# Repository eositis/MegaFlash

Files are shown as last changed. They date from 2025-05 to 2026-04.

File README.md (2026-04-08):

# MegaFlash for Apple IIc/IIc+

MegaFlash is an internal storage device for Apple IIc/IIc plus computer.

MegaFlash-New

## Feature List

- 128MB/256MB Capacity, divided into 4/8 ProDOS Drives
- 256kB RAM Disk on Pico 2 (RP2350); 140kB on Pico W (RP2040)
- ROM Disk for Disaster Recovery
- 256kB Slinky Emulation on stock firmware
- Boot Menu (Similar to ROM4X/5X)
- Control Panel
- Real Time Clock with ProDOS clock driver
- Network Time Sync (NTP Client)
- Upload/Download ProDOS Image file via WIFI and TFTP Server
- Upload/Download ProDOS Image file via XModem and USB serial port
- FPU for Applesoft BASIC
- Bug fixes of System ROM and Applesoft

A brief [user guide](https://github.com/eositis/MegaFlash/blob/main/MegaFlash%20for%20a2s4000%20installation%20guide.pdf) is available for more information.

## Requirement
- Apple IIc computer with Memory Expansion Card connector or
- Apple IIc plus computer

System ROM replacement is required for MegaFlash to function.

## Hardware
The hardware is quite simple.  All the hard work is handled by Pi Pico.  Apple 65C02 CPU only needs to copy data between RAM and Pico. Schematic is available [here](./kicad/rev1.0/schematic-rev1.0.pdf).

- Raspberry Pi Pico2 W
- Winbond 25Q01 NOR Flash memory
- GAL16V8 PLD for address decode
- 5V to 3.3V Logic Level Shifter

## Project Directories

There are 3 software projects. There is not enough space in Apple ROM to store the Control Panel program.  The program is stored in Pico flash memory. 

`firmware` Project Directory of Apple ROM Patches\
`cpanel` Control Panel project\
`pico` Raspberry Pi Pico firmware\
`common` Common header files used by all 3 projects

## Sponsorship

MegaFlash development for commercial sale has been partly sponsored by PCBway. Preparing products for commercial release is expensive, often requiring board respins to resolve manufacturing and logistics issues. PCBway production and delivery are fast and efficient, helping compress the go-to market timeline. Many thanks!

<a href="https://www.pcbway.com">
  <p align="center">
  
</a>

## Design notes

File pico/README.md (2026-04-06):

# Pico Firmware

## Build environment

For full requirements (SDK, ARM toolchain, CMake, Control Panel prerequisite, and how to recreate the build on another machine), see **[BUILD-REQUIREMENTS.md](BUILD-REQUIREMENTS.md)**.

Summary: clone [pico-sdk](https://github.com/raspberrypi/pico-sdk) to **`~/pico-sdk`** (or set **`PICO_SDK_PATH`**). On **Apple Silicon**, install **arm64** CMake (e.g. Homebrew **`/opt/homebrew`**); **`build-env.sh`** picks that **`cmake`** before **`/usr/local`**. From the MegaFlash `pico` directory run:

```
./cmakeall.sh
```

To **build both boards** (Pico W + Pico 2 W Release) **without** bumping the firmware version in `defines.h` (e.g. CI or a quick compile check):

```
./build-both.sh
```

To build **Debug** UF2s for both boards (UART 115200, `[u2]` W5100 trace + **`[u2m]`** U2 activity monitor: every `$C0C4–$C0C7` bus cycle, socket commands, and lwIP RX/TX). Run **`./cmakeall.sh` once** so `pico_debug` / `pico2_debug` exist, then:

```
./build-debug.sh
```

Capture serial and filter on `grep u2m` (or `[u2m]`) to follow the queue-drained monitor lines. Heavy traffic can fill the 128-entry ring; the firmware prints a **dropped** warning if events were lost.

Each run passes **`FIRMWARE_BUILD_TIMESTAMP`** (Unix seconds) and **`FIRMWARE_BUILD_TIMESTAMP_STR`** (UTC, e.g. `2026-03-21 12:34:56 UTC`) into CMake; **`build_id.h`** is generated with both. The UF2 embeds Unix time in device info / `CMD_GETFIRMWAREVER` bytes 12–15 and shows the human-readable string in the USB device-info text (and Debug UART). Override either variable before running if needed.
If everything is correct, the following sub-directories should be created.

```
pico_debug
pico_release
pico2_debug
pico2_release
picotool
```

Note: You need to execute the shell script only once unless `CMakeLists.txt` file is changed or you want to recreate the build directories.

`pico_debug` and `pico_release` are the build directories for Pico Board (RP2040).  `pico2_debug` and `pico2_release` are the build directories for Pico2 Board (RP2350).

## Datasheets (flash and related parts)

Vendor PDFs (e.g. Winbond, Alliance) for SPI flash and related ICs live in the **MegaFlash repo root**, next to `pico/`:

- From this directory: **`../datasheets/`** (i.e. `MegaFlash/datasheets/`).

That folder is for human reference when comparing command sets, SFDP, and status-register layouts with what `flash.c` assumes.

## Build Instruction

Before compiling the pico firmware, the control panel must be built first. Please follow the instruction in `cpanel` directory to build the control panel binary.

To build the pico firmware, go to one of the build directory e.g. `pico2_release`. Then, execute `make`. The output file is `megaflash.uf2`.

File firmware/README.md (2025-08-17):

# Apple Firmware Patches

MegaFlash is an internal storage device for Apple IIc/IIc plus computer.  Unlike Apple IIe, address $C100-$CFFF is solely used by internal ROM only.  The only way to make MegaFlash work is to patch the system ROM directly.

The virtual slot of Apple IIc is assigned as follows.  

```
Slot 1 - Serial Port 1
Slot 2 - Serial Port 2
Slot 3 - 80 Column Display
Slot 4 - Apple Memory Expansion Card (aka Slinky)
Slot 5 - 3.5" floppy drive/external Smartport
Slot 6 - 5.25" floppy drive
Slot 7 - Mouse
```

MegaFlash needs to reside in one of the virtual slots. Since MegaFlash is plugged into the Memory Expansion slot, slot 4 is the obvious choice. The Memory Expansion card firmware is removed and replaced by our codes.

## Build Environment

The project is built on Linux with CA65 assembler (part of CC65 compiler toolchain).  Follow [the instruction](https://cc65.github.io/getting-started.html) to compile CC65. Make sure to add cc65 binaries directory to PATH variable by running 

```sudo make avail```

## Original ROM files

Original ROM image files for Apple IIc and IIc plus are needed.  For Apple IIc, ROM Version 4 is needed.  There is only one ROM release (Version 5) for Apple IIc plus. The ROM files can be downloaded from Internet. Name the files `rom4.bin` and `rom5.bin` respectively and put them to the source directory.

## Build Instruction

Execute `make` to build the project.

## Build Targets

There are two build targets, `a2c` and `a2cp`.

Target `a2c` is for Apple IIc. The output file is `iic.bin`. Target `a2cp` is for Apple IIc plus. The output file is `iicplus.bin`.

The linker of CC65 is capable of patching a binary file. So, no additional tools are needed to generate the output files.

## Development Guide
The makefile generates the output files in two steps. Step 1 generates the new binary codes. Step 2 merges the new codes to the original ROM files.

### Step 1 Code Generation

To add a new code segment, you need to edit `iic.cfg` and `iicplus.cfg` files. A new segment and a new output file should be added.  The naming of segments and output files is same as ROM4X project. i.e. `B0_C123` means address $C123 at ROM Bank 0.

### Step 2 Patching the ROM files

To incorporate the new codes to the ROM files, you need to edit `merge_iic.cfg` and `merge_iic.s` files (`merge_iicp.cfg` and `merge_iicp.s` for Apple IIc plus).

`merge_iic.cfg` tells the linker the address of code segment. `merge_iic.s` uses `.incbin` directive command to include the binary code file.

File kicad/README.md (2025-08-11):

# MegaFlash PCB

Currently, there are two PCB revisions, 1.0 and 1.1. They are functionally identical. 

Rev 1.0 board is more compact. It is optimized for machine assembly.

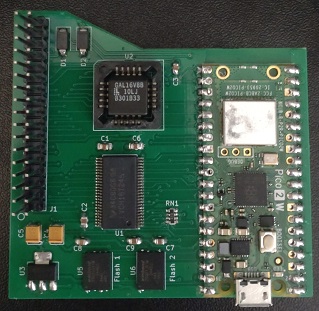
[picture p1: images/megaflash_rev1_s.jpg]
Image of MegaFlash PCB Rev 1


Rev 1.1 board is bigger. It is designed for hand assembly.  The components are either through hole or 1.27mm pitch SOICs. 

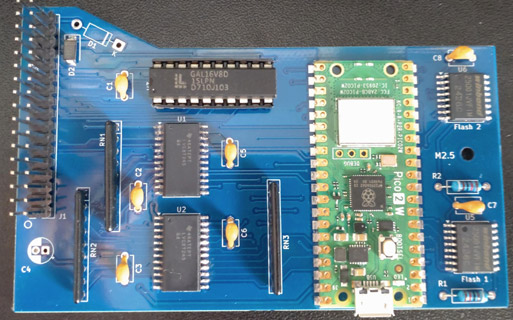
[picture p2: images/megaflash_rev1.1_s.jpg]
Image of MegaFlash PCB Rev 1.1


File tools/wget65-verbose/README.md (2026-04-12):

# WGET65V — verbose `wget65` (ip65 fork)

Fork of [cc65/ip65 `apps/wget65.c`](https://github.com/cc65/ip65/tree/main/apps) with **on-screen** logging of the Uthernet II / W5100 bring-up path:

- **Step A:** `ip65_init()` (includes stock `w5100.s` RTR XOR probe)
- **Step B:** `w5100_init()` (port mapping + virtual DNS offload hint via PTIMER)
- **Step C:** `dhcp_init()` when DNS offload is off
- **Step D:** `w5100_config()`

After each major step, the program prints a **register snapshot**: Mode register read, RTR0/RTR1 at `$0017/$0018` with the same **XOR chain** ip65 uses (`$D7 ^ RTR0 ^ RTR1` should be `$00` when the probe passes), plus RMSR and PTIMER.

Upstream **ip65** sources are **not** modified in this repo (policy: stock drivers). Only this directory adds the forked client and `wget65_verbose_regs.c`.

**Slot:** **`WGET65V_ETHER_SLOT`** is **4** (MegaFlash Uthernet II at **`$C0C4`–`$C0C7`**). This fork does **not** read **`ethernet.slot`**; stock **`wget65`** still can.

On **Apple II**, **`main()`** calls **`videomode(VIDEOMODE_80COL)`** (same idea as **`hfs65.c`**) so handshake / register dumps use **80 columns** and do not wrap as badly as in 40-column mode.

## Prerequisites

- [cc65](https://cc65.github.io/) (`cl65` on `PATH`)
- A clone of **ip65** at **`MegaFlash/ip65`** (i.e. `../../ip65` from this directory), **or** set **`IP65_ROOT`** to your checkout:

  ```bash
  git clone https://github.com/cc65/ip65.git ../../ip65
  ```

## Build

```bash
cd tools/wget65-verbose
make
```

This builds **`wget65v.bin`** (gitignored). Override the ip65 path:

```bash
make IP65_ROOT=/path/to/ip65
```

## Flash validation disk

If **`tools/wget65-verbose/wget65v.bin`** exists when you run `tools/flash-validate/build-flashval-disk.sh` (default **`WGET65V_BIN`** = **`../wget65-verbose/wget65v.bin`** from **`flash-validate/`**), the script also adds **`WGET65V`**, **`WGET65V.SYSTEM`** (cc65 loader), **`WGET65V`** (Applesoft launcher), **`WGET65V.SRC`**, and **`WGET65V.DOC`**. If the binary is not built, only **`WGET65V.DOC`** is added with build instructions.

Set **`CC65_HOME`** if `cl65` is not on `PATH` but the cc65 share directory is known (the script uses `cl65 --print-target-path` / `apple2enh/util/loader.system`).

## License

Original `wget65` / `w5100` / `linenoise` sources retain the upstream ip65 licenses. Additions in `wget65_verbose_regs.*` follow the MegaFlash project’s contribution terms.

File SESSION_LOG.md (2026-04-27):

# Session activity log

This project’s local log. One log per project; stored in the project root.

---

## 2026-04-26

- **Release-notes sanity pass + correction:** Reviewed generated `pico/_releases/V1.2.1-eo/CHANGELOG.md` and found it was stale (older NetworkPump/TFTP-era text not matching current Uthernet-focused changes). Rewrote `V1.2.1-eo` changelog and synced `pico/CHANGELOG-NEXT.md` to accurately describe shipped Uthernet TX-pointer decode fix, MACRAW length-prefix fix, DHCP payload rewrite rollback, and core-affinity/diagnostic improvements.

- **Pico 1.2-series release build:** Ran `./pico/cmakeall.sh` to perform versioned release build packaging; build completed as `V1.2.1-eo (0x0021)` with release outputs in `pico/_releases/V1.2.1-eo/` (`megaflash-pico.uf2`, `megaflash-pico2.uf2`, `CHANGELOG.md`).

- **Packaged patched `ADTPROETH.BIN` into ProDOS images:** Rebuilt base ADTPro ProDOS disk images (`prodos-adtpro-image-prep`) and manually inserted `/Users/eositis/Documents/GitHub/adtpro/src/client/ADTPROETH.BIN` using AppleCommander into `adtpro/build/ADTPro-v.r.m/disks/ADTPRO-v.r.m.DSK` and `.PO` as `ADTPROETH.BIN` (BIN, load address 2048). Verified with `-ls` that both images now contain `ADTPROETH.BIN` (19,121 bytes).

- **Forced ADTPro Ethernet slot 4 in local `adtpro` repo + built client binary:** Updated `/Users/eositis/Documents/GitHub/adtpro/src/client/prodos/ethernet/ethconfig.asm` to bypass `FindSlot` in `PARMDFT` and hard-set `COMMSLOT=3` (slot 4), with defaults aligned (`COMMSLOT`/`DEFAULT` changed from 2→3). Built with `JAVA_HOME=/opt/homebrew/opt/openjdk ant -DassemblerPath=/opt/homebrew/bin prodos-ethernet`; Ant later failed on missing custom `appleDump` task, but `src/client/ADTPROETH.BIN` and `src/client/adtproeth.map` were successfully generated.

- **ADTPro pre-init crash follow-up (bus-access visibility build):** Since `debug/uart_log.txt` with `U2_IP65_CHECKPOINT=1` still showed no `ck=1` or socket events, built a stricter diagnostic image with bus logging enabled to verify whether ADTPro issues any `$C0C4-$C0C7` accesses before `system-$01`: `U2_ETH_HEADER_TRACE=1 U2_IP65_TRACE_DATA=0 U2_IP65_CHECKPOINT=1 U2_MON_LOG_BUS=1 ./pico/build-debug-both.sh`.

- **ADTPro `system-$01` log triage + checkpoint bisect build:** Reviewed refreshed `debug/uart_log.txt` from `Firmware build: 2026-04-27 01:00:59 UTC`; failure window shows ambient RX traffic but no U2 socket/checkpoint activity (`sock0 OPEN/SEND/RECV` absent), so crash likely occurs before W5100 init/handoff in that run. Built targeted debug image with `U2_ETH_HEADER_TRACE=1 U2_IP65_TRACE_DATA=0 U2_IP65_CHECKPOINT=1 U2_MON_LOG_BUS=0 ./pico/build-debug-both.sh` to confirm whether ADTPro reaches first mode write.

- **ADTPro DHCP-compatibility experiment (disable BOOTP payload rewrite):** With latest debug showing repeated DHCP offers arriving (`67->68`) but client still failing, changed `pico/uthernet2_net.cpp` to stop rewriting BOOTP/DHCP payload fields (`chaddr`/option 61/checksum) and only rewrite Ethernet SA to STA MAC. Goal: avoid client-side DHCP validation mismatch in ADTPro/ip65 while preserving WiFi egress compatibility. Rebuilt with `U2_ETH_HEADER_TRACE=1 U2_IP65_TRACE_DATA=0 U2_IP65_CHECKPOINT=0 U2_MON_LOG_BUS=0 ./pico/build-debug-both.sh`; lints clean.

- **MACRAW RX length-field compatibility fix:** With DHCP offers (`67->68`) visible in `[u2eth] RX` and `net sock0 MACRAW rx len=342` present but ip65 still timing out, updated `pico/uthernet2.c` `u2_push_rx_macraw()` to write length prefix as `len+2` (W5100 MACRAW wire convention used by many drivers) instead of raw `len`. Rebuilt with `U2_ETH_HEADER_TRACE=1 U2_IP65_TRACE_DATA=0 U2_IP65_CHECKPOINT=0 U2_MON_LOG_BUS=0 ./pico/build-debug-both.sh`; lints clean.

- **DHCP MACRAW rewrite hardening:** Updated `pico/uthernet2_net.cpp` DHCP patch path to also rewrite DHCP option 61 (client-id MAC) in addition to BOOTP `chaddr`, and set IPv4 UDP checksum to zero (valid/no-checksum) after mutation to avoid checksum-recompute incompatibilities. Rebuilt with `U2_ETH_HEADER_TRACE=1 U2_IP65_TRACE_DATA=0 U2_IP65_CHECKPOINT=0 U2_MON_LOG_BUS=0 ./pico/build-debug-both.sh`; lints clean.

- **U2 root-cause fix for malformed MACRAW TX:** In `pico/uthernet2.c` `read_socket_register()`, reads of `SN_TX_RD0/1` and `SN_TX_WR0/1` were incorrectly falling through the `RX_RSR0` handler and returning RX-RSR bytes. Fixed these cases to return `u2_memory[address]` (actual TX pointer registers). This explains `MACRAW ptrs len=257/514` and shifted payload starts in `[u2tap]`. Rebuilt with `U2_ETH_HEADER_TRACE=1 U2_IP65_TRACE_DATA=0 U2_IP65_CHECKPOINT=0 U2_MON_LOG_BUS=0 ./pico/build-debug-both.sh`; lints clean.

- **Added MACRAW SEND pointer trace event:** Extended `pico/u2_monitor.{h,c}` with `U2_MonNetMacrawTxPtrs` and wired it in `pico/uthernet2.c` `send_data()` (MACRAW branch) to log `len`, `rd_full`, `wr_full`, and masked `rd/wr` per SEND without unsafe core1 printf. Rebuilt with `U2_ETH_HEADER_TRACE=1 U2_IP65_TRACE_DATA=0 U2_IP65_CHECKPOINT=0 U2_MON_LOG_BUS=0 ./pico/build-debug-both.sh`; lints clean.

- **U2 MACRAW TX corruption fix (`Sn_TX_RD` full progression):** From `[u2tap]` logs, malformed `len=257/514` packets were already wrong at queue drain, so issue was pre-core0 patching. In `pico/uthernet2.c` `send_data()`, preserved full `Sn_TX_WR` (`wr_full`) for `Sn_TX_RD` register update after SEND while keeping masked pointers only for ring indexing/copy. Rebuilt with `U2_ETH_HEADER_TRACE=1 U2_IP65_TRACE_DATA=0 U2_IP65_CHECKPOINT=0 U2_MON_LOG_BUS=0 ./pico/build-debug-both.sh`; lints clean.

- **U2 MACRAW TX tap instrumentation:** Added core-0-only `[u2tap]` traces in `pico/uthernet2_net.cpp` at `drain`, `core0-pre`, and `core0-post` stages (for DHCP-sized frames) to locate where shifted/malformed `tot_len=257` frames appear. Rebuilt with `U2_ETH_HEADER_TRACE=1 U2_IP65_TRACE_DATA=0 U2_IP65_CHECKPOINT=0 U2_MON_LOG_BUS=0 ./pico/build-debug-both.sh`; lints clean.

- **Rebuilt known-good U2 debug profile:** Rebuilt with `U2_ETH_HEADER_TRACE=1 U2_IP65_TRACE_DATA=0 U2_IP65_CHECKPOINT=0 U2_MON_LOG_BUS=0 ./pico/build-debug-both.sh` to restore the earlier “ip65 recognizes Uthernet, but DHCP/data path still problematic” baseline; this avoids the later high-noise profile that changed runtime behavior during init checks.

- **U2 regression triage + rollback (ip65 “device not found”):** Reviewed latest `send_data()` TX-pointer change in `pico/uthernet2.c` and identified root cause as inconsistent pointer semantics (full 16-bit SEND math vs masked-ring `get_tx_data_size`/TX_FSR path). Reverted `send_data()` to masked-ring logic, rebuilt with `./pico/build-debug-both.sh`, and updated implementation notes §1l to record the failed attempt and rationale.

- **U2 DHCP timeout follow-up (MACRAW TX pointer fix):** Updated `pico/uthernet2.c` `send_data()` to keep full 16-bit `Sn_TX_RD/Sn_TX_WR` for queued-length math and mask only during ring indexing; this avoids wrap-related malformed/zero-heavy MACRAW frames seen in `[u2eth]` and is intended to restore clean DHCP request framing. Rebuilt with `./pico/build-debug-both.sh`; lints clean on edited code.

## 2026-04-10

- **Post-fix `uart_log` analysis (no code change):** New capture shows no `PANIC` / `async_context_poll` errors after launch; MACRAW send/recv continues under load, indicating core-affinity crash is resolved. Noted a remaining behavior to investigate: some `[u2eth] TX` frames show zeroed/abnormal headers at larger lengths (e.g., 514/771/1518), suggesting a possible separate payload/format issue unrelated to the prior crash.

- **U2 panic follow-up (latest `uart_log`):** Panic still occurred on first MACRAW SEND after core0 poll guard. Root cause was `U2_Net_SendMacraw()` entering `cyw43_arch_lwip_*` from bus/core1. `pico/uthernet2_net.cpp` now defers MACRAW TX to a core0-drained queue in `U2_Net_Poll`; rebuilt Debug with `U2_ETH_HEADER_TRACE=1 U2_IP65_TRACE_DATA=0 U2_IP65_CHECKPOINT=0 U2_MON_LOG_BUS=0`; lints clean.

- **U2 crash fix (wrong-core async_context):** `debug/uart_log.txt` panic (`async_context_poll ... wrong core`) traced to `U2_Poll` (core1) calling `U2_Net_Poll` → `NetworkPump_PollOnce`. Fixed by making `U2_Net_Poll` core-0-only (`get_core_num()` guard) and calling it from `main.c` `PicoW_ServiceCore0IpcAndNetwork` (core0 path). Rebuilt with `U2_ETH_HEADER_TRACE=1 U2_IP65_TRACE_DATA=0 U2_IP65_CHECKPOINT=0 U2_MON_LOG_BUS=0 ./pico/build-debug-both.sh`; lints clean. Documented rationale in `docs/Implementation-notes-and-reasoning.md` §1k + summary table row update.

- **Crash log triage (`debug/uart_log.txt`, no code change):** Panic signature `async_context_poll context check failed (IRQ or wrong core)` reproduced in capture; likely trigger is U2 network poll path running `NetworkPump_PollOnce()` from `U2_Poll` (bus/core1), which conflicts with CYW43/lwIP core affinity expected on core0. Capture also confirms `[u2eth]` traffic trace is working but Debug still emits `[u2m]`.

- **Reviewed `debug/uart_log.txt` capture:** Confirmed `[u2eth]` TX/RX header trace is active and producing MACRAW traffic lines, but `[u2m]` monitor lines are also present in Debug builds and the log still shows an `async_context_poll context check failed` panic during early activity; for strictly header-only runtime noise, prefer Release with `U2_ETH_HEADER_TRACE=1`.

- **Debug build (U2 TX/RX header-only):** Ran `U2_ETH_HEADER_TRACE=1 U2_IP65_TRACE_DATA=0 U2_IP65_CHECKPOINT=0 U2_MON_LOG_BUS=0 ./pico/build-debug-both.sh` to produce low-noise Uthernet traffic tracing (`[u2eth]` only, without bus/data/checkpoint flood). Outputs refreshed: `pico/pico_debug/megaflash.uf2`, `pico/pico2_debug/megaflash.uf2`.

- **U2 debug-scope check (no code change):** Verified current trace knobs in `pico/CMakeLists.txt` / `build-debug*.sh` and `uthernet2_net.cpp`: minimal Uthernet-only traffic capture is `U2_ETH_HEADER_TRACE=1` with `U2_MON_LOG_BUS=0`, `U2_IP65_TRACE_DATA=0`, `U2_IP65_CHECKPOINT=0` to avoid bus/checkpoint/data flood.

- **U2 summary table alignment:** Updated `docs/Implementation-notes-and-reasoning.md` §11 to match current U2 state (RECV now preserves unread bytes per §10h) and added a row noting §12 open-item scope now excludes slot decode (confirmed working).

- **U2 open-items cleanup:** Updated `docs/Implementation-notes-and-reasoning.md` §12 to reflect user-confirmed slot decode correctness; removed "confirm slot" from remaining debug steps and narrowed unresolved causes to nDEVSEL signal/timing vs PIO/FIFO/CPU path.

- **Uthernet status recap (no code change):** Reviewed `SESSION_LOG.md` + `docs/Implementation-notes-and-reasoning.md` (§10f–§10i, §12) to summarize latest U2 emulation state and pending validation/debug items; key outcome is that `wget65`-priority RX/TX fixes and TCP backpressure fix are in, with bench verification still needed for remaining hardware-path uncertainty.

- **U2 hot path RAM:** **`pico/uthernet2.c`**, **`pico/busloop.c`**; **`./build-both.sh`** OK.

- **DHCP/MACRAW STA MAC:** **`pico/uthernet2.c`**, **`uthernet2_net.cpp`**, **`uthernet2.h`** — §1j.

- **Drop C0C4 LED:** **`pico/busloop.c`**; docs §9.

- **§1i:** Clarified same PIO read path for **`$C0C0–$C0C3`** and **`$C0C4–$C0C7`** (no special U2 Φ2); U2-specific issues are **pipeline**/handler. **`docs/Implementation-notes-and-reasoning.md`**.

- **AppleWin vs MegaFlash U2:** Documented in **`docs/Implementation-notes-and-reasoning.md`** §**1i** and **`docs/Uthernet-II-emulation-on-MegaFlash.md`** (timing: **`IO_C0`** / **`MemReadFloatingBus`**; decode: **`&0x03`** mirrors vs **`$C0C4–$C0C7`** + PIO chunks).

- **`pico/build-both.sh`:** Built **`pico_release/megaflash.uf2`** and **`pico2_release/megaflash.uf2`** (Arm GNU Toolchain 15.2 under **`/Applications/ArmGNUToolchain`**).

- **`pico/a2bus_rp2350.pio` + `pico/a2bus.h`:** Tighter **read_cycle** delays before **`mov osr,rxfifo[y]`** so bus data is presented earlier; **`__dsb`** after **`rxf_putget`** store. Documented §1d.

- **`tools/wget65-verbose/wget65.c`:** On **`ip65_init`** failure, print **`ip65_error`** + note re post-failure dump vs **`w5100.s`** probe (§1h paradox); fixed **slot 4**; **`videomode(VIDEOMODE_80COL)`**; rebuilt **`wget65v.bin`** / **`FLASHVALID.po`**.
- **`tools/wget65-verbose/` + flash disk:** Shallow **`ip65/`** clone at repo root (gitignored) for cc65; **`WGET65V_BIN`** default in **`build-flashval-disk.sh`** fixed to **`../wget65-verbose/wget65v.bin`**. Built **`wget65v.bin`**, regenerated **`FLASHVALID.po`** with **WGET65V** + **WGET65V.SYSTEM** + launcher + **WGET65V.DOC**. See **`docs/Implementation-notes-and-reasoning.md`** §1h.

## 2026-04-07

- **FLASHVALID.po:** Dropped **`CPANEL`** **`BIN`**; added standalone **`TFTPUTIL`** (**`TFTPUTIL.BAS`** → tokenized + **`TFTPUTIL.SRC`**) for TFTP upload/download only. **`build-flashval-disk.sh`**, **`README.md`**, §17.

- **FLASHSOAK on-screen progress:** **`GOSUB 8600`** status line **VTAB 21** for major steps (cycle/unit, format, files, checksum block **/256**, TFTP poll **/50**, failures, cycle end, reformat). **`tools/flash-validate/FLASHSOAK.BAS`**, **`README.md`**.

- **FLASHSOAK log file name:** Default log **`SOAK.TXT`** (ProDOS **TEXT** **SEQ**); comma-separated lines unchanged; **`.CSV`** avoided for **`OPEN`**,**`T`** reliability. **`tools/flash-validate/FLASHSOAK.BAS`**, **`README.md`**, §18.

- **FLASHSOAK append-only log + timestamps:** No **`DELETE`** of the log file; each run appends **`RUN_START`** after **`CMD_GETTIMESTR`** (**`QC=25`**) timestamp column **`TS$`**. CSV columns **`ts,cycle,unit,event,result,v1,v2`**; new file **`OPEN`** **`T,W`** writes header then row. **`tools/flash-validate/FLASHSOAK.BAS`**.

- **FLASHSOAK PATH NOT FOUND at 9010:** **`DELETE`** on init failed when **`SOAK.CSV`** did not exist yet. **`ONERR GOTO`** around **`DELETE`**, then **`ONERR GOTO 0`** before **`OPEN`** (same pattern as **`FLASHVAL`** file I/O). **`tools/flash-validate/FLASHSOAK.BAS`**.

- **FLASHSOAK syntax error at 9020:** Applesoft tokenizes **`OPEN`**, **`WRITE`**, **`CLOSE`**, **`DELETE`**, **`PREFIX`** in **`PRINT D$;"OPEN "...`**-style lines; **`FLASHVAL.BAS`** already used **`"O"+"PEN"`** / **`"WR"+"ITE"`** etc. **`FLASHSOAK.BAS`** applied the same pattern (incl. **`LG$`** log path) so ProDOS commands are built from string concatenation. **`tools/flash-validate/FLASHSOAK.BAS`**.

- **WiFi / Test WiFi broken after CYW43 LED init:** **`misc.c` `InitPicoLed()`** calls **`cyw43_arch_init()`**; **`CUDPTask::InitCyw43()`** / **`NetworkPump::Init()`** then called **`cyw43_arch_init_with_country()`**, which re-entered **`cyw43_arch_init()`** → second **`cyw43_driver_init()`** failed and **`cyw43_arch_deinit()`** tore down the stack (pico-sdk **`cyw43_arch_poll.c`**). **Fix:** if **`cyw43_is_initialized(&cyw43_state)`**, only **`cyw43_arch_enable_sta_mode()`** + LED; skip re-init. **`pico/udptask.cpp`**, **`pico/network_pump.cpp`**. **`./build-both.sh`** OK. **`docs/Implementation-notes-and-reasoning.md`** §7k.

- **Release: USB vs Apple II bus mutual exclusion:** **`NDEBUG`** only — **`g_release_bus_emulation_enabled`** = Apple connected **and** USB not connected to host; **`ReleaseUpdateBusUsbGate()`** in **`misc.c`**; **`GetAppleBusBlocking()`** in **`a2bus.h`** spins without FIFO when bus off; **`main.c`** **`stdio_usb_init()`** before **`core0Loop()`**; USB terminal only when **`!IsAppleConnected()`**. Debug builds unchanged. **`./build-both.sh`** OK. **`docs/Implementation-notes-and-reasoning.md`** §7j.

- **Pico W WiFi / Test WiFi hang:** **`pico/main.c`** — when **`IsAppleConnected()`** is false at boot, **`core0Loop()`** was skipped so **`multicore_fifo`** (**`IPCCMD_WIFITEST`**, TFTP) and **`NetworkPump_PollOnce()`** never ran; Control Panel Test WiFi waited forever and CYW43 stayed idle. Added **`PicoW_ServiceCore0IpcAndNetwork()`** (shared with **`core0Loop`**); USB-terminal path polls FIFO + lwIP non-blocking each loop and during 1 s idle (**1 ms** sleeps). **`./build-both.sh`** OK. **`docs/Implementation-notes-and-reasoning.md`** §7i.

- **Build:** **`firmware`**: **`make clean && make`** → **`iic.bin`** + **`iicplus.bin`**. **`pico`**: **`./build-both.sh`** → **`pico_release/megaflash.uf2`**, **`pico2_release/megaflash.uf2`**.

- **Alliance JEDEC `0x204020`:** **`pico/flash.c`** — **`tsReadJEDECID()`** masks to **24-bit** RDID and uses **`uint32_t`** shifts; **`ChipIDToCapacity()`** masks **`jedec24`**, explicit **`0x204020`** (Alliance 512 Mbit, Thomas), keeps **`type_cap`** Winbond-class matching. **`./pico/build-both.sh`** OK. **`docs/Implementation-notes-and-reasoning.md`** §16.

- **FLASHVALID disk image:** Rebuilt using **`../a2speed`**-style **`make disk`** flow: **`-pro140`**, **`SYS_SRC=cpanel/prodos19.dsk`** for **PRODOS**/**BASIC.SYSTEM** (no padded 800K **`romdisk.po`**). Added **`tools/flash-validate/Makefile`**. Updated **`README.md`** + **`docs/Implementation-notes-and-reasoning.md`** §17/§18.
- **FLASHVALID.po:** Default build output is **`tools/flash-validate/FLASHVALID.po`** (same **`.po`** convention as **`../a2speed/a2speed.po`**, not **`.dsk`**). Rebuilt; AppleCommander **`-i`** confirms **143360** bytes, ProDOS, **280** blocks.

## 2026-04-03

- **FLASHSOAK unit count + status line + log notes:** **`UC`** was wrongly **`BC`** from **`CMD_GETUNITSTATUS`** with **`U=0`**; now **`GOSUB 1450`** **`CMD_GETDEVSTATUS`** (**`QC=17`**) and cap **`UC`≤16**. **`GOSUB 8600`** uses **`LEFT$(M$+B$,40)`** to clear line 21. **`README.md`** / §18: log stall workarounds.

- **FLASHSOAK NONE still reached OPENING / LGSKIP useless:** Applesoft variable names are significant to **two characters**; **`LGSKIP`** and **`LGINIT`** both alias **`LG`**, so **`NONE`** could not reliably skip **`GOSUB 9000`**, and **`LGINIT=1`** made **`LGSKIP`** look set. Replaced with **`Q1`** (skip) and **`Q2`** (log opened); accept **`none`** lowercase. **`tools/flash-validate/FLASHSOAK.BAS`**, **`README.md`**, §18.

- **FLASHSOAK still hung before LOG STARTED:** Log **`OPEN`** moved to **start of cycle 1** (after **PROGRESS** line); **`OPENING …`** on **VTAB 21** before MLI; **`NONE`** disables log file; **`OPEN`/`WRITE`** match **`FLASHVAL.BAS`**; **`TIME$`** truncate before pad. **`tools/flash-validate/FLASHSOAK.BAS`**, **`README.md`**, §18.

- **FLASHSOAK hang after SERVER / no SOAK.TXT:** Startup **`CMD $03`** and log timestamps via **`CMD $19`** ran (or blocked) before **`OPEN`**; a stuck busy wait prevented **`GOSUB 9000`**. **Fix:** **`GOSUB 9000`** immediately after printing **`SERVER`**; **`ts`** column from ProDOS **`TIME$`** (8 chars), not **`CMD_GETTIMESTR`**. **`tools/flash-validate/FLASHSOAK.BAS`**, **`README.md`**, §18.

---

## 2026-04-08

- **Uthernet/Telnet65 walkthrough (no code change):** Performed a logical end-to-end review of Telnet65 over Uthernet emulation (ip65 init, MACRAW DHCP, TCP connect/send/recv) and documented risks in `docs/Implementation-notes-and-reasoning.md` §10f. Key findings: TX empty-send wrap condition, chained `pbuf` assumptions in UDP/TCP RX, intentionally lossy RECV behavior, and possible nested lwIP lock in `U2_Net_OpenUdp`.
- **Uthernet/Telnet65 fixes implemented:** Applied the proposed fixes: `pico/uthernet2.c` `send_data()` now wraps only on negative `wr-rd` (prevents empty TX from sending full-buffer stale data); `pico/uthernet2_net.cpp` now flattens UDP/TCP pbuf chains via `pbuf_copy_partial` before `push_rx_cb`; removed outer `cyw43_arch_lwip_begin/end` in `U2_Net_OpenUdp` because `NetworkPump::CreateUdpPcb` already locks. Verification: `./pico/build-both.sh` succeeded for `pico_release` and `pico2_release`; `ReadLints` clean on edited files.
- **Retest (logical Telnet65 flow):** Re-checked init/DHCP/TCP flow against updated code paths (`send_data`, UDP/TCP RX callback flattening, busloop U2 poll cadence/chunk update). Result: previously identified high-risk issues are resolved in code; no new blockers found in walkthrough. Residual note: RECV still intentionally advances `RX_RD` to `sn_rx_wr` (ip65 compatibility, potentially lossy for partial-read clients).
- **ip65 tools walkthrough (`date65`/`tweet65`/`hfs65`/`wget65`):** Reviewed sibling `ip65/apps` usage patterns vs current Uthernet emulation and documented in `docs/Implementation-notes-and-reasoning.md` §10g. Main findings: RECV semantics (`RX_RD -> sn_rx_wr`) likely break W5100 shared-access partial commits (`wget65`), TCP RX can drop on full emulated RX ring while still calling `tcp_recved()` (risking silent data loss under bulk traffic), and SEND path currently stages max 2048 bytes per command.
- **`wget65`-priority U2 fixes:** Updated `pico/uthernet2.c` so SN_CR=RECV no longer forces `RX_RD` to `sn_rx_wr` (preserves unread tail bytes for shared-access partial commits), and TCP SEND now drains full queued TX data in 1 KiB chunks per SEND command (removes prior 2 KiB cap). Build verification: `./pico/build-both.sh` successful for both release targets; lints clean. Documented in `docs/Implementation-notes-and-reasoning.md` §10h.
- **`wget65` focused retest (logical):** Revalidated shared-access flow against current code (`w5100_data_request`/`w5100_data_commit` expectations vs U2 `SN_CR_RECV` and SEND). Confirmed the two priority fixes are present and aligned with partial-commit semantics. Residual risk remains: TCP RX path still calls `tcp_recved()` even if emulated RX push drops due to full ring (possible silent loss under sustained large transfers).
- **TCP RX backpressure fix (`wget65`/bulk TCP):** Implemented accepted-byte accounting in U2 RX callback path: `u2_push_rx_fn` now returns accepted payload bytes; `u2_push_rx` allows partial TCP enqueue based on RX free space (UDP remains atomic), and `u2_tcp_recv` calls `tcp_recved()` only for accepted bytes. Built both release targets via `./pico/build-both.sh`; `ReadLints` clean.

## 2026-04-06

- **Overnight soak validator:** Added **`tools/flash-validate/FLASHSOAK.BAS`** to stress writable MegaFlash units (incl. RAM disk), with cycle loop: format, file create/append/delete/fill, whole-volume checksum, TFTP upload/download (`validationX.po` on `192.168.0.10`), checksum compare, comma-separated log to **`SOAK.TXT`**, and auto-repeat on pass.
- **Disk build integration:** Updated **`tools/flash-validate/build-flashval-disk.sh`** + docs so **`FLASHVALID.po`** includes tokenized **`FLASHSOAK`** and text **`FLASHSOAK.SRC`**; rebuilt and verified directory contents with AppleCommander.
- **Reasoning/docs:** Extended **`docs/Implementation-notes-and-reasoning.md`** with §18 and summary-row update to capture why soak coverage was added and the exact command/data-buffer contract used for `CMD_TFTPRUN`/`CMD_TFTPSTATUS`.

---

## 2026-04-05

- **Flash validate boot disk:** **`tools/flash-validate/build-flashval-disk.sh`** builds **`FLASHVALID.dsk`** (800K ProDOS): **PRODOS** + **BASIC.SYSTEM** from padded **`pico/romdisk.po`**, **`-bas`** **`FLASHVAL`** from **`FLASHVAL.DSK.BAS`**, **`-ptx`** **`FLASHVAL.SRC`** from full **`FLASHVAL.BAS`**. Renamed register ports **`PR`→`PX`**, **`DR`→`D1`** (**`PR`** is **`PRINT`** abbreviation; fixes AppleCommander **`Expecting: [PR, #]`**). **`docs/Implementation-notes-and-reasoning.md`** §17 + summary row.

---

## 2026-04-03

- **Thomas `fswrts` (ZIP / IIc+):** **`firmware/patches.s`** — **`$FB19`**: **`jmp slxeq`** (drop **`coldstart2`** trampoline); **`B1_FFC8`**: **`fswrts`** = **`sta rombank`** before bank-0 **`RTS`** at **`$FFCB`**. **`megaflash.s`**: **`.import fswrts`**, **`.export swjmp_ay`**, boot menu via **`ld16iay BMRUN-1` / `swjmp_ay_sp0`**, no-boot path computes **`($0000)-1`** and **`swjmp_ay`**. **`macros.inc`**: **`ld16iay`**. **`iic.cfg` / `iicplus.cfg`** + **`merge_iic*.cfg/.s`**: **`B1_FFC8`** fragment. **`make iic.bin` + `iicplus.bin`** OK. **`docs/Implementation-notes-and-reasoning.md`** §4h.

- **Thomas `smartport.s` port:** **`firmware/smartport.s`** — **`HOMESEGMENT`** (default **`ROM1`**) for relocatable segment name; **`RESTOREZPSCRATCH`** restore loop uses indexed **`sta z:zpscratch+ZPSCRATCHSIZE,x`** + **`bne`** (no **`cpx`**); **`ZPSIZE`** restore uses **`bne`** vs **`blt`**; removed IIc+ debug-segment comment block before **`DEBUG`**. Matches **`upstream/main`** SmartPort diff; **`make iic.bin iicplus.bin`** OK. **`docs/Implementation-notes-and-reasoning.md`** §4g.

- **Thomas `dmamemops` + flash SPI/security (follow-up commit):** Replaced **`pico/dmamemops.c`** with **`upstream/main`** (per-operation DMA configs, no global config save/restore). **`pico/CMakeLists.txt`**: **`OC_RP2350=1`** for **`pico2_w`**; **`pico/flash.c`**: extra **`nop`** on CS assert/deassert when **`OC_RP2350`**, and **`tsWriteSecurityRegister`** partial path programs **256** B (Thomas fix). Full upstream **`flash.c`/`flash.h`** API rename still not merged. **`docs/Implementation-notes-and-reasoning.md`** §4f.

- **Thomas storage stack (partial port):** Ported **RAM disk** dedicated DMA + **`InitRamdisk()`** (after **`InitDMAChannel()`** in **`pico/main.c`**); kept existing **`ts*`** ramdisk API names. **ROM disk** read uses **`memcpy`** like upstream (no shared **`dmamemops`** DMA); kept **`GetRomdiskFirst()`** / unit-order behaviour in **`mediaaccess.c`**. **Flash read:** **`ReadFromFlashByDMA`** → software TX + RX DMA + **timeout/abort** and **`CRC32Aligned`** fallback (**Thomas overclock/TFTP hang mitigation**). **`./pico/build-both.sh`** OK. **`docs/Implementation-notes-and-reasoning.md`** §4e.

- **ThomasFok upstream diff (storage + IIc+/Applesoft):** Compared **`main`** to **`upstream/main`** ([ThomasFok/MegaFlash](https://github.com/ThomasFok/MegaFlash)). Primary doc for side editor: **`ThomasFok-upstream-comparison.md`** (repo root); **`docs/Upstream-ThomasFok-storage-accel-comparison.md`** → pointer. **§4d** + summary row in **`docs/Implementation-notes-and-reasoning.md`**. Focus: **`fswrts`/`swjmp_ay`**, **`megaflash.s`/`patches.s`**, RAM/ROM disk + flash DMA, TFTP DOS-order **`imagewriter`**; **`firmware/accel.s`** unchanged vs upstream in diff.

- **Cross-check builds:** **`cpanel`** — **`make clean && make release`** and **`make all`** (Java/**`acx18.jar`**) OK. **`firmware`** — **`make clean && make all`** → **`iic.bin`** + **`iicplus.bin`** (32 KiB each). **`pico`** — **`romdisk.po`** present; **`./build-both.sh`** → **`pico_release/megaflash.uf2`** + **`pico2_release/megaflash.uf2`**.

- **Intel OpenJDK removal + JVM registration:** Removed **`/usr/local/Cellar/openjdk`** and **`/usr/local/opt/openjdk`** (user-owned; Intel **`brew uninstall`** fails here with x86 portable Ruby). Added **`tools/register-arm-openjdk-macos.sh`** (**`sudo ln -sfn`** Homebrew **`openjdk`** bundle → **`/Library/Java/JavaVirtualMachines/openjdk.jdk`**). Doc **§4c** + summary row in **`docs/Implementation-notes-and-reasoning.md`**. **User:** run the script locally once (**sudo**).

- **Build chain check:** **`cpanel` `make clean && make release`** OK; **`pico/build-both.sh`** OK (**`pico_release`** + **`pico2_release`** UF2s). **`make all`** in **`cpanel`** still fails: **`java`** invokes **x86_64** **`/usr/local/Cellar/openjdk/.../bin/java`** (use **`/opt/homebrew`** JDK or **`JAVA_HOME`** for test-disk step). **`cc65`**/**`cmake`** on PATH are **arm64**.

- **Implementation notes §4b:** User updated **libusb** (arm64 Homebrew). Doc now states preferred **`brew install libusb`** + **`pkgconf`**, rebuild **picotool** without **`PICOTOOL_NO_LIBUSB`** for USB; **`PICOTOOL_NO_LIBUSB`** remains UF2-only fallback. Summary table **Host picotool** row updated. **`docs/Implementation-notes-and-reasoning.md`**.

- **Verify Apple Silicon toolchain + full build:** Confirmed **`/Applications/ArmGNUToolchain/15.2.rel1/.../arm-none-eabi-gcc`** is **arm64** with valid **`nosys.specs`**; **13.2** / **14.2** remain **x86_64** (skipped by **`mf_try_arm_toolchain_bin`**). **`./build-both.sh`** compiled both firmwares; link failed on vendored **`pico/picotool/picotool/picotool`** (**x86_64**). Rebuilt **picotool** from **`picotool-src`** with **`PICOTOOL_NO_LIBUSB=1`** (avoid **`/usr/local`** x86 **libusb**), **`cmake --install`** into **`pico/picotool/`** → **arm64** binary; **`make -C pico_release`** + **`pico2_release`** succeeded (**`megaflash.uf2`** both).

- **ARM host build defaults:** Pico SDK fallback **`/Users/eositis/pico-sdk` → `$HOME/pico-sdk`** in **`pico/cmakeall.sh`**, **`pico/build-both.sh`**, and **`pico/CMakeLists.txt`** so Apple Silicon / other machines need no hardcoded user path. **`cmakeall.sh`** / **`build-both.sh`**: after Arm GNU pkg dir, probe **`/opt/homebrew/bin`** then **`/usr/local/bin`** for **`arm-none-eabi-gcc`** (Apple Silicon Homebrew vs Intel). Updated **`pico/BUILD-REQUIREMENTS.md`**, **`pico/README.md`**, **`docs/Implementation-notes-and-reasoning.md`** §4 + summary row. **`BUILD-REQUIREMENTS.md`**: note on **`bad CPU type`** after Intel→ARM (reinstall **arm64** CMake/tools).

- **Configure check:** Local **`cmake`** in this environment exited **`bad CPU type in executable`** (host/tool arch mismatch); not a repo issue — use native **arm64** CMake on Apple Silicon.

- **`build-env.sh` + arm64 CMake:** Added **`pico/build-env.sh`** (**`CMAKE_BIN`**: **`/opt/homebrew/bin/cmake`** → **`/usr/local/bin/cmake`** → **`PATH`**; **`CMAKE`** override). Sourced from **`cmakeall.sh`**, **`build-both.sh`**, **`build-debug.sh`**; all **`cmake`** invocations use **`"$CMAKE_BIN"`**. Docs: SDK is same repo on ARM hosts—clone to **`~/pico-sdk`**; **`BUILD-REQUIREMENTS.md`** §1/§3 and **`README`** updated; Implementation notes §4 + summary table row for host CMake.

- **Build test (2026-04-03):** **`./build-both.sh`** — **`cmake`** = **`/opt/homebrew/bin/cmake`** OK; **`cpanel`**: **`make release`** (skip Java test target). Intel **ArmGNUToolchain** + Homebrew **`arm-none-eabi-gcc`** fail Pico (**`nosys.specs`** / newlib). **`mf_try_arm_toolchain_bin`** now requires runnable host GCC **and** existing **`nosys.specs`**; **`cmakeall`/`build-both`** **`exit 1`** with **darwin-aarch64** install hint if none. **`GCC_PATH=$(command -v … \|\| true)`** fixes **`set -e`** early exit. Stale **`pico_release`** had x86 **`pioasm`** — **`rm -rf pico_release pico2_release`** before reconfigure on arch change.

---

## 2026-03-27

- **Git `1.2.x` branch:** Created **`1.2.x`** at the same commit as **`main`** (`aadb80f`, firmware **`V1.2.0-eo` / `0x0020` in `pico/defines.h`). **`git push -u origin 1.2.x`** — **`main`** and **`1.2.x`** both track the **1.2.x** development line; **`1.1.x`** remains the **1.1.x** maintenance line (e.g. V1.1.25-eo).

- **Release V1.1.25-eo (`0x001d`):** Bumped **`pico/defines.h`**; built **`cpanel`**, **`pico_release`** + **`pico2_release`**; UF2s + **`CHANGELOG.md`** → **`pico/_releases/V1.1.25-eo/`** (`megaflash-pico.uf2`, `megaflash-pico2.uf2`). DNS timeout ordering fix included from **`pico/udptask.cpp`**.

- **1.1.x local DNS fix (V1.1.24-eo baseline):** **`CUDPTask::DNSLookup`** — set **`dnsTimeout`** **before** **`dns_gethostbyname(...)`**; **`dnsTimeout = TIMEOUT_NEVER`** on immediate result paths (`ERR_OK`, `ERR_ARG`, other non-`ERR_INPROGRESS`). Legacy **`dns_callback`** stack only. **`pico/udptask.cpp`**; **`cmake --build pico/pico2_release`** OK.

- **`main` ← `1.1.x`:** Checked out **`main`** and **fast-forward** merged **`1.1.x`** (commit `aadb80f` — DNS race, RAM disk 256 KiB, TFTP heap diagnostics, NetworkPump/U2/u2_monitor, `uthernet2_net.cpp`, build scripts, docs). **`main`** and **`1.1.x`** now point at the same commit locally.

---

## 2026-03-22

- **1.1.24 DNS intermittent lookup fix:** `CUDPTask::DNSLookup` had a race: `RegisterDnsPendingOwner(this)` was set **after** `dns_gethostbyname`, so fast callbacks could be ignored (`not pending owner`) and later timeout. Moved registration **before** request and clear owner on immediate returns (`ERR_OK`/`ERR_ARG`/other). `pico/udptask.cpp`; `cmake --build pico/pico2_debug` OK. Documented §14.11 + summary row.

- **RP2350 `RAMDISK_SIZE`:** Reduced **400 KiB → 256 KiB** in `pico/defines.h` (request said “256MB”; applied as **256 KiB** — SRAM cannot hold 256 MB). Frees ~144 KiB static RAM for heap/network; `README.md` + §13d RAM disk note updated.

- **TFTP OOM panic diagnosis:** `panic("Out of memory")` is Pico SDK **pico_malloc** (failed `new` or heap past `__StackLimit`); TFTP task ctors allocate ~2.5 KiB. CP “RAM disk off” does not free static **`ramdisk_data[]`**. Added **`DebugPrintHeapState("NETPUMP: TFTP pre-new")`** before TFTP `new` (`misc.c`/`misc.h`, `network_pump.cpp`); §13d + summary table. **`cmake --build pico/pico2_debug`** OK.

- **U2: core‑0 monitor flush + MACRAW discard:** `U2_MonPollFlush` removed from `U2_Poll` (core 1); added to `main.c` `core0Loop` + USB idle (fixes **`async_context` PANIC** with **`[u2] ck=5`**). `u2_push_rx_macraw`: `u2_socket_discard_rx` when full so DHCP isn’t starved by **`drop (no room)`**. `u2_monitor.h`, `uthernet2.c`, §1g + summary.

- **Bench + build:** User confirmed **S0_SR = `$42`** (MACRAW OPEN); **`pico2_debug`** `cmake --build` OK for continued **telnet65** / UART testing.

- **debug/README.md:** Added “Manual W5100 checks after RTR” — monitor table for RMSR/TMSR/SHAR/S0_SR + UART bisect **`ck=1..5`** and note that telnet65 “Device not found” maps to **`eth_init`** only.

- **U2 `$C0C7` priming verified on hardware:** After **`U2_PeekDataPort`** + **`registers.r[7]`** update in **`busloop.c`**, monitor test (MR **`C0C4:03`**, pointer **`$0017`**, three **`C0C7`** reads) returns **`07`/`D0`/`08`** (RTR0/RTR1/RCR).

- **U2 first `$C0C7` stale (monitor screenshot):** With pointer **`00`/`17`** verified, first DATA read was **`$08`** then **`$07`/`$D0`** — stale **`registers.r[7]`** vs RP2350 PIO prefetch. **`busloop.c`** sets **`registers.r[7] = U2_PeekDataPort()`** after each U2 access; **`uthernet2.c`/`uthernet2.h`** add **`U2_PeekDataPort`**. §1f + summary table. **`cmake --build pico/pico2_debug`** OK.

- **Manual RTR test — three DATA reads `$D0`,`$07`,`$D0`:** Noted in §1f: matches **RTR1 / RTR0 / RTR1** (`$0018`/`$0017`/`$0018`), not the expected **`$07`,`$D0`,`$08`** from **`$0017`** with AI. User to confirm pointer (`$C0C5`/`$C0C6`) before/after each **`$C0C7`** read and that **`C0C6:17`** not **`18`**; if pointer shows **`$0017`** but first DATA is **`$D0`**, treat as bus/emulation bug to capture (Debug UART / `[u2m]`).

- **Manual RTR test — two $C0C7 reads both $07:** Documented in `docs/Implementation-notes-and-reasoning.md` §1f: firmware only auto-increments the W5100 pointer after a DATA read when **MR** includes **AI** ($02); **`u2_reset()`** leaves MR=$00, and MR=$01 (IND only) also does not increment — so the second read stays at **$0017** (RTR0). Fix on the bench: confirm **`LDA $C0C4`** = **$03** after **`STA $C0C4`** before the paired DATA reads.

- **Debug UART: `U2_Init` before `stdio_uart_init`:** `[u2]` / `[u2m]` boot text was emitted with no UART driver — lost on wire. Moved **`U2_Init()`** to after **`stdio_uart_init` + `setbuf`** in `main.c`. Not a “wrong UF2” issue; same Debug binary had ordering bug. `U2_Init` also prints **`U2_IP65_CHECKPOINT`** line; CMake default checkpoint **1** so **`[u2] ck=1`** appears when ip65 writes MR=0x03.
- **Pico 2 W ip65 debug (bisect + quiet UART):** CMake cache **`U2_IP65_CHECKPOINT`** (1–5, 0=off), **`U2_IP65_TRACE_DATA`**, **`U2_MON_LOG_BUS`**; default low noise — single **`[u2] ck=n`** line queued to **`U2_Poll`**; **`build-debug.sh`** builds **`pico2_debug`** only. `busloop.c` comment: **`r[4..7]`→chunk 1→PIO**. `debug/README.md`, `docs/Implementation-notes-and-reasoning.md` summary.

## 2026-03-21

- **U2: no printf on bus path:** `[u2]` mode + DATA trace + socket CR no longer call `printf` from `U2_HandleBusAccess` / `write_socket_register` (stalls bus loop → only 2–3 UART lines and broken ip65 timing). Events go through `u2_monitor` queue; `U2_Poll` every **32** Uethernet cycles; ring **256** / flush **128**. `u2_monitor.{c,h}`, `uthernet2.c`, `uthernet2_net.cpp`, `busloop.c`. `pico2_debug` rebuild OK.
- **U2 UART ip65 init trace:** On `MR=0x03`, Debug firmware logs the next **48** DATA-port reads (`[u2] DATA read addr=…`) so serial tails show full `w5100.s` init after RTR; `uthernet2.c`. §1c note updated (stock `ip65_init` always `clc` after successful `eth_init`). `pico2_debug` rebuild OK.
- **Pico 2 W Debug build (UART banner):** `cmake --build pico/pico2_debug -j8` — `pico/pico2_debug/megaflash.uf2` includes always-on `FIRMWAREVERSTR` + `Firmware build:` lines from `main.c`.
- **UART boot banner (continuous serial captures):** `main.c` now always prints `FIRMWAREVERSTR` next to numeric `FIRMWAREVER` and always prints **`Firmware build: … (Unix s)`** (`build_id.h`: `unknown` / `0` when CMake was not given `-DFIRMWARE_BUILD_TIMESTAMP` by `build-both.sh` / `cmakeall.sh`), so the **most recent** reboot block in a log identifies the product version and, when builds use the scripts, the exact build time.
- **Debug log `debug/2026-03-21 21-42-20 FT232R USB UART #1.log`:** 21:45 / 22:06 show `[u2] mode=0x03` only (no RTR lines → probe not logged or not reached); 22:14:06 shows RTR `0x07`/`0xD0` — per `ip65/drivers/w5100.s`, `init` has no other `SEC`, so that attempt should pass `ip65_init` for Ethernet; “Device not found” on-screen likely a different run or misread vs DHCP `print_error`. Documented in `docs/Implementation-notes-and-reasoning.md` §1c “Reconciling UART with the screen”.
- **U2 UART + telnet65 “device not found”:** `uthernet2.c` `read_value()` logs first 8 RTR data-port reads (`RTR data read addr=0x0017/0x0018 -> …`) when `UTHERNET2_DEBUG` so serial captures show ip65 probe vs lone `mode=0x03` line; §1c note in Implementation notes.
- **ip65 slot 4 → `debug/`:** Forced `make apple2` in `../ip65` (clean libs/dsk/zip); verified `telnet65.bin.map` has `eth_init_default` = 4 (`a2init.o`). Copied `ip65.dsk` + `ip65-apple2.zip` to `MegaFlash/debug/`; added `debug/README.md` (UART capture naming, `[u2]`/`[u2m]` vs Apple-side telnet65, rebuild commands).
- **Pico 2 W Debug build:** `cmake --build pico/pico2_debug -j8` (configured `Debug` + `pico2_w` if needed); output `pico/pico2_debug/megaflash.uf2`.
- **U2 activity monitor + Debug build script:** `u2_monitor.c`/`u2_monitor.h` — ring-buffered `[u2m]` UART lines (bus $C0C4–$C0C7, W5100 reset, socket CR path, UDP/TCP/MACRAW net RX/TX); flush from `U2_Poll` (core1-safe vs lwIP). CMake Debug adds `U2_ACTIVITY_MONITOR=1` with `UTHERNET2_DEBUG`; `pico/build-debug.sh` builds `pico_debug` + `pico2_debug`. Wired in `uthernet2.c` / `uthernet2_net.cpp`; `pico/README.md` §1e + summary. `pico_debug`/`pico_release` build OK.
- **RP2350 U2 + ip65 “Device not found”:** U2 branch in `busloop.c` skipped the PIO IRQ 0 wait required on RP2350 before updating `rxfifo` (`a2bus_rp2350.pio` delayed pull). Added same wait as main loop before `UpdateMegaFlashRegisters(1,…)` (`#ifndef PICO_RP2040`). `docs/Implementation-notes-and-reasoning.md` §1d + summary table. `pico_release` build OK.
- **U2 / telnet65 init:** Documented ip65 `w5100.s` probe (RTR XOR at $0017/$0018) as the sole cause of telnet65 “Device not found” before DHCP; RMSR=$06 short path skips SHAR write but reads SHAR → `cfg_mac`, so `u2_reset()` now programs default SHAR `00:08:DC:A2:A2:A2` (same as `ip65/drivers/w5100.s`). `pico/uthernet2.c`, `docs/Implementation-notes-and-reasoning.md` §1c + summary table.
- **ip65 Apple II build + AppleCommander:** Downloaded `AppleCommander-ac-13.0.jar` to `spf/build/lib/` (alongside existing `AppleCommander-1.3.5.13-ac.jar` from SPF `build.xml`). `ip65/apps/Makefile` defaults `AC` to `../../spf/build/lib/AppleCommander-ac-13.0.jar` when present (else legacy jar, else `ac.jar`). `make apple2` produces `ip65.dsk` + `ip65-apple2.zip`.
- **Uthernet II → NetworkPump:** `uthernet2_net.c` → `uthernet2_net.cpp`; `Uthernet2Session` (`OnUdpRecvPbuf` with `udp_pcb*`, `Abort`); UDP `CreateUdpPcb`/`DestroyUdpPcb`; `U2_Net_Poll` → `NetworkPump_PollOnce`; TCP uses `U2TcpArg` + `u2_tcp_*` (not `CreateTcpPcb`, because `tcp_err` has no pcb). `OnUdpRecvPbuf(pcb,…)` extended for multi-UDP routing; `uthernet2_net.h` `extern "C"`. §14.10/14.10b/14.12 + summary. `pico_release` build OK.
- **§14.12 NetworkPump TCP + timers:** `CreateTcpPcb` registers owner, `tcp_arg(owner)`, `NetworkPump_LegacyTcpRecv`/`NetworkPump_LegacyTcpErr` → `OnTcpRecvPbuf`/`OnTcpErr` (default frees pbuf); `DestroyTcpPcb` unregisters and aborts. `ScheduleTimer`/`CancelTimer`/`DrainSessionTimers` in `PollOnce`; `RequestAbortAll` clears pump timers. `pico/network_pump.{h,cpp}`; §14.4/14.8/14.12 + summary. `build-both.sh` OK.
- **Human-readable build time:** `FIRMWARE_BUILD_TIMESTAMP_STR` (UTC `YYYY-MM-DD HH:MM:SS UTC`) with Unix `FIRMWARE_BUILD_TIMESTAMP`; `build_id.h.in` → `build_id.h` via `configure_file` (replaces compile-only macro). `misc.c`/`main.c`/`cmdhandler.c` include `build_id.h`; bytes [12..15] LE unchanged. `build-both.sh`, `cmakeall.sh`, `pico/README.md`, Implementation notes summary. `build-both.sh` OK.
- **§14.11 DNS pending as `INetworkSession*`:** `dns_pending_owner_`, `RegisterDnsPendingOwner` / `ClearDnsPendingOwner` / `IsDnsPendingOwner`; lwIP callback arg = `INetworkSession*`; `INetworkSession::OnDnsGetHostByNameResult`; `CUDPTask` implements (replaces `DeliverDnsLwIPCallback`). Docs §14.4/14.8/14.9/14.11 + summary table. `pico/network_pump.{h,cpp}`, `pico/udptask.{h,cpp}`. `build-both.sh` OK.
- **`CreateUdpPcb` / `DestroyUdpPcb` wired:** `CreateUdpPcb` registers owner, installs `NetworkPump_LegacyUdpRecv` with `arg=this` `NetworkPump*`; `CUDPTask::BeginRun` uses `CreateUdpPcb(this,0)`; destructor uses `DestroyUdpPcb`. `pico/network_pump.{h,cpp}`, `pico/udptask.cpp`; §14.10 + summary. `build-both.sh` OK.
- **§14.10 pcb→`INetworkSession*`:** `udp_pcb_owners_` maps `udp_pcb*`→`INetworkSession*`; `RegisterUdpPcbOwner` / `UnregisterUdpPcb`; dispatch calls `OnUdpRecvPbuf`. `CUDPTask` inherits `INetworkSession`, overrides `OnUdpRecvPbuf`→`NotifyUdpReceived`. `pico/network_pump.{h,cpp}`, `pico/udptask.{h,cpp}`; §14.8/14.10/14.11 + summary table. `build-both.sh` OK.
- **§14.10 Single UDP recv via `NetworkPump`:** `udp_recv` uses `NetworkPump_LegacyUdpRecv` with `arg=&GetNetworkPump()`; `RegisterLegacyUdpPcb`/`UnregisterLegacyUdpPcb` map `udp_pcb*`→`CUDPTask*`; `CUDPTask::NotifyUdpReceived` replaces per-task `udp_callback`. `GetNetworkPump()` moved outside `extern "C"` in `network.cpp`. `pico/network_pump.{h,cpp}`, `pico/network.{h,cpp}`, `pico/udptask.{h,cpp}`; §14.9–14.10 + summary table. `build-both.sh` OK.
- **§14.9 DNS/UDP callbacks without `runningObject`:** DNS pending task `s_dnsPendingTask` set on `ERR_INPROGRESS`, cleared on result/timeout/`LeaveRunSession`. UDP accepts only when `pcb == pTask->pcb`. Prepares removal of legacy single-task callback gating. `pico/udptask.cpp`; §14.9 + summary table. `build-both.sh` OK.
- **TFTP upload block line `N/total`:** `tftp_state.tsize` was only set in `CTFTPTXTask::Run()`, which `NetworkPump::RunTFTP` no longer calls. Moved TX/RX `Run()`-only state into **`EvtStart()`** so `TFTPFormatBlocksMessage` gets `tsize` again. `pico/tftptxtask.{h,cpp}`, `pico/tftprxtask.{h,cpp}`; §7h in Implementation notes. `build-both.sh` OK.
- **`pico/build-both.sh`:** New script builds cpanel then **both** `pico_release` and `pico2_release` (no `defines.h` bump). Documented in `pico/README.md`, §4 + §11 in Implementation notes, Cursor rule `pico-firmware-build.mdc`. Ran successfully; outputs `pico_release/megaflash.uf2` and `pico2_release/megaflash.uf2`.
- **Test build:** `cmake -B pico_release` + `cmake --build pico_release -j8` (Pico W Release) succeeded; ARM toolchain `/Applications/ArmGNUToolchain/13.2.Rel1/arm-none-eabi/bin`, SDK `/Users/eositis/pico-sdk`. (Did not run `cmakeall.sh` to avoid bumping `defines.h` version.)
- **CMake default `PICO_SDK_PATH`:** If neither `-DPICO_SDK_PATH` nor a non-empty `ENV{PICO_SDK_PATH}` is set, `pico/CMakeLists.txt` now sets the same fallback as `cmakeall.sh` (`/Users/eositis/pico-sdk`) before `include(pico_sdk_import.cmake)`, so configure works in non-interactive shells. Override with `-D` or `export` as before.
- **NetworkPump: drive NTP / Test WiFi / TFTP via `PollOnce` + `OnPump`:** Legacy `RunNTP` / `RunTestWifi` / `RunTFTP` no longer call `CUDPTask::Run()`. They use `EnterRunSession` + `BeginRun` + `StartEventsAfterBeginRun`, register a short-lived `LegacyUdpSessionAdapter` (`OnPump` → `PumpNetworkIteration`), and loop `PollOnce()` until `GetCompleted()`—same per-iteration work as `Run()`’s inner loop, with `ScopedPumpSession`/`disarm` for exception-safe `RemoveSession`. `CUDPTask::Run()` refactored to the same helpers. `pico/udptask.{h,cpp}`, `pico/network_pump.{h,cpp}`, §14.8 + summary table in `docs/Implementation-notes-and-reasoning.md`. (Pico SDK not configured in this environment—build locally.)
- **NetworkPump: CUDPTask split + session `PollOnce`:** Refactored `CUDPTask::Run` into `BeginRun` + `PumpNetworkIteration` (same behaviour). `NetworkPump::AddSession`/`RemoveSession` register up to 8 `INetworkSession*`; `PollOnce` runs `cyw43_arch_poll` + `OnPump` per session. `INetworkSession` defaults are no-ops; added `OnPump`. `RequestAbortAll` calls `Abort()` on registered sessions. `NetworkPump_PollOnce()` from Core 0 idle loop in `main.c`. `pico/udptask.{h,cpp}`, `pico/network_pump.{h,cpp}`, `pico/network.{h,cpp}`, `pico/main.c`, §14.8 in Implementation notes.
- **NetworkPump: NTP + Test WiFi with TFTP:** `GetNetworkTime()` and `TestWifi()` now delegate to `NetworkPump::RunNTP` / `RunTestWifi` (same legacy-op pattern as `RunTFTP`: `BeginLegacyOperation` for NTP / Test WiFi / TFTP). Protocol logic unchanged (`CNTPTask` / `CTestWifiTask` inside `CUDPTask::Run`). `pico/network_pump.{h,cpp}`, `pico/network.cpp`; §14.8 + summary table in `docs/Implementation-notes-and-reasoning.md`. Built `pico_release` OK.
- **1.2.x development line:** Set `FIRMWAREVER` / `FIRMWAREVERSTR` to **V1.2.0-eo** (`0x0020`) in `pico/defines.h`; updated version-history comments. Aligned `docs/Implementation-notes-and-reasoning.md` chronology and `pico/CHANGELOG-NEXT.md` so **V1.1.24-eo** is documented as the last 1.1.x release and ongoing work is **1.2.x** from V1.2.0-eo.
- **Git `1.1.x` fast-forwarded to `main`:** Local `1.1.x` now matches `main` at `3d7d40e` (V1.1.24-eo). `git push origin 1.1.x` required locally to update `origin/1.1.x` (push failed in this environment).
- **Git branch `1.1.x`:** Created local branch `1.1.x` at current `main` tip (`60ee358`) for 1.1.x maintenance; switched back to `main`. `git push -u origin 1.1.x` failed here (no GitHub credentials in environment)—run that locally to publish. Workflow documented in `docs/Implementation-notes-and-reasoning.md` §10e.
- **Release folder `pico/_releases/V1.1.24-eo/`:** Copied `megaflash-pico.uf2` and `megaflash-pico2.uf2` from current `pico_release` / `pico2_release` builds; added `CHANGELOG.md` (1.1.24-eo fixes + prior 1.1.23-eo notes).
- **Firmware build number V1.1.24-eo (0x001c):** Set `FIRMWAREVER` / `FIRMWAREVERSTR` in `pico/defines.h`; rebuilt `pico_release` and `pico2_release` UF2s.
- **Build:** `make -C cpanel` (no changes), `cmake --build pico/pico_release` and `pico/pico2_release` (-j4); UF2s `pico/pico_release/megaflash.uf2`, `pico/pico2_release/megaflash.uf2`.
- **Drives Enable checkbox toggle wrong row:** cc65 `gotoxy(x,y)` adds `WNDTOP` to `y` (window-relative). `PrintCheckbox` used `YPOS + driveIndex` as if `y` were absolute screen row, so toggles drew **YPOS** lines too low (6). Fixed: pass window-relative rows (`i`, `listCount`, `listCount+1` for ROM); `romdiskRow` for the ROM line is now `listCount+1` instead of `YPOS+listCount+1`. `cpanel/drivesenable.c`.
- **Control panel firmware version left of clock:** `_DisplayTime` in `cpanel/asm-megaflash.s` had been reduced to time-only (cols 32–39), dropping `CMD_GETFIRMWAREVER`. Restored: poll `CMD_GETFIRMWAREVER` first and paint 12 chars at cols 20–31, then `CMD_GETTIMESTR` at 32–39. `ClearTime` now clears cols 20–39 so format/erase flow does not leave stale version text. TESTBUILD shows a placeholder version string.

## 2026-03-20

- **ROM disk default after “Reset all options to default”:** Changed firmware/UI defaults so `ROMDISKFLAG` is not set by default (`common/defines.h`: `DEFCFGBYTE1 = AUTOBOOTFLAG`). After `EraseAllSettings()` the new default is now ROM disk hidden unless the user enables it on the Drives Enable page. Additionally, `cpanel/dialogs.c` now calls `DisableRomdisk()` immediately after `LoadConfig()` during the erase-all flow when `ROMDISKFLAG` is not set (so ROM disk isn’t left enabled just because Control Panel enables it on startup).

## 2026-03-17

- **ip65 / Uthernet II adaptations and [u2] debug:** (1) RECV advances RX_RD to sn_rx_wr so ip65 sees 0 bytes until next frame; (2) socket CR cleared to 0 after each command so ip65 wait loop exits; (3) default RMSR/TMSR set to 0x06 for ip65 chip-check path; (4) MACRAW RX: netif input hook installed when socket 0 opens in MACRAW, wrapper feeds received frames via U2_Net_FeedMacrawRx(0,...) then calls original input; (5) U2 debug logging prefixed with `[u2]`, gated by UTHERNET2_DEBUG (set in Debug build only), not NDEBUG. Debug build: `pico/CMakeLists.txt` adds UTHERNET2_DEBUG=1 for Debug; built pico_debug and pico2_debug. `pico/uthernet2.c`, `pico/uthernet2.h`, `pico/uthernet2_net.cpp`, `docs/ip65-Uthernet-II-integration.md`.
- **Version 1.2.0 / end of 1.1.x:** Set firmware to V1.2.0-eo (0x0020); 1.1.23 is the last 1.1.x build. 1.2 series will focus on Uthernet II emulation, com port, and imagewriter emulation. Updated `pico/defines.h` (version + comment), `pico/CHANGELOG-NEXT.md` (1.2 series intro).
- **Doc cleanup:** Removed accidental untracked `cc65/cc65-megaflash-lib.md` and restored `docs/cc65-megaflash-lib.md` from `HEAD`.
- **TFTP hostname field wrong default (Pico IP / “transferred successfully”):** First time TFTP page opened showed Pico’s IP; after a successful job, field showed status text. Root cause: shared data buffer; PIO was not updated with new DATAREG immediately after CMD_TFTPGETLASTSERVER, so Apple’s first read saw stale data. Fix: in `busloop.c` call `UpdateMegaFlashRegisters(0, registers.i32[0])` right after clearing BUSY in CMDREG handler so chunk 0 (including DATAREG) is pushed before next bus cycle. Defensive: in `cpanel/tftp.c` after `CopyStringFromDataBuffer`, if string looks like status text (e.g. “Successfully”, “Completed”), clear to blank. §7g in Implementation notes.
- **TFTP breaks when debug disabled – lwIP tied to NDEBUG:** Disabling debug (NDEBUG) was changing lwIP: in `lwipopts.h`, LWIP_DEBUG/LWIP_STATS/LWIP_STATS_DISPLAY were set only when `#ifndef NDEBUG`, so release built a different lwIP and TFTP broke. Fixed by setting LWIP_DEBUG, LWIP_STATS, LWIP_STATS_DISPLAY to 0 always so Debug and Release use the same lwIP; only our logging is gated by NDEBUG. Reverted extra cyw43_arch_poll() added for wrong fix. §7f in Implementation notes. `pico/lwipopts.h`, `pico/udptask.cpp`.
- **Release = same codegen as Debug, only NDEBUG:** Debug worked, Release stalled; difference is -O3 (Release) vs -Og (Debug), not just UART. Set CMAKE_C_FLAGS_RELEASE and CMAKE_CXX_FLAGS_RELEASE to "-g -Og -DNDEBUG" in CMakeLists.txt so Release only disables assert/UART; codegen matches Debug. §7e in Implementation notes. Rebuilt pico_release with new flags.
- **Debug build for TFTP stall diagnosis:** Built pico_debug and pico2_debug; copied UF2s to `pico/_releases/debug-build/` (megaflash-pico.uf2, megaflash-pico2.uf2) for testing with UART/serial debug output.
- **TFTP upload stall after ~14 blocks:** Deferred building the next TFTP TX data packet to the start of the event loop (`OnBeforeWait()`) instead of inside the UDP ACK handler, so flash/ReadBlock (SPI + mutex) no longer runs in the receive path. Avoids stall/lockup requiring hard power-off. Added `OnBeforeWait()` hook in `udptask`, deferred-build state and override in `tftptxtask`. §7d in Implementation notes. `pico/udptask.h`, `pico/udptask.cpp`, `pico/tftptxtask.h`, `pico/tftptxtask.cpp`.
- **Release build:** Ran `pico/cmakeall.sh` → version V1.1.21-eo (0x0019), cpanel built, pico_release and pico2_release built, UF2s and CHANGELOG copied to `pico/_releases/V1.1.21-eo/`.
- **Why Release bug was missed / prevention:** Documented in `docs/Implementation-notes-and-reasoning.md` §7b (why missed: Debug-only testing, intentional Release branching looked like design, no Release test requirement, timing-dependent failure). Added prevention: test Release before release, document checklist, minimize critical Debug/Release differences, CI for both builds. Added §7c Pre-release verification checklist (boot, network NTP/TFTP/WiFi test, bus/Apple). Updated summary table (§11).
- **Release 1.1.20 network stack fix:** In Release we only started Core1 and ran core0Loop() when `appleConnected` was true; if `IsAppleConnected()` was false at boot (timing/PHI0), the network loop never ran and “nothing worked.” Now: always launch Core1 (match Debug); use `CheckPicoW()` for Core0 so on Pico W we always run core0Loop() (NTP/TFTP/WiFi) regardless of appleConnected. Documented in `docs/Implementation-notes-and-reasoning.md` §7b. `pico/main.c`.

---

## 2026-03-09

- **U2 read-after-write fix:** PIO chunk 1 ($C0C4–$C0C7) was only updated on U2 reads; writes never called UpdateMegaFlashRegisters(1, ...). SM 1 output stale 0x00 on read-after-write. Now: on U2 write to Mode Reg / Addr High / Addr Low, set registers.r[addr]=data and always call UpdateMegaFlashRegisters(1, ...) for both reads and writes. Data Port (addr 7) readback comes from memory; still updated on read only. `pico/busloop.c`.
- **Toolchain fix in cmakeall.sh:** Pass CMAKE_OBJDUMP and CMAKE_OBJCOPY from TOOLCHAIN_BIN so build no longer uses /usr/local/bin/arm-none-eabi-objdump. Export PATH with toolchain bin first; add PICO_TOOLCHAIN_PATH for SDK compiler lookup. `pico/cmakeall.sh`.
- **TFTP receive fix when reusing WiFi:** When ConnectWifi returns early (already LINK_UP), added ~100 ms warmup: 100× `cyw43_arch_poll()` + 1 ms sleep before returning. Stabilizes lwIP/CYW43 so new UDP PCB can receive (pico-sdk #915). TFTP no longer stuck at "Requesting Server". `pico/udptask.cpp`, `CHANGELOG-NEXT.md`.
- **Drives Enable checkboxes alignment:** Draw checkboxes inline in PrintDriveListWithCheckboxes (cputc tick/space when printing each "( )") so they align with drive rows. ROM disk checkbox unchanged. `cpanel/ui-misc.c`, `cpanel/drivesenable.c`, `cpanel/ui-misc.h`.
- **cmakeall cpanel step:** cmakeall.sh now builds cpanel first (make -C ../cpanel) before Pico firmware. Decremented version to 0x0012/V1.1.14-eo, then ran build → V1.1.15-eo release with cpanel included. `pico/cmakeall.sh`, `defines.h`.

## 2026-03-10

- **Apple II API reference doc:** Added `docs/MegaFlash-AppleII-API.md` documenting all C0C0 commands, their 65C02 calling sequences, equivalent Applesoft PEEK/POKE usage, and how ROM hooks (FPU, clock, SmartPort) map onto these commands so other languages can bypass ROM if needed.
- **cc65 MegaFlash library:** Added `cc65/megaflash.h` and `cc65/megaflash.c` exposing a small C API for unit enumeration, volume info, block I/O, firmware/time strings, ROM disk control, and WiFi self-test on Apple IIc/IIc+. Documented usage and examples in `docs/cc65-megaflash-lib.md`.
- **A2osX C MegaFlash library:** Added `a2osx/megaflash_a2osx.h` / `.c`, a portable K&R-style C wrapper around the same MegaFlash API for the C compiler used in A2osX. It avoids cc65-specific features and uses simple typedefs (`mf_u8`, `mf_u16`, `mf_u32`). Usage and integration notes for A2osX are documented in `docs/a2osx-megaflash-lib.md`.
- **cc65 FPU bindings:** Extended the cc65 library (`cc65/megaflash.h/.c`) with an MBF-level FPU API: `mf_fpu_args_t`/`mf_fpu_result_t` plus `mf_fpu_op` and wrappers (`mf_fadd`, `mf_fmul`, `mf_fdiv`, `mf_fsin`, etc.). These send the same 13-byte FAC/ARG layout used by Applesoft hooks and read back the 8-byte MBF result, allowing C programs to drive MegaFlash’s FPU without using ROM Applesoft. Documented the layout and usage in `docs/cc65-megaflash-lib.md`.

---

## 2025-02-15

- **Pin 27 deactivated; slot select = default MegaFlash (address only)**: Removed GPIO 27 slot select. `pico/defines.h`: removed `SLOT4_SELECT_GPIO` and `IsSlot4Selected()`; comment now “address decode only, no GPIO slot select”. `pico/busloop.c`: Uthernet II when `addr >= U2_C0X_OFFSET` only (no `IsSlot4Selected()`). `pico/main.c`: removed GPIO 27 init; only `U2_Init()`. `docs/Uthernet-II-emulation-on-MegaFlash.md`: no pin 27, slot select = default bus behaviour.
- **Uthernet II slot 4 only; removed all slot 3 references**: Uthernet uses slot 4 only. `pico/defines.h`: `SLOT3_SELECT_GPIO` → `SLOT4_SELECT_GPIO`, `IsSlot3Selected()` → `IsSlot4Selected()`; comments now $C0C0–$C0C7. `pico/busloop.c`, `pico/main.c`: use slot 4 select. `pico/uthernet2.c` / `uthernet2.h`: comments slot 4 only ($C0C4–$C0C7). `docs/Uthernet-II-emulation-on-MegaFlash.md`: all slot 3 → slot 4, pin 27 = slot 4 device select. `docs/C0x-register-comparison-Uthernet2-MegaFlash.md`: U2 + MegaFlash in slot 4, C0x4–C0x7 vs C0x0–C0x3.
- **Uthernet II at C0x4–C0x7 only**: When slot 4 is selected (GPIO 27), MegaFlash decodes by address: C0x0–C0x3 ($C0C0–$C0C3) = MegaFlash; C0x4–C0x7 ($C0C4–$C0C7) = Uthernet II W5100. `pico/defines.h`: `U2_C0X_OFFSET` (4). `pico/busloop.c`: `U2_HandleBusAccess` only when `IsSlot4Selected() && addr >= U2_C0X_OFFSET`.
- **Build**: Rebuilt Pico (RP2040) and Pico 2 (RP2350) firmware; `pico2_release/megaflash.uf2` and `pico_release/megaflash.uf2` produced successfully.
- **Session log**: Session log updated; rule `.cursor/rules/session-log.mdc` strengthened so the log is updated before ending any turn where code/config or builds were done.

---

## 2025-02-06 (this session)

- **Project overview**: Explained MegaFlash firmware (Apple IIc/IIc+ ROM patches, Slot 4 SmartPort driver, Pico storage). Build: CC65 → ROM fragments → merge into `rom4.bin`/`rom5.bin` → `iic.bin`/`iicplus.bin`.
- **Network service**: Documented TFTP/NTP/WiFi on Pico W (Core 0), command flow Apple → Core 1 → IPC → Core 0, Control Panel TFTP UI and CMD_TFTPRUN/CMD_TFTPSTATUS.
- **ROM disk always available**: Default ROM disk enabled in `pico/romdisk.c`; removed `DisableRomdisk()` from `DoAppleColdStart()` in `pico/cmdhandler.c` and from Control Panel startup in `cpanel/main.c`.
- **ROM disk last unless “Boot to ROM Disk”**: Added ROM disk position (first vs last). `pico/romdisk.c`/`.h`: `GetRomdiskFirst()`/`SetRomdiskFirst()`. `pico/mediaaccess.c`: `TranslateUnitNum` and `GetRamdiskUnitNum()` support ROM-first vs ROM-last. `CMD_ENABLEROMDISK` takes param 0 = last, 1 = first. Cold start sets ROM last. Boot menu “3) Boot ROM Disk” sends param 1. Control Panel: `EnableRomdiskAtLast()` on startup; new menu “Boot to ROM Disk” calls `BootToRomdisk()` (param 1 + reboot). New asm: `EnableRomdiskAtLast`, `BootToRomdisk` in `cpanel/asm-megaflash.s` and `asm.h`.
- **Pico build (macOS)**: Diagnosed missing tools (`PICO_SDK_PATH`, cmake, arm-none-eabi-gcc). Fixed `ranlib` “has no symbols” by forcing ARM `ar`/`ranlib` in `pico/cmakeall.sh`. Addressed `nosys.specs` error (incomplete/alternate toolchain); updated `cmakeall.sh` to pass full paths for C/CXX compiler, AR, RANLIB so CMake caches correct toolchain. Added `ARM_TOOLCHAIN_PATH` and fallback to `/Applications/ArmGNUToolchain/*/arm-none-eabi/bin` so the correct toolchain is used even when PATH has `/usr/local/bin` first.
- **Session log**: Session log moved to project root `SESSION_LOG.md`; rule updated so each project keeps its own log in its local directory.

---

## 2026-03-02

- **ROM disk: single row, exclude from TFTP/Format:** ROM disk was shown twice (in PrintDriveList + custom row) and in TFTP/Format. Added `GetDriveListCount()` to exclude ROM disk when last unit. Drives Enable: use listCount for PrintDriveList, show ROM on separate row; fix checkbox rows to `YPOS+i`. TFTP and Format: use GetDriveListCount. `cpanel/ui-misc.c`, `drivesenable.c`, `tftp.c`, `format.c`.
- **Release notes by default:** cmakeall.sh now always includes CHANGELOG.md in the release dir. If `pico/CHANGELOG-NEXT.md` exists, it is copied with `@VERSION@` replaced; else a stub is created. Added V1.1.14-eo CHANGELOG, created CHANGELOG-NEXT.md template. `pico/cmakeall.sh`, `BUILD-REQUIREMENTS.md`.
- **Pico firmware build:** Ran cpanel make + `pico/cmakeall.sh`; built V1.1.14-eo (0x0012). Release UF2s in `_releases/V1.1.14-eo/`.
- **WiFi kept online between sessions:** Destructor no longer disconnects/deinits WiFi; only tears down UDP PCB and buffers. InitCyw43() uses static s_cyw43Inited guard to skip re-init. ConnectWifi() already returns when LINK_UP. Subsequent TFTP/NTP/TestWifi sessions reuse connection. `pico/udptask.cpp`.
- **Build ID left of clock (ProDOS-safe):** Reverted CMD_GETTIMESTR to original 8-byte format for ProDOS compatibility. Added CMD_GETFIRMWAREVER (0x29) to poll build version separately. cpanel DisplayTime calls both: version at cols 20-31, time at 32-39. Boot menu unchanged (time only). `common/defines.h`, `pico/cmdhandler.c`, `cpanel/asm-megaflash.s`.
- **TFTP revert to original state:** Reverted all TFTP-related changes (buffering, session cleanup, timing). Restored from 9159c7e: `udptask.cpp`, `udptask.h`, `tftprxtask.cpp`, `tftprxtask.h`, `flash.c`, `flash.h`. Restored from a6a3498: `network.cpp`, `tftpstate.c`, `tftpstate.h`. Build verified.
- **Drives Enable ROM Disk row fix:** ROM Disk line was drawn at `YPOS+unitCount+1` (same row as last drive/RAM Disk), so it overwrote drive 5. Fixed: `romdiskRow = YPOS+unitCount+2` so ROM Disk is on the row below the last drive. Aligned checkbox rows with `PrintDriveList` (header + unitCount lines): use `YPOS+1+i` for drive i so checkboxes match the printed drive lines; event-loop toggles updated. `cpanel/drivesenable.c`.
- **Pico firmware build:** Ran `pico/cmakeall.sh`; built V1.1.13-eo (0x0011). Release UF2s in `_releases/V1.1.13-eo/`. Added `CHANGELOG.md` (HEARTBEAT revert, ROM Disk row, cpanel).
- **cpanel build:** Added `Beep()` in asm-megaflash.s (cc65 2.18 lacks beep). `#define beep Beep` in asm.h. Fixed drivesenable C89 (const→static_local). Built cpanel.bin.
- **ROM Disk row in Drives Enable:** ROM Disk line was not visible due to wrong row (unitCount+1 overwrote last drive). Fixed: use YPOS+unitCount+1 for ROM Disk row and YPOS+i for drive checkbox rows so ROM Disk appears on the line after the last drive. Event-loop toggles updated. `cpanel/drivesenable.c`.
- **HEARTBEAT_PERIOD reverted 10→50 ms:** 10 ms loop caused upload timeouts and crashes (lwIP re-entrancy risk). Back to 50 ms in `pico/udptask.h`.
- **TFTP session cleanup after cancel/error:** Added `TFTPResetSessionState()` in `tftpstate.c` to reset taskid, blockTransferred, tsize, retries, error, status to IDLE (keeps unitNum, dir, hostname, filename set by DoTFTPRun). Called at the start of `ExecuteTFTP()` in `network.cpp` so each new TFTP run starts clean and does not reuse the previous session. Fixes job not cleaned up and restart reconnecting to previous session. Build V1.1.12-eo.
- **TFTP RX buffering during flash write:** Incoming TFTP DATA packets are now buffered while the RX task is blocked in `WriteBlockForImageTransfer()` (e.g. during sector erase). `flash.c`: added `flash_set_yield_cb()` and yield every ~1 ms in `WaitUntilBusyClear()` so `cyw43_arch_poll()` runs during erase. `udptask`: virtual `OnUDPPacketReceived()` and `DrainOneQueuedPacket()`; callback enqueues when task consumes. `tftprxtask`: 16-slot queue for DATA payloads, `enqueue_data_packets` flag around flash writes, yield callback registered in `Run()`. Event loop drains one queued packet per iteration. Doc §13c in `Implementation-notes-and-reasoning.md`. Build V1.1.11-eo.
- **USB XMODEM vs TFTP write handling:** Documented in `docs/Implementation-notes-and-reasoning.md` (§13b) why USB xmodem/ymodem completes with no delays while TFTP can be slow: same `WriteBlockForImageTransfer()` and ACK-before-write; difference is synchronous USB loop + USB buffering vs event-loop + no `cyw43_arch_poll()` during blocking flash erase.

---

## 2026-03-05

- **UDP/TFTP performance documented:** Added §13 to `docs/Implementation-notes-and-reasoning.md`: symptom (slow TFTP, high error rate), root cause (50 ms HEARTBEAT_PERIOD, blocking flash erase), fix (10 ms period), summary and refs. Updated chronology and §11 summary table.
- **UDP task loop period 50 ms → 10 ms:** `pico/udptask.h` HEARTBEAT_PERIOD changed to 10 ms (was 50 ms) to improve TFTP responsiveness and reduce timeouts/retries. Build produced V1.1.10-eo (0x000e); release files in `_releases/V1.1.10-eo/`.
- **Build V1.1.9-eo and release notes:** Ran `pico/cmakeall.sh`; version bumped to V1.1.9-eo (0x000d). Added `pico/_releases/V1.1.9-eo/CHANGELOG.md` (ROM Disk enable/disable, nDEVSEL pull disabled, ReconfigRomdisk, layout fix).
- **Storage device activation: ROM Disk enable/disable:** Added ROM Disk line to Drives Enable page (cpanel). New config bit ROMDISKFLAG in configbyte1 (1=show ROM disk, 0=hide). UI: row “R  ROM Disk  --  [ ]”, key R toggles; Enter applies and sends EnableRomdiskAtLast() or DisableRomdisk() to Pico. asm: DisableRomdisk() (CMD_DISABLEROMDISK). Pico: ReconfigRomdisk() in Reconfig() applies ROMDISKFLAG; DoAppleColdStart() no longer forces EnableRomdisk (config controls it). Default DEFCFGBYTE1 includes ROMDISKFLAG so new configs show ROM disk.
- **nDEVSEL pull disabled:** `pico/a2bus_rp2040.pio` and `pico/a2bus_rp2350.pio`: replaced `gpio_pull_up(nDEVSEL_GPIO)` with `gpio_set_pulls(nDEVSEL_GPIO, false, false)` so nDEVSEL has no internal pull (driven by Apple bus).
- **Pico build requirements doc:** Added `pico/BUILD-REQUIREMENTS.md` documenting SDK, ARM toolchain, CMake, Control Panel and romdisk prerequisites, build script behaviour, and minimal steps to reproduce the build on another machine. Updated `pico/README.md` to point to it. Added **§1.1 Pico SDK add-ons**: table of required submodules (tinyusb, cyw43-driver, lwip, mbedtls, btstack) and why each is needed for pico_w/pico2_w.
- **cmakeall.sh uses PICO_SDK_PATH:** Script now uses `PICO_SDK_PATH` from the environment when set, with a fallback default; exits with a clear error if the SDK path is missing so another machine can set only the env var.
- **Build and release changelog:** Ran `pico/cmakeall.sh`; build produced V1.1.8-eo (0x000c). Added `pico/_releases/V1.1.8-eo/CHANGELOG.md` summarizing concurrent C0xx ranges, U2 C0C4–C0C7 restriction, U2 read-back fix, C0C4 LED, build/release behaviour, and doc/GPIO notes.

---

- **A2/A3 pulldowns disabled**: `pico/a2bus_rp2040.pio` and `pico/a2bus_rp2350.pio`: `gpio_set_pulls(A2ABUS_BASE+2/3, false, true)` → `(false, false)` so A2 and A3 have no pull-ups or pull-downs (driven by Apple bus).
- **Pico firmware rebuilt**: Updated `pico/cmakeall.sh` to pass `-DPICO_SDK_PATH=/Users/eositis/pico-sdk`, reconfigured all CMake builds, and built release UF2 images: `pico_release/megaflash.uf2` (Pico W) and `pico2_release/megaflash.uf2` (Pico 2 W).
- **Build script version bump**: `pico/cmakeall.sh` now increments version and date on each run: reads `FIRMWAREVER`/`FIRMWAREVERSTR` from `defines.h`, bumps patch and hex version, appends `-eo` to string, sets build date, updates `defines.h` and appends a comment line. Fixed hex parsing to use `awk '{print $3}'`. Built firmware at V1.1.6-eo (0x000a).
- **Release output by version**: `pico/cmakeall.sh` builds release targets then copies `megaflash.uf2` from `pico_release` and `pico2_release` into `_releases/<version>/` as `megaflash-pico.uf2` and `megaflash-pico2.uf2` (e.g. `_releases/V1.1.7-eo/`).
- **Uthernet II read-back fix**: $C0C4–$C0C7 reads were returning 0 because U2 read data was merged into PIO chunk 0 ($C0C0–$C0C3). C0C4–C0C7 are served by chunk 1 (SM1). `pico/busloop.c`: U2 read path now updates `registers.i32[1]` and calls `UpdateMegaFlashRegisters(1, merged)` so Mode Register read (e.g. after C0C4:80, C0C4:03) returns 0x03.
- **Implementation reasoning doc**: Added `docs/Implementation-notes-and-reasoning.md` documenting root-cause analysis, design decisions, and references for U2 address/chunk fix, A2/A3 pulldowns, build script (PICO_SDK_PATH, version bump, release folder), and debug mode.
- **C0C4 diagnostic LED**: In `pico/busloop.c`, any access to $C0C4 (U2 Mode Register) turns on the activity LED (ACT_LED_PIN) for 1 second; LED-off is handled non-blocking via `time_reached()` so the bus loop is not blocked.
- **nDEVSEL pull-up disabled**: `pico/a2bus_rp2040.pio` and `pico/a2bus_rp2350.pio`: `gpio_pull_up(nDEVSEL_GPIO)` → `gpio_set_pulls(nDEVSEL_GPIO, false, false)` so nDEVSEL has no internal pull; driven by Apple bus.
- **C0C4 not seen by firmware**: Documented in `docs/Implementation-notes-and-reasoning.md` (§2b): PIO only pushes a cycle when **nDEVSEL (GPIO 20) goes low**; if nDEVSEL doesn’t go low (wrong slot, or floating after pull-up was removed), the CPU never sees the access. Re-enabled **nDEVSEL pull-up** in both PIO files so the line is held high when not selected and the PIO sees a clean low when the card is selected.
- **Implementation notes expanded**: `docs/Implementation-notes-and-reasoning.md` updated with chronology, version-bump script bugs (grep/tr), GPIO pull summary (§8), C0C4 diagnostic LED (§9), reverted nDEVSEL-invert attempt (§10), and open issue “C0C4 not seen” with next steps (§12). Clarified RP2040/RP2350 data path in §2b.
- **Document-thinking rule**: Added `.cursor/rules/document-thinking.mdc` so the agent always records reasoning in SESSION_LOG (brief) and in `docs/Implementation-notes-and-reasoning.md` (root cause, dead ends, takeaways) for future reference and learning.
## 2025-03-02

... (entries above unchanged) ...

- **U2 bus loop (colleague’s approach)**: Replaced merge-into-chunk logic with shadow-register approach in `pico/busloop.c`: on U2 read set `registers.r[addr] = u2_read_byte` then `UpdateMegaFlashRegisters(1, registers.i32[1])`; condition `addr >= U2_C0X_OFFSET` (no U2_C0X_LAST in snippet). C0C4 diagnostic LED kept.
- **Concurrent C0xx ranges**: Documented in `busloop.c` and `docs/Implementation-notes-and-reasoning.md` (§1b): C0C0–C0C3 (MegaFlash), C0C4–C0C7 (U2), and C0C8–C0CF (future ACIA) are concurrently active; decode by address only. U2 restricted to 4–7 (`addr <= U2_C0X_LAST`) so C0C8–C0CF remain for ACIA.

## 2026-03-17

- **Planned network refactor documented:** Extended `docs/Implementation-notes-and-reasoning.md` with §14 describing a future NetworkPump + INetworkSession architecture so NTP, TFTP, TestWifi, and Uthernet II TCP/UDP can share cyw43/lwIP concurrently, and how to abort/reset all sessions cleanly on Apple II reset.
- **NetworkPump skeleton added:** Created `pico/network_pump.h` and `pico/network_pump.cpp` defining a preliminary `NetworkPump` and `INetworkSession` interface (WiFi init/connection helpers, UDP/TCP pcb helpers, stubbed session/timer/abort APIs). Added `network_pump.cpp` to `pico/CMakeLists.txt`. No existing code uses the pump yet, so runtime behaviour is unchanged; this is groundwork for migrating NTP/TFTP/Uthernet II to a shared pump later.
- **TFTP lifecycle moved into manager:** `ExecuteTFTP()` now delegates to `NetworkPump::RunTFTP(...)` so the manager owns TFTP start/finish bookkeeping and reset-abort routing. Added `NetworkPump_RequestAbortAll()` and changed the Apple reset ISR to call it, while keeping the legacy TFTP packet engine intact for now. Built Debug Pico/Pico 2 targets successfully after the change.
- **Apple ROM debug enabled:** Set `firmware/buildflags.inc` `DEBUG` to `TRUE` so the 6502 ROM prints Serial Port 1 debug at 19200 baud. Attempted `make a2c` / `make a2cp`, but the build is currently blocked because `rom4.bin` and `rom5.bin` are not present in the workspace; the ROM build needs those Apple II ROM images in `firmware/` before it can complete.
- **Apple ROM debug built successfully:** Re-ran `make a2c` and `make a2cp` after `rom4.bin` / `rom5.bin` were available in `firmware/`; both completed and produced `iic.bin` and `iicplus.bin` with `DEBUG` enabled.
- **Control Panel TFTP safeguard:** Added a debug safety check in `cpanel/tftp.c` so the TFTP upload screen detects a filename that looks like an IPv4 address, warns the user, and swaps host/file before sending. Built `cpanel.bin` successfully. This was added after debug traces showed the Apple-side TFTP command being populated with a swapped or stale host/file pair.
- **Pico debug rebuild after Control Panel change:** Rebuilt `pico_debug` and `pico2_debug` after updating `cpanel.bin`, so the Pico firmware image now packages the new Control Panel code (`cpanel.s` was rebuilt as part of the Pico target).
- **Control Panel release repackaged into Pico:** Reconfirmed the non-debug Control Panel build path (`make release`) and repackaged the Pico debug targets so the bundled `cpanel.bin` remains the release build while the Pico firmware is rebuilt around it.
- **Versioned release build:** Ran `./cmakeall.sh` to bump the firmware to `V1.1.20-eo` (`0x0018`), rebuild the release firmware, and write `_releases/V1.1.20-eo/CHANGELOG.md`. The generated release notes now include the network stack work: `NetworkPump`/`INetworkSession` skeleton, TFTP lifecycle routing through the manager, the host/file swap safeguard, and the new debug logging details.
- **USB console not responsive on PicoW when powered from USB (no Apple II):** Fixed in `pico/main.c` by running `UserTerminal()` on the USB console when `CheckPicoW()` is true but `IsAppleConnected()` is false, instead of immediately entering `core0Loop()` (network loop). Rebuilt `pico_debug` and `pico2_debug`. (Treat as v1.1.x hotfix.)

---

*Append new entries above this line, with date and brief description of changes/commands/decisions.*

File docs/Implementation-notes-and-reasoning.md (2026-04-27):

# Implementation Notes and Reasoning

This document records the thinking, root-cause analysis, design decisions, and dead ends from work on the MegaFlash Pico firmware (Uthernet II, build, GPIO, C0C4 visibility). It is intended for future maintainers and for debugging similar issues.

---

## Chronology and context (from session work)

- **Version series:** **V1.1.24-eo** is the last **1.1.x** maintenance release. Ongoing work targets **1.2.x** starting from **V1.2.0-eo** (`0x0020` in `pico/defines.h`), focused on **Uthernet II emulation**, **com port**, and **imagewriter emulation**.
- **ip65 / Uthernet II:** U2 emulation was adapted so the ip65 stack (no changes to ip65) works: RECV command advances RX_RD to sn_rx_wr; socket CR is cleared to 0 after each command; default RMSR/TMSR = 0x06; MACRAW RX is fed by wrapping netif->input when socket 0 is opened in MACRAW. U2 debug logging uses prefix `[u2]` and is gated by UTHERNET2_DEBUG (Debug build only), not NDEBUG. See `docs/ip65-Uthernet-II-integration.md`.
- **Uthernet II**: Confirmed U2 at $C0C4–$C0C7 only; no GPIO slot select. Fixed read-back of Mode Register (chunk 1 vs chunk 0). (Earlier: C0C4 diagnostic LED — **removed** in 1.2.x; see §9.)
- **GPIO pulls**: A2/A3 pulldowns disabled (bus-driven). nDEVSEL pull-up first disabled at user request, then re-enabled when C0C4 was not seen; with pull-up enabled, C0C4 still not recognized.
- **Build**: PICO_SDK_PATH added to cmakeall.sh; version bump + “-eo” + date on each build; version-bump script fixed (grep uniqueness, strip newlines); release UF2s copied to `_releases/<version>/`.
- **C0C4 not seen**: Logic analyzer shows A0–A4 (and presumably address) at the Pico, but firmware never sees the access (no response). Conclusion: PIO only pushes a cycle when **nDEVSEL (GPIO 20) goes low**; if it does not go low for that access, the CPU never gets the cycle. Tried inverting nDEVSEL sense (trigger on pin HIGH = DEVSEL active-high); **reverted** at user request. nDEVSEL sense remains active-low.
- **TFTP/UDP performance**: TFTP was slow and had high error rate. Root cause: 50 ms HEARTBEAT_PERIOD in udptask added up to 50 ms latency per UDP packet, and blocking flash sector erase (~220–250 ms every 16 blocks) stalled the event loop. No documented reason for 50 ms. HEARTBEAT_PERIOD reduced to 10 ms to improve TFTP (and NTP/Test WiFi) responsiveness (see §13).

---

## 1. Uthernet II at $C0C4–$C0C7 (address decode)

**Requirement:** Uthernet II (W5100) should respond to slot 4 addresses $C0C4–$C0C7 only; MegaFlash uses $C0C0–$C0C3.

**Reasoning:**
- The Apple II slot address is the low nibble of the address: $C0C0 → 0, $C0C4 → 4, etc.
- No GPIO slot-select pin is used; decode is by address only (`defines.h`: `U2_C0X_OFFSET` = 4, `U2_C0X_LAST` = 7).
- In `busloop.c`, when `addr >= 4 && addr <= 7` we call `U2_HandleBusAccess`; otherwise we handle MegaFlash (0–3) or other (8–15).
- W5100 indirect access uses four “ports”: C0x4 = Mode Register, C0x5 = Address High, C0x6 = Address Low, C0x7 = Data. The C code uses `busdata & 3` (U2_C0X_MASK) to map 4→0, 5→1, 6→2, 7→3 into W5100 port indices.

**References:** `pico/defines.h`, `pico/busloop.c`, `pico/uthernet2.c`, `pico/w5100_regs.h`.

---

## 1b. C0xx ranges are concurrently active (not mutually exclusive)

**Design:** C0C0–C0C3 (MegaFlash), C0C4–C0C7 (Uthernet II), and the reserved C0C8–C0CB / C0CC–C0CF (future ACIA) are **concurrently available**. The card responds to all of them; which handler runs is determined **only by the address** of the current bus cycle. They are not mutually exclusive (e.g. “slot in U2 mode” vs “slot in MegaFlash mode”) but rather decode by address so that MegaFlash base, U2, and (future) ACIA can all be active at once.

**In code:** The bus loop decodes `addr` (low nibble): 0–3 → MegaFlash (command, param, data, ID); 4–7 → Uthernet II only (`addr >= U2_C0X_OFFSET && addr <= U2_C0X_LAST`); 8–15 left for future ACIA. U2 is restricted to 4–7 so that 8–11 and 12–15 are not consumed by U2 and remain available for ACIA emulation.

**References:** `pico/busloop.c` (address-decode comment and U2 condition).

---

## 1e. U2 activity monitor (`[u2m]`, Debug build)

**What:** Structured tracing of Uthernet II emulation for serial capture (UART 115200).

**Why:** Separate from `[u2]` `U2_DEBUGF` printf-in-place: bus cycles run on **core 1** while lwIP runs on **core 0**, so `printf` from both cores is unsafe. Events are **queued** under a critical section and **drained** from `U2_Poll()` (core 1) as `[u2m]` lines.

**What we did:** `u2_monitor.c` / `u2_monitor.h`; ring 128, up to 48 events flushed per `U2_Poll`; records **every** `$C0C4–$C0C7` bus op (Rd/Wr MODE/ADDRHI/ADDRLO/DATA, `busdata`, byte, internal `ptr`, MR), **reset**, **socket OPEN/CONNECT/LISTEN/CLOSE/SEND/RECV**, **UDP/TCP/MACRAW** net TX/RX. **CMake Debug** defines `U2_ACTIVITY_MONITOR=1`; Release compiles stubs. **`./build-debug.sh`** builds `pico_debug` + `pico2_debug`.

**References:** `pico/u2_monitor.c`, `pico/uthernet2.c`, `pico/uthernet2_net.cpp`, `pico/CMakeLists.txt`, `pico/build-debug.sh`, `pico/README.md`.

---

## 1d. RP2350: U2 branch skipped PIO IRQ 0 wait (ip65 “Device not found”)

**Symptom:** ip65 / telnet65 still reported **Device not found** despite correct RTR emulation and slot 4.

**Why:** On **RP2350**, `a2bus` sets **IRQ 0** while delaying the `rxfifo` pull (`a2bus_rp2350.pio`). The bottom of `BusLoop()` waits for IRQ 0 to clear before `UpdateMegaFlashRegisters`, so the SM finishes reading the **current** cycle’s FIFO value before the CPU overwrites it. The **Uthernet II** branch called `UpdateMegaFlashRegisters(1, …)` and then **`continue`**, **skipping** that wait. That can corrupt **$C0C4–$C0C7** read-back and make the ip65 **W5100 RTR XOR** probe at `$0017/$0018` fail (same user-visible message as a missing card).

**What we did:** Before `UpdateMegaFlashRegisters(1, …)` inside the U2 branch, added the same `pio_interrupt_get` wait as the main loop (guarded with `#ifndef PICO_RP2040`). Initially this mirrored the main loop’s `pio_sm_is_rx_fifo_empty` guard; that guard was **removed on the U2 path only** so IRQ 0 always clears before updating chunk 1 — skipping the wait when the RX FIFO was non-empty could still leave **$C0C4–$C0C7** stale and break the ip65 RTR XOR (wget65 / telnet65 “device not found” with slot 4 correct).

**Also:** `write_common_register()` in `uthernet2.c` now stores **RTR / RCR / PTIMER** and other **$0001–$002F** gaps that were previously no-ops on write (real W5100 retains those bytes).

**RP2350 store visibility:** `UpdateMegaFlashRegisters()` (`pico/a2bus.h`) uses **`pio0->rxf_putget[SM_A2BUS][chunk] = value`**. Added **`__dmb()`** after that store so the **PIO** sees the new chunk word before the next **`mov osr, rxfifo[y]`**. Symptom without it: **UART** `[u2] DATA read` shows correct **$0017/$0018** bytes (emulator path) but **only two** trace lines and **wget** “no device found” — **6502** `eor` XOR still fails because the **bus** latched a **stale** FIFO byte (same class of issue as §1f).

**PIO timing (pull earlier):** `a2bus` originally used **long** side-delays (`[7]`…`[6]`) before **`mov osr, rxfifo[y]`** so the CPU had time after the previous cycle — but that also **delayed** the first **`out pins`** into the slot **read** window. If the **6502** samples the data bus before the PIO drives the correct byte, **`w5100.s`** sees **garbage** while a **later** C snapshot matches emulation. **Tighter** pre-FIFO delays (`[3]`…`[1]`) aim to present the byte **earlier**; **IRQ 0** still blocks **`UpdateMegaFlashRegisters`** until the SM has pulled the **current** cycle’s FIFO value. **`__dsb`** after **`__dmb`** on **`rxf_putget`** write strengthens store completion before the SM can pull.

**U2 hot path in SRAM (RP2350):** Between IRQ 0 clear and **`UpdateMegaFlashRegisters(1,…)`**, only **CPU cycles** remain. **`U2_HandleBusAccess`**, **`U2_PeekDataPort`**, **`read_value` / `read_value_at`**, **`write_*`**, **`auto_increment`**, **`write_common_register`**, **`set_rx_sizes` / `set_tx_sizes`** are placed in **`.time_critical.*`** (**`__time_critical_func`**) so they execute from **RAM**, not **XIP flash** — fewer wait states on every **`$C0C4–$C0C7`** access. **`read_socket_register`** (socket block) stays in flash; ip65 **RTR** path uses **common** memory via **`read_value_at`** only.

**References:** `pico/busloop.c`, `pico/a2bus_rp2350.pio` (`irq set 0` / `mov osr,rxfifo[y]` / `irq clear 0`), `pico/a2bus.h`, `pico/uthernet2.c` (`write_common_register`).

---

## 1c. telnet65 “Device not found” vs ip65 W5100 `init` (MegaFlash U2)

**What:** `ip65/apps/telnet65.s` calls `ip65_init` with `A = eth_init_default` (`ip65/drivers/a2init.s`, slot **4** for MegaFlash). On failure it prints **“Device not found”** (`ip65_init` returns carry).

**Why:** `ip65_init` → `eth_init` → Contiki/ip65 **`drivers/w5100.s`** `init`. The **only** path that returns **`SEC`** before socket setup is the **RTR fingerprint** at addresses **$0017 / $0018**: two reads with XOR must produce zero (default **$07,$D0**). Any wrong values (open bus, wrong slot, or bad emulation) → probe fails → “Device not found.” After that, if **RMSR == $06**, ip65 **skips** the software-reset block that **writes SHAR** but still **reads SHAR back** into the driver MAC and then `ethernetcombo.s` copies that into **`cfg_mac`**. With SHAR all zeros, **station MAC is invalid** (DHCP/ARP issues) even though the probe passed.

**What we did:** `u2_reset()` already matched **RTR/RMSR/TMSR** for the probe; added default **SHAR** = same bytes as **`w5100.s`** (`00:08:DC:A2:A2:A2`) so the short init path gets a sane MAC.

**What we didn’t do:** Cannot fix “no device” from firmware if the CPU never addresses **slot 4** `$C0C4–$C0C7` or **nDEVSEL** does not assert (see §2b/§12).

**References:** `ip65/ip65/ip65.s` (`ip65_init`), `ip65/drivers/ethernetcombo.s` (`eth_init`/`init_adaptor`), `ip65/drivers/w5100.s` (`init` through RTR XOR and RMSR branch), `ip65/apps/telnet65.s`, `pico/uthernet2.c` (`u2_reset`).

**UART symptom:** Only one `[u2] mode=0x03…` line then “Device not found” is **normal** for `U2_DEBUGF` volume — the RTR probe uses **ADDRHI/ADDRLO + DATA** reads, which did not log. **Debug** builds also print **`RTR data read addr=0x0017 -> …`** / **`0x0018`** (first 8 such reads per boot) so captures show whether the 6502 reached the probe and got **0x07** / **0xD0**. If those lines never appear, bus cycles are not completing to the DATA port; if values are wrong, XOR fails and `eth_init` returns carry.

**Reconciling UART with the screen:** In stock **`ip65/drivers/w5100.s`**, the **only** **`sec` / `rts`** in **`init`** is the **RTR XOR** failure; after OPEN, **`init` ends with `clc` / `rts`**. **`ip65_init`** only branches to the device-failure path on **`eth_init` carry**; if **`eth_init` clears carry**, **`ip65_init` always ends with `clc` / `rts`** (it unconditionally **`clc`** after `timer_init` / `arp_init` / `ip_init`). So a capture that shows **correct RTR** (`0x0017`/`0x0018`) for the **same** telnet65 attempt **contradicts** a stock **`“Device not found”`** from **`ip65_init`** unless the Apple disk is **not** stock ip65, there is **carry corruption** (extraordinary), or the on-screen line is being **misattributed** to the same UART window. **MegaFlash policy:** do **not** patch ip65 for Uthernet II — fix behaviour in **`pico/`** emulation only so stock ip65 remains the reference.

**UART deep trace (Debug):** On **`MR=0x03`**, firmware arms **48** DATA-read trace events. **`printf` must not run inside `U2_HandleBusAccess`** (same for socket **CR** handling): blocking UART stalls the bus loop so the Apple can see wrong or incomplete cycles; only **`[u2m]`**-style **queue + `U2_MonPollFlush`** from **`U2_Poll`** is safe. **`[u2]`** mode and DATA lines use **`U2_MonQueueModeLine` / `U2_MonDataReadTrace`**; **`busloop.c`** polls **`U2_Poll`** every **32** Uthernet accesses (was 500) so the ring drains. Monitor ring/flush sizes were increased (**256** / **128**).

**Reconciling example log:** `debug/2026-03-21 21-42-20 FT232R USB UART #1.log` — **21:45** / **22:06** mode-only vs **22:14** / **22:26** with **correct RTR**; **DHCP** failures use **`- Error $…`** (`print_error`), not the **device not found** string.

---

## 1f. Manual monitor: two DATA reads both $07 (no advance to RTR1)

**Symptom:** After loading indirect address **$0017** via **$C0C5** / **$C0C6**, the **first** read of **$C0C7** returns **$07** (RTR0 — correct), but the **second** consecutive **$C0C7** read is **also** **$07** instead of **$D0** (RTR1).

**Why (W5100 + this firmware):** Auto-increment of the internal pointer after a DATA read happens only when **MR bit 1** (**`W5100_MR_AI`**, value **$02**) is set. **`read_value()`** in `uthernet2.c` always calls **`auto_increment()`** after the read, but **`auto_increment()`** is a no-op unless **`u2_mode_register & W5100_MR_AI`**. After **`u2_reset()`**, **MR is $00**, so **no** increment until the host writes **$03** (IND+AI, as in ip65) to **$C0C4**. If MR is **$01** (indirect without AI), behaviour matches the real part: repeated DATA reads keep returning the same byte.

**What to verify:** **`LDA $C0C4`** (read Mode Register) must show **$03** (or at least **bit 1 set**) *before* or *between* address setup and the two DATA reads. If it reads **$00** / **$01**, repeat **`LDA #3` / `STA $C0C4`** (slot 4), then reload **$0017** and try again. Optionally read **$C0C5** / **$C0C6** after the first **$C0C7** read: with AI on, the pointer should show **$0018**.

**References:** `pico/uthernet2.c` (`read_value`, `auto_increment`, `u2_reset`), `pico/w5100_regs.h` (`W5100_MR_AI`, `W5100_RTR0` / `W5100_RTR1`).

**Observed variant (bench):** Three consecutive **DATA** reads returned **`$D0`, `$07`, `$D0`**. In our image, **`$0017`→RTR0=`$07`**, **`$0018`→RTR1=`$D0`**, so that triplet is **RTR1, RTR0, RTR1** — the internal pointer behaved like **`$0018` → `$0017` → `$0018`**, not like a monotonic **`$0017` → `$0018` → `$0019`** (which would be **`$07`, `$D0`, `$08`** with default **RCR=`$08`**). Causes to rule out on the bench: (1) **pointer was `$0018`** before the first read (e.g. **`C0C6:18`** or leftover state) — then the **second** byte should be **`$08`** (RCR at `$0019`), not **`$07`**, unless something **reloaded** the address to **`$0017`** between reads; (2) **monitor or test code** touched **`$C0C5`/`$C0C6`** between **`$C0C7`** reads; (3) **stale / reordering** on the data path (compare with **§1d** and pointer dumps below).

**Screenshot (correct setup):** After **`C0C4:03`**, **`C0C5:00`**, **`C0C6:17`**, verify reads **`C0C5`/`C0C6` → `00`/`17`**, then **`C0C7`** returned **`$08`**, **`$07`**, **`$D0`** — i.e. **RCR, RTR0, RTR1** (`$0019`, `$0017`, `$0018`) while the **address registers still showed `$0017`** before the first DATA read. **Why:** On **RP2350**, the **a2bus** SM **prefetches** the chunk‑1 FIFO value for the **next** 6502 read **before** the CPU finishes handling the **previous** cycle (see **§1d**). **`registers.r[7]`** (the **`$C0C7`** shadow) was only updated **during** a DATA read, so after **`C0C6`** it still held whatever was left from an earlier cycle — not **`read_value_at($0017)`=`$07`**. The 6502 then latched a **stale** eighth byte for the first **`$C0C7`** read; the emulator’s internal pointer still advanced correctly, so later reads matched **RTR0/RTR1**.

**What we did:** After every U2 bus op, **`registers.r[7] = U2_PeekDataPort()`** (next DATA byte without increment) before **`UpdateMegaFlashRegisters(1,…)`**, so the PIO’s prefetched **`$C0C7`** byte matches **`read_value()`** for the **next** access. **`U2_PeekDataPort`** in **`uthernet2.c`** / **`uthernet2.h`**; **`busloop.c`** U2 branch.

**What we didn’t do:** No change to W5100 memory layout or RTR defaults; RP2040 gets the same priming (harmless and keeps shadow consistent).

**Verified (bench):** Monitor sequence after the fix returns **`$07`**, **`$D0`**, **`$08`** for three consecutive **`$C0C7`** reads with pointer **`$0017`** and **MR=`$03`**.

---
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

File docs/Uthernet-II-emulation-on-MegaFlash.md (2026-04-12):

# Uthernet II Emulation on MegaFlash

This document describes the Uthernet II (W5100) emulation implemented in the MegaFlash firmware. Slot selection uses the **default MegaFlash bus behaviour** (no GPIO slot-select pin); the card responds when the bus is active for its slot.

---

## 1. Overview

- **Purpose:** Emulate a Uthernet II Ethernet card in slot 4 so that W5100-based Apple II software (TCP/UDP) can use the Pico’s network (lwIP over CYW43 WiFi on Pico 2 W).
- **Selector:** Address decode only: **C0x4–C0x7** ($C0C4–$C0C7) = Uthernet II; **C0x0–C0x3** ($C0C0–$C0C3) = MegaFlash. No GPIO pin is used for slot select.
- **Design reference:** AppleWin’s **`Uthernet2.cpp`** / **`W5100`** logic (register semantics, RTR defaults, `IO_C0`); network backend here is lwIP/CYW43, not PCap/Windows.
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

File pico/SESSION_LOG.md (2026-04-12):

## 2026-04-10
- **`build-both.sh`:** Passes **`U2_ETH_HEADER_TRACE`** (**default** **0**); **`U2_ETH_HEADER_TRACE=1 ./build-both.sh`** builds **Release** with UART **`[u2eth]`** trace. Verified **`pico2_release`** **`CXX_DEFINES`** includes **`U2_ETH_HEADER_TRACE=1`**.

- **`U2_ETH_HEADER_TRACE`:** Optional UART **`[u2eth]`** hex (**first** **64** **B** per **STA** **TX**/**RX** **frame**) via **`netif`** **wrap** **in** **`uthernet2_net.cpp`**; **CMake** **`U2_ETH_HEADER_TRACE`** (**default** **0**); **`U2_ETH_HEADER_TRACE=1 ./build-debug-both.sh`**. **§1j** **tracing** **paragraph** **`docs/Implementation-notes-and-reasoning.md`**.
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

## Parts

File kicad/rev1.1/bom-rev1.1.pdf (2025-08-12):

Reference | Value | Qty | Description | Manufacturer | Mfr Part No | Mouser Part No
C1,C2,C3,C5,C6,C7,C8 0.1uF | 7 | Ceramic Capacitor, 5mm Lead Spacing | Vishay | K104K15X7RF5WH5 594-K104K15X7RF5WH5
C4 | 10uF | 1 | (Optional) Electrolytic Capacitor, 2mm Lead Spacing | Wurth Elektronik 860010372001 | 710-860010372001
D1 | 1N5817 | 1 | 20V 1A Schottky Barrier Rectifier Diode, DO-41 | Vishay | 1N5817-E3/53 | 625-1N5817-E3/53
J1 | EXPSLOT | 1 | 2 Row Pin Header 2.54mm Pitch 19mm Length | Samtec | TSW-117-15-G-D | 200-TSW11715GD
R1,R2 | 100k | 2 | 100k Through Hole Resistor
RN1,RN2,RN3 | 100k | 3 | 100k Resistor Array, 9-pin sip | Bourns | 4609X-101-104LF | 652-4609X-1LF-100K
U1,U2 | 74LVC8T245 | 2 | Dual Supply Bus Transceiver, SOIC-24 | TI | SN74LVC8T245DWR 595-SN74LVC8T245DWR
U3 | GAL16V8 | 1 | GAL16V8, DIP-20 | Lattice
U4 | Pico | 1 | Raspberry Pi Pico 2W
U5,U6 | W25Q01JVSF | 2 | SPI NOR Flash 1Gbit, SOIC-16 | Winbond | W25Q01JVSFIM | 454-W25Q01JVSFIM

Note: One Winbond W27C257 or W27E257 EEPROM is needed to replace the system ROM.
Capacitor C4 is a filter capacitor of 5V rail. It is optional.

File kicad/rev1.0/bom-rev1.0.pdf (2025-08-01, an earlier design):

Reference | Value | Qty | Mouser Part No | Description
C1,C2,C3,C6,C7,C8,C9 0.1u | 7 | 0805 Ceramic Capacitor
C4,C5 | 22uF | 2 | 80-T491B226K010 | 3528 Tantalum Capacitor
D1,D2 | SS12 | 2 | 625-SS12-E3 | 20V 1A Schottky Diode, SMA
J1 | EXPSLOT | 1 | 200-TSW11715GD | 2 Row Pin Header 2.54mm Pitch 19mm Length
RN1 | 47k | 1 | | 4 resistor network, 4x0603
U1 | 74LVCH16T245DLR | 1 | 595-SN74LVCH16T245LR 16-Bit Dual-Supply Bus Transceiver
U2 | GAL16V8 | 1 | | GAL16V8 PLCC-20 Package
U3 | AMS1117-3.3 | 1 | | 1A Low Dropout regulator, positive, 3.3V fixed output, SOT-223
U4 | Pico | 1 | | Raspberry Pi Pico 2W
U5,U6 | W25Q01JVZE | 2 | 454-W25Q01JVZEIMTU | 128MB NOR Flash, WSON-8 Package

Note: One Winbond W27C257 or W27E257 EEPROM is needed to replace the system ROM.

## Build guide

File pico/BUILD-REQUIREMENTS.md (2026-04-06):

# Pico firmware — build requirements

This document describes what is needed to build the MegaFlash Pico firmware on a new machine so that the same UF2 images can be recreated.

## Supported hosts

- **Linux** — x86_64 or **aarch64** (ARM64). Install `gcc-arm-none-eabi` / CMake from your distro (or Arm’s tarball for **aarch64** if you need a specific GCC version).
- **macOS** — **Apple Silicon (ARM64)** and Intel. On Apple Silicon, **Homebrew** lives under **`/opt/homebrew`** (not `/usr/local`). Use the **macOS arm64 / darwin-aarch64** build of the [Arm GNU Toolchain](https://developer.arm.com/downloads/-/arm-gnu-toolchain-downloads) when installing the `.pkg`, or `brew install arm-none-eabi-gcc`. `sed` behaviour matches BSD sed (see §6).

## 1. Raspberry Pi Pico SDK

The firmware uses the official [Raspberry Pi Pico C/C++ SDK](https://github.com/raspberrypi/pico-sdk). The SDK is **one source tree** for all host CPUs (Intel Mac, Apple Silicon, Linux x86_64/aarch64); there is no separate “ARM SDK” package—clone it on your ARM machine the same way and point **`PICO_SDK_PATH`** at it (or use **`~/pico-sdk`** as below).

- **Obtain:** Clone the repo, then initialize **all required submodules** (see list below):
  ```bash
  git clone https://github.com/raspberrypi/pico-sdk ~/pico-sdk
  cd ~/pico-sdk
  git submodule update --init
  ```
  If you use a release tag, check out the tag before running `git submodule update --init` so submodule commits match that release.
- **Version:** Use a recent stable release or the tag that matches your SDK clone. The project has been built with SDK versions that support both **Pico W (RP2040)** and **Pico 2 W (RP2350)**.
- **Path:** Set the environment variable **`PICO_SDK_PATH`** to the absolute path of the SDK directory (e.g. `export PICO_SDK_PATH=/path/to/pico-sdk`).  
  If unset, **`cmakeall.sh`** and **`build-both.sh`** default to **`$HOME/pico-sdk`**, and **`CMakeLists.txt`** uses the same **`$ENV{HOME}/pico-sdk`** fallback so bare `cmake` runs work. On **Apple Silicon**, keeping the clone at **`~/pico-sdk`** matches the defaults and avoids editing the repo.

### 1.1 Pico SDK add-ons (externals / submodules) required for this build

The MegaFlash firmware is built for **Pico W** and **Pico 2 W**, which use Wi-Fi (and optionally Bluetooth). The following SDK externals are **required**; they are Git submodules of `pico-sdk` and must be present after `git submodule update --init`:

| Submodule | Path in SDK | Purpose |
|---|---|---|
| **tinyusb** | `lib/tinyusb`  | USB stack (stdio over USB, device support) |
| **cyw43-driver** | `lib/cyw43-driver` | Wi-Fi/Bluetooth driver for Pico W and Pico 2 W |
| **lwip** | `lib/lwip` | TCP/IP stack (UDP, TCP, DHCP, DNS; used with CYW43 for networking) |
| **mbedtls** | `lib/mbedtls`  | TLS/crypto (used by CYW43 and Wi-Fi auth) |
| **btstack** | `lib/btstack`  | Bluetooth stack (Pico W / Pico 2 W Bluetooth support) |

The project links `pico_cyw43_arch_lwip_poll` (see `CMakeLists.txt`), which pulls in **cyw43-driver** and **lwip**; **tinyusb** is used for USB stdio; **mbedtls** and **btstack** are brought in by the SDK when building for `pico_w` / `pico2_w`. If any of these are missing, CMake configuration or the build will fail. Ensure all five submodules are initialized (no need to clone them separately — `git submodule update --init` from the SDK root fetches them).

## 2. ARM GCC toolchain (bare-metal)

The RP2040 and RP2350 are built with the **arm-none-eabi** toolchain (no OS, bare-metal).

- **Required programs:** `arm-none-eabi-gcc`, `arm-none-eabi-g++`, `arm-none-eabi-ar`, `arm-none-eabi-ranlib` (and `arm-none-eabi-as` via gcc).
- **Obtain:**
  - **macOS:** [Arm GNU Toolchain for Arm Embedded Processors](https://developer.arm.com/downloads/-/arm-gnu-toolchain-downloads) (e.g. “Arm GNU Toolchain arm-none-eabi”). Pick the installer matching your Mac: **darwin-aarch64** on Apple Silicon, **darwin-x86_64** on Intel. Install so that the `arm-none-eabi/bin` directory is available; the scripts look under `/Applications/ArmGNUToolchain/*/arm-none-eabi/bin`, then **`/opt/homebrew/bin`** and **`/usr/local/bin`** (Homebrew), then **`PATH`**, or use **`ARM_TOOLCHAIN_PATH`** (see below).
  - **Not enough for Pico:** **`brew install arm-none-eabi-gcc`** provides a cross-GCC **without newlib** (no **`nosys.specs`**). The Pico SDK boot stage and C runtime need the **full** Arm GNU Embedded toolchain. Use the **.pkg** from Arm (correct host arch), not Homebrew’s standalone GCC, unless you know you have a complete newlib layout.
  - **Linux:** Install the package (e.g. `sudo apt install gcc-arm-none-eabi` on Debian/Ubuntu) or use the Arm GNU Toolchain tarball for **aarch64** or **x86_64** matching your host.
- **Important:** The build script explicitly passes the C/C++/AR/RANLIB paths to CMake so that the correct toolchain is used (e.g. on macOS, Xcode’s `ranlib` must not be used). Use a toolchain that provides `nosys.specs` and is intended for bare-metal.
- **Optional override:** Set **`ARM_TOOLCHAIN_PATH`** to the **bin** directory containing `arm-none-eabi-gcc` (e.g. `export ARM_TOOLCHAIN_PATH="/Applications/ArmGNUToolchain/12.3.rel1/arm-none-eabi/bin"`) to force a specific toolchain.

## 3. CMake and Make

- **CMake:** Version **3.13 or later** (up to 3.27). The top-level `CMakeLists.txt` requires `cmake_minimum_required(VERSION 3.13...3.27)`.
- **Make:** Standard `make` for the configured build directories.

Install via your system package manager or from [cmake.org](https://cmake.org/download/) — on **Apple Silicon**, install the **macOS arm64** build (or `brew install cmake` into **`/opt/homebrew`**).

- **Scripts (`cmakeall.sh`, `build-both.sh`, `build-debug.sh`):** They **`source build-env.sh`**, which sets **`CMAKE_BIN`** to the first executable found among **`/opt/homebrew/bin/cmake`** (Apple Silicon Homebrew), **`/usr/local/bin/cmake`** (Intel Mac / some Linux), then **`cmake`** on **`PATH`**. That avoids using an old **x86_64** CMake when an **arm64** one exists. Override with **`export CMAKE=/path/to/cmake`**.
- **Hand-invoked `cmake`:** If you configure build dirs yourself, call the same binary (e.g. **`/opt/homebrew/bin/cmake`**) or put **`/opt/homebrew/bin`** early in **`PATH`** so **`CMakeCache.txt`** records the correct program.

- **macOS Intel → Apple Silicon:** If **`cmake`** (or **cc65**, **java**, etc.) fails with **`bad CPU type in executable`**, the binary is still **x86_64**. Reinstall for **arm64** so tools match the host CPU.

## 4. Control panel binary (prerequisite)

The Pico firmware links in the **Control Panel** binary. It must be built **before** building the Pico firmware.

- **Location:** Project `cpanel/` (sibling of `pico/`).
- **Requirements:** CC65 toolchain; see `cpanel/README.md` (e.g. `make release`).
- **Output:** `cpanel/cpanel.bin` must exist. The Pico `CMakeLists.txt` lists `cpanel.s` with `OBJECT_DEPENDS` on `../cpanel/cpanel.bin`, so a missing or stale `cpanel.bin` can cause incorrect or failed builds.

## 5. Romdisk image (optional / project-specific)

The firmware can include a ROM disk image via `romdisk.s`, which includes the binary file **`romdisk.po`** from the `pico/` directory. If your tree or build process provides `romdisk.po`, it will be embedded; if not, you may need to generate or obtain it per project instructions (or use an empty placeholder if the feature is unused).

## 6. Build script and version bump

- **Script:** Run **`./cmakeall.sh`** from the **`pico/`** directory.
- **Behaviour:** The script (1) bumps the firmware version and date in `defines.h`, (2) configures four CMake build trees, (3) builds the two release trees, and (4) copies the UF2 files into **`_releases/<version>/`** as `megaflash-pico.uf2` and `megaflash-pico2.uf2`. A **`CHANGELOG.md`** is always included: if **`CHANGELOG-NEXT.md`** exists, it is copied with `@VERSION@` replaced by the build version; otherwise a stub is created.
- **`sed` and macOS:** The script uses `sed -i.bak` for in-place edits. This is compatible with **BSD sed** (macOS). On **GNU sed** (Linux), `sed -i.bak` also works. If you port to a system where in-place `sed` differs, adjust the `sed` invocations in `cmakeall.sh`.

## 7. Summary: minimal steps to reproduce the build

1. Install **Raspberry Pi Pico SDK**: clone the repo and run **`git submodule update --init`** in the SDK directory so all add-ons (tinyusb, cyw43-driver, lwip, mbedtls, btstack) are present. Set **`PICO_SDK_PATH`** to the SDK path.
2. Install **arm-none-eabi** GCC toolchain; optionally set **`ARM_TOOLCHAIN_PATH`** to its `bin` directory.
3. Install **CMake** (3.13+) and **Make**.
4. Build the Control Panel: from repo root, `cd cpanel && make release` (ensure **CC65** is installed); then return to `pico/`.
5. Ensure **`romdisk.po`** is present in `pico/` if your build expects it.
6. From the **`pico/`** directory, run **`./cmakeall.sh`**.
7. Collect UF2 images from **`pico/_releases/<version>/`**.

## 8. Boards and outputs

| Build directory | Board | MCU | UF2 in release folder |
|---|---|---|---|
| `pico_release` | Pico W | RP2040| `megaflash-pico.uf2` |
| `pico2_release` | Pico 2 W | RP2350| `megaflash-pico2.uf2` |

Debug builds (`pico_debug`, `pico2_debug`) are configured but not copied to `_releases/` by the script.

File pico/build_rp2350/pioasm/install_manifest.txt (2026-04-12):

/Users/eositis/Documents/GitHub/MegaFlash/pico/build_rp2350/pioasm-install/pioasm/pioasm
/Users/eositis/Documents/GitHub/MegaFlash/pico/build_rp2350/pioasm-install/pioasm/pioasmTargets.cmake
/Users/eositis/Documents/GitHub/MegaFlash/pico/build_rp2350/pioasm-install/pioasm/pioasmTargets-release.cmake
/Users/eositis/Documents/GitHub/MegaFlash/pico/build_rp2350/pioasm-install/pioasm/pioasmConfig.cmake
/Users/eositis/Documents/GitHub/MegaFlash/pico/build_rp2350/pioasm-install/pioasm/pioasmConfigVersion.cmake

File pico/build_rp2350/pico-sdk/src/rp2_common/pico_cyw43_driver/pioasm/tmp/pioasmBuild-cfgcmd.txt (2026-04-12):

cmd='/opt/homebrew/bin/cmake;--no-warn-unused-cli;-DCMAKE_MAKE_PROGRAM:FILEPATH=/usr/bin/make;-DPIOASM_FLAT_INSTALL=1;-DCMAKE_INSTALL_PREFIX=/Users/eositis/Documents/GitHub/MegaFlash/pico/build_rp2350/pioasm-install;-DCMAKE_RULE_MESSAGES=OFF;-DCMAKE_INSTALL_MESSAGE=NEVER;-GUnix Makefiles;-C<TMP_DIR>/pioasmBuild-cache-$<CONFIG>.cmake;-S;<SOURCE_DIR><SOURCE_SUBDIR>;-B;<BINARY_DIR>'

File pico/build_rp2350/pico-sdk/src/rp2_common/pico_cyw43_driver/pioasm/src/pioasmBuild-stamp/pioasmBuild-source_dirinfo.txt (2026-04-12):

# This is a generated file and its contents are an internal implementation detail.
# The download step will be re-executed if anything in this file changes.
# No other meaning or use of this file is supported.

method=source_dir
command=
source_dir=/Users/eositis/pico-sdk/tools/pioasm
work_dir=

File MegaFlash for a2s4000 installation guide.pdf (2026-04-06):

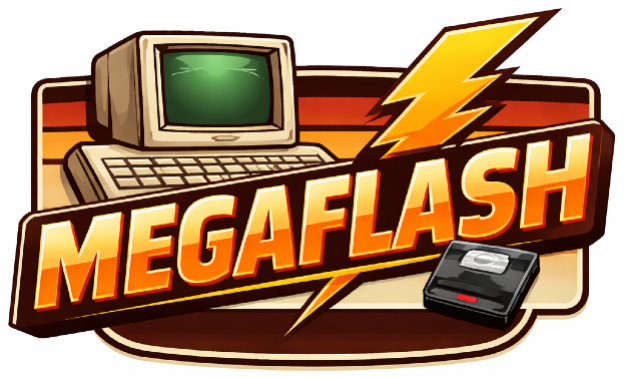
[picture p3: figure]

# MegaFlash for a2s4000 installation guide

Thank you for purchasing the MegaFlash for a2s4000 add-on feature for the original Apple IIc. The following document will assist you installing the device in your machine.

The MegaFlash has been shipped to you preconfigured with the following:
- Storage
- Volume 1 - A2Desktop 1.5
- Volume 2 - Total-Replay 5.3
- Volume 3 - 32MB empty ProDOS volume
- Volume 4 - 32MB empty ProDOS volume
- RAMDISK enabled (400KB)
- AppleSoft FPU enabled
- Latest release of MegaFlash firmware

Included in the package:
- MegaFlash for a2s4000 board
- MegaFlash ROM image for the Apple IIc
- Riser for the CPU socket
- Flat pin riser to avoid damaging existing CPU socket

INSTALLATION INSTRUCTIONS

1. Disconnect your Apple IIc from power
2. Remove the cover from your Apple IIc. If unsure how, please search the web for videos appropriate for your model.
3. Once the top cover has been removed, lift away the keyboard. The pic below shows the board layout under the keyboard, with critical items labelled
4. With a small flat screwdriver, remove the MON ROM from the system, in this picture labeled as ‘ROM 255’. Be careful to insert the screwdriver between the chip and the socket below, into the small gap between the two. Do not insert underneath them all, that may damage your board. Carefully lever the chip out of the socket, if necessary also lifting from the other side.

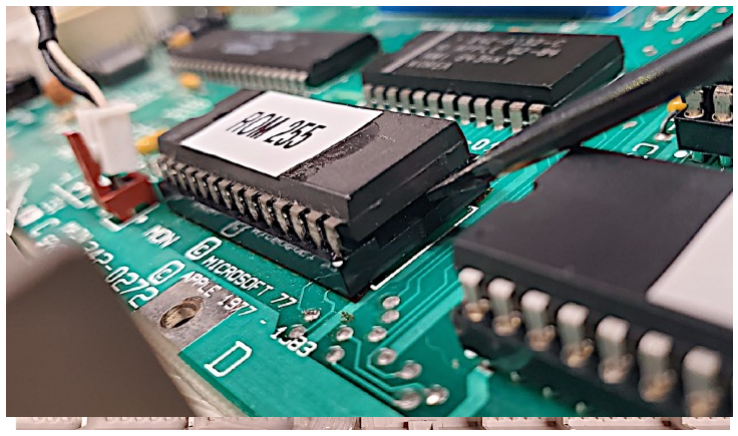
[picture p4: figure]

5. Insert the MegaFlash ROM into the empty MON ROM socket. Take extra care to ensure the chip’s notch is towards the speaker connector. The label should be right side up.

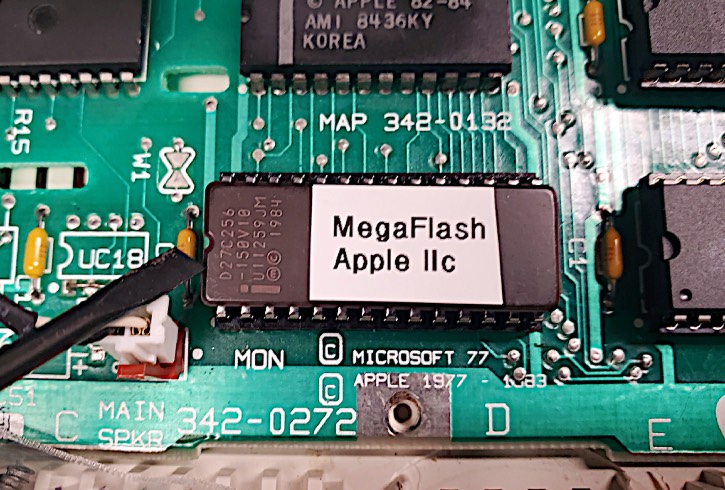
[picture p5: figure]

6. Pin the old ROM to the foam previously attached to the MegaFlash ROM. Place the ROM back in the anti-static bag and save.
7. Remove the 65c02 CPU from the motherboard. Similar to removing the ROM, carefully insert the flat screwdriver between the CPU and socket. Lift only a little, then repeat the same from the other side. Repeat raising from one then the other side until the chip has been removed. Care is needed to ensure the pins do not get bent.

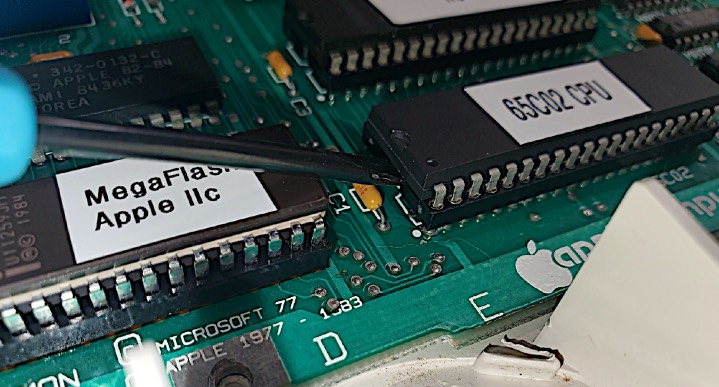
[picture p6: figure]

8. Insert a riser into the CPU socket.
1. If this will not be a permanent install, please use the flat pin socket, as this will help ensure the CPU socket will still correctly mate with the original CPU if the MegaFlash is ever removed.
2. For a more permanent and sturdy connection, use the round pin socket.
3. Insert the selected riser into the CPU socket as shown below

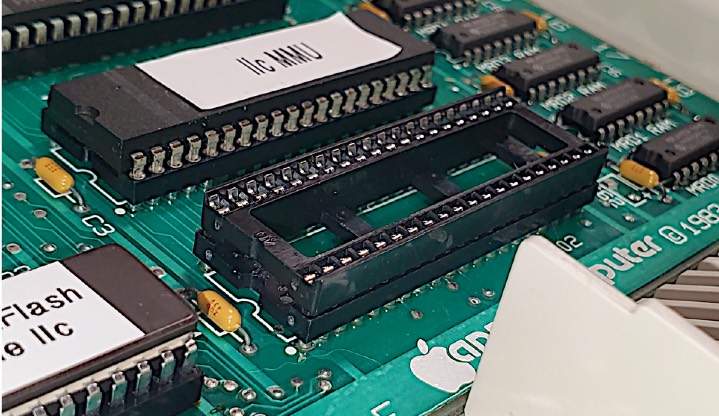
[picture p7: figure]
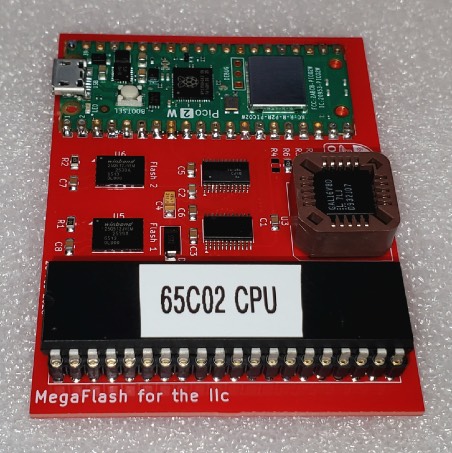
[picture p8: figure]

9. Insert the CPU into the empty socket on the MegaFlash with the protective pink anti-static foam still attached to the MegaFlash pins. Make sure the CPU notch is toward the left of the board, as in the picture below. The notch is also pictured on the board itself, for easier orientation. It may take a bit of jiggling to get the CPU seated in the socket, but be careful not to bend any CPU pins. Double check to ensure all pins are properly inserted into the holes, none of the pins are bent.

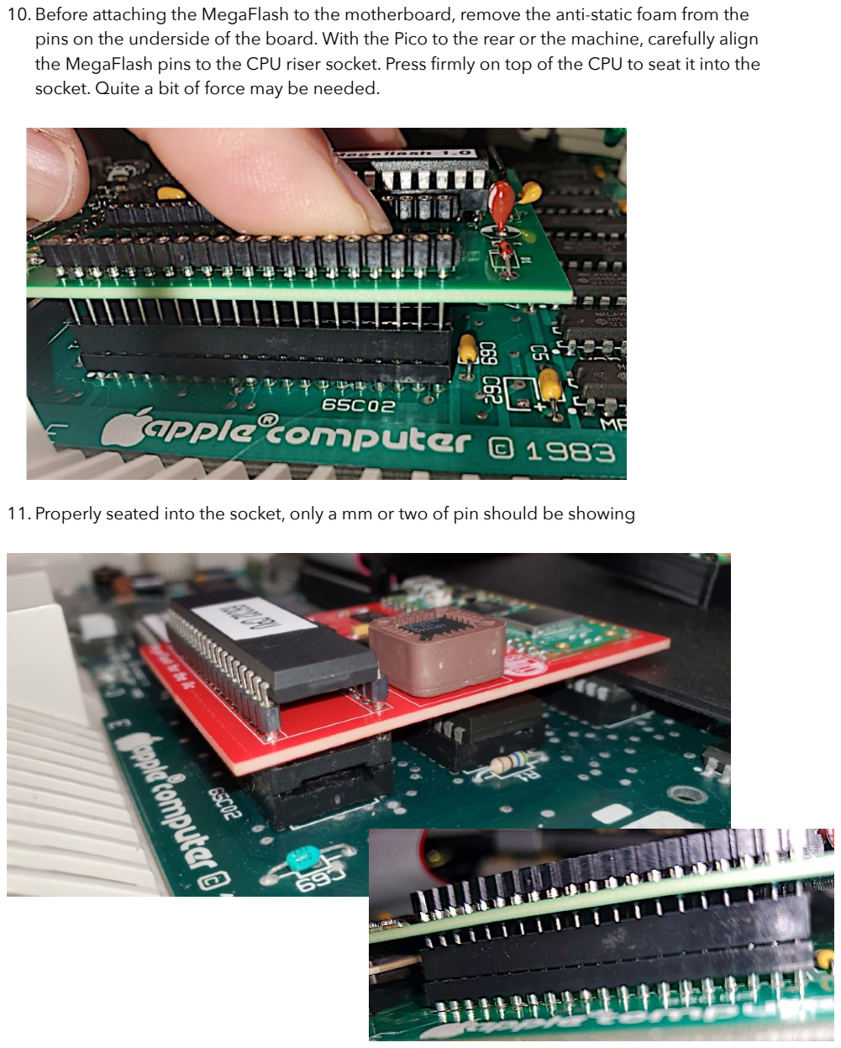
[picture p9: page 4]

10. Before attaching the MegaFlash to the motherboard, remove the anti-static foam from the pins on the underside of the board. With the Pico to the rear or the machine, carefully align the MegaFlash pins to the CPU riser socket. Press firmly on top of the CPU to seat it into the socket. Quite a bit of force may be needed.
11. Properly seated into the socket, only a mm or two of pin should be showing

12. Congratulations! The board has been installed! You may now close your Apple IIc

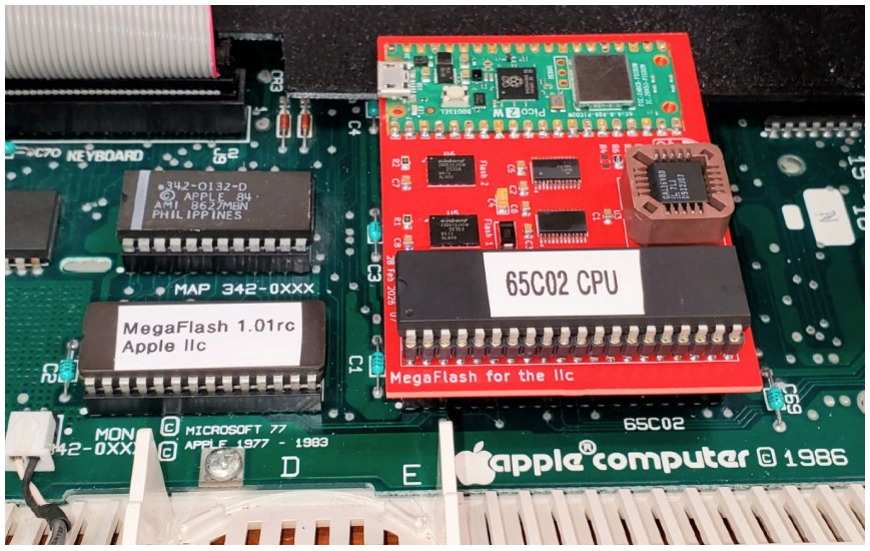
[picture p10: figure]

## QUICK-START USER GUIDE FOR THE MEGAFLASH

With the MegaFlash installed, your Apple IIc will immediately boot into A2Desktop, a GUI file management environment for the Apple II line of computers. On the desktop you will see the A2Desktop 32MB volume, Total Replay, two empty volumes (Vol3 and Vol4), and a RAM disk. If you have a floppy in your drive or external drives attached, these will also show.

CONTROL PANEL QUICK START
To access the control panel, press and hold the Closed Apple key to the right of the keyboard space bar. Simultaneously press Ctrl-Reset and release. Keep holding down the Open Apple key until the boot selector panel appears on the monitor. Press 7 to enter the control panel. By default all features will be enabled, except WiFi and clock.
1. With the down arrow, Scroll down to TimeZone and set for your location using the left/ right arrows
2. Click twice more with the down arrow to select ‘WiFi settings’. Press the Enter key
3. Enter your wifi network name and press enter
4. Enter your wifi password and press enter
5. Back in the control panel, click the down arrow one more time to select ‘Test wifi/NTP’. Press Enter
6. If you correctly entered your WiFi credentials the test will show the IP assigned to the MegaFlash and confirm Network Time functionality. If the connection fails, return to the WiFi setup and re-enter your wifi name and credentials.
7. Once the WiFi connection is complete, scroll down to ‘Save and Reboot’. This will reboot the machine and boot into A2Desktop. The top right corner of the screen will show the current time.
8. Basic setup is complete.

BOOTING FROM DRIVE 2
IN#4 command to boot from drive 2 of MegaFlash

### CONTROL PANEL DETAIL

DRIVES ENABLE
1. The flash drives and the RAM Disk can be individually enable/disabled. Select Drives Enable from the main menu to open the window. Press the number keys to enable/disable the drives.
2. To save the changes, press Enter to return to main menu. Then, select Save and Reboot. To discard any changes, press Esc key.
3. Warning: The slot/drive mappings will be changed after drives are enabled/disabled.
4. Always identify the drives with ProDOS volume name instead of slot/drive number.

FORMAT
The MegaFlash drives and RAMdrive can be formatted from MegaFlash control panel. Two key features.
1. It can format drives to any arbitrary size.
2. It can erase the entire drive before formatting. It may take up to 2 minutes to erase a flash drive. Subsequent write access will be much faster if the drive is already erased.

MEGAFLASH HARDWARE/FIRMWARE INFORMATION
To show the hardware and firmware information, go to the boot menu. Hold the Open-Apple key while entering Control Panel. i.e. OA-7 or OA-C.
- Hold Open-Apple key until the device information screen appears.

ROM DISK
A ROM Disk is provided for disaster recovery. The ROM disk contains Copy II+ and ADT Pro. When enabled from boot menu, it will become the first unit of MegaFlash (slot 4, drive 1). Please note that the slot/drive assignments of all MegaFlash units are changed.
Ctrl-OA-Reset cold boot to disable the ROM Disk

RAM DISK
The RAM Disk can be enabled from Control Panel. The size of RAM Disk is 400kB. The RAM Disk is the last unit of SmartPort. Its volume name is /RAMDISK.
RAM Disk can be used to transfer floppy disk image with ADT Pro. Users may transfer a floppy disk image and write it to the RAM Disk. Then, copy files from the disk image to Flash storage.

APPLESOFT BASIC FPU
High bit of address $5FC is the Enable flag of Applesoft FPU.

REAL TIME CLOCK AND NETWORK TIME SYNC
The Raspberry Pi Pico has a real time clock (RTC). But it does not support battery backup. MegaFlash gets the time from NTP server via WIFI.

To enable network time sync:
1. Configure the WIFI Settings from Control Panel
2. Run Test Wifi/NTP from Control Panel
3. If all tests are passed, enable the Network Time Sync option and setup the time zone.

If MegaFlash can fetch the time from NTP server, the time is shown at the bottom right corner in Boot Menu and Control Panel.
If Network Time Sync option is enabled, a ProDOS clock driver will be installed automatically. The clock driver is in the patched system ROM. No software installation is required.

SLINKY EMULATION
With the stock Apple IIc firmware, MegaFlash can emulate a 256kB Memory Expansion card (aka Slinky) if Pico 2 controller board is used.

### DISK IMAGE TRANSFER

Disk Image File (.po or .hdv) can be transferred to MegaFlash in 3 ways.
1. ADT Pro and Serial Port
2. MegaFlash Terminal Mode
3. Via WIFI and TFTP Server

TERMINAL MODE
To enter terminal mode, TURN OFF Apple IIc. Then, connect a PC to the Pi Pico USB port. Then connect to Pico with a Terminal Program like TeraTerm (Windows).
In the terminal mode, ProDOS-ordered disk image (.po or .hdv) can be uploaded to or downloaded from MegaFlash using XMODE-CRC or XMODEM/1K protocol.

DISK IMAGE TRANSFER VIA WIFI
Disk Image can be transferred between MegaFlash and TFTP server via WIFI. Note that TFTP is not FTP. TFTP protocol is much simpler and without user authentication. To transfer a disk image:
1. setup the WIFI network from Control Panel.
2. Select Disk Image Transfer via WIFI from Control Panel and follow the instruction.

Please note that the TFTP server and MegaFlash must be on the same subnet and TFTP traffic cannot pass through firewall or NAT. In other words, MegaFlash and the server must be connected to the same WIFI router.
The block size of original TFTP protocol is 512 bytes. Later TFTP option extension allows larger block size. A larger block size increase transfer speed dramatically.
- Make sure blocksize option negotiation is enabled when configuring the TFTP server.
On Windows, Tfpd64 (https://pjo2.github.io/tftpd64/) server program is recommended. It has a GUI. You may need to run the app as administrator to save the setting. When sending a file to server, the file is overwritten without any warning if the file already exists on the server. Make sure Option negotiation is enabled.
On MacOS, consider using Pumpkin https://github.com/mterron/pumpkin

### APPLE II DESKTOP

By default, Apple II Desktop copies itself to RAM Disk during start-up. This is not necessary for MegaFlash. This behavior can be disabled from Apple II Desktop Control Panel. Select Control Panel from Apple Menu. Open Options, then disable Copy to RAMCard.

### UPDATING PI PICO BOARD FIRMWARE

MegaFlash by Ositis uses the Raspberry Pi Pico 2W exclusively. Your board was delivered with the 1.1.7 firmware developed by Thomas Fok. Updates firmware from Thomas Fok is available here: https://github.com/ThomasFok/MegaFlash/releases

Alternate firmware is under development by Ositis. This MegaFlash fork is working on improving the networking stack. It is not as mature as Thomas’ version. Use with caution. The current release has a completely rewritten network stack, significantly improving TFTP file transfers. UtherNet II emulation is in development. The current release is available here: https://github.com/eositis/MegaFlash/releases

To upgrade the firmware:
1. Remove MegaFlash from your Apple IIc computer.
2. Press and hold the white button labeled BOOTSEL on the Pico board
3. Connect the Pico board to a USB port of a computer while holding the button. Wait a few seconds, then release the white button
4. A disk drive called RP2350 or RPI-RP2 should be mounted on your computer desktop.
5. Drag-and-drop the megaflash-pico2.uf2 firmware file downloaded from GitHub to the RP2350 drive. Wait until the file copy finishes.
6. Reinstall MegaFlash back to your Apple IIc computer carefully.

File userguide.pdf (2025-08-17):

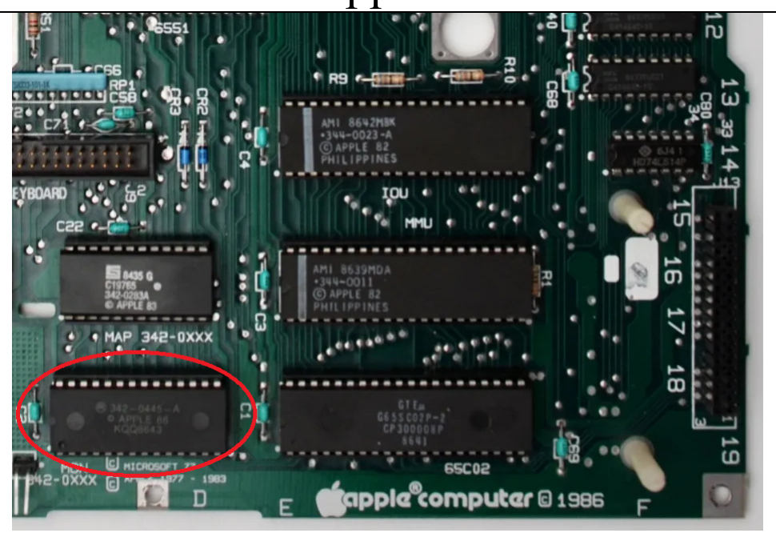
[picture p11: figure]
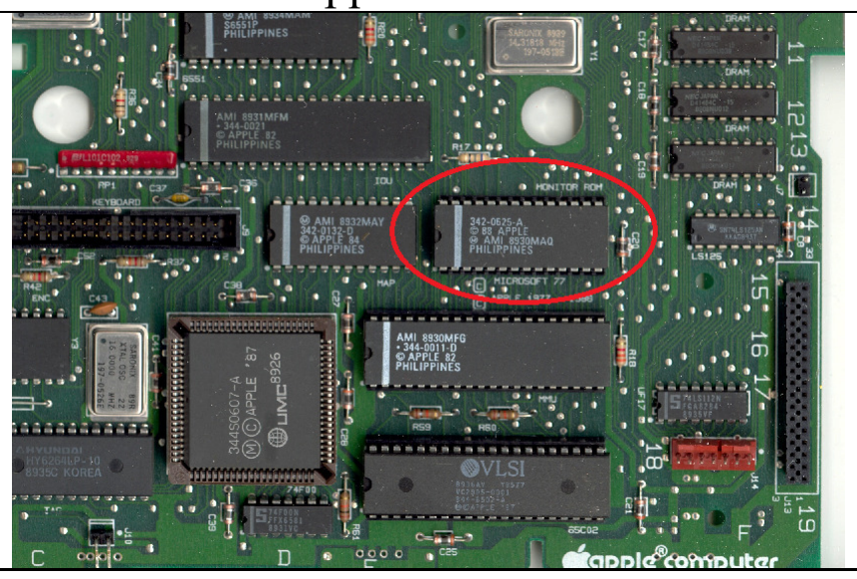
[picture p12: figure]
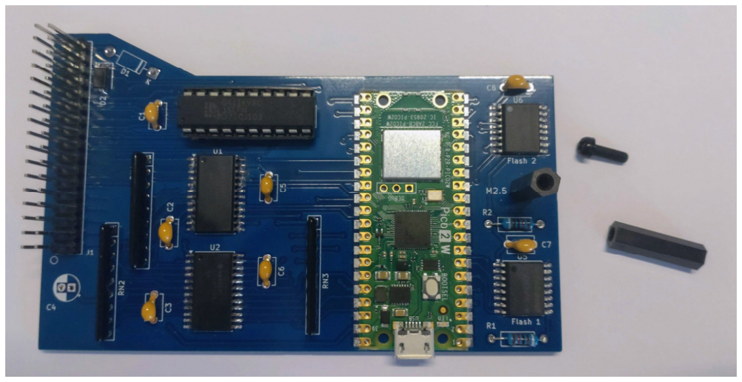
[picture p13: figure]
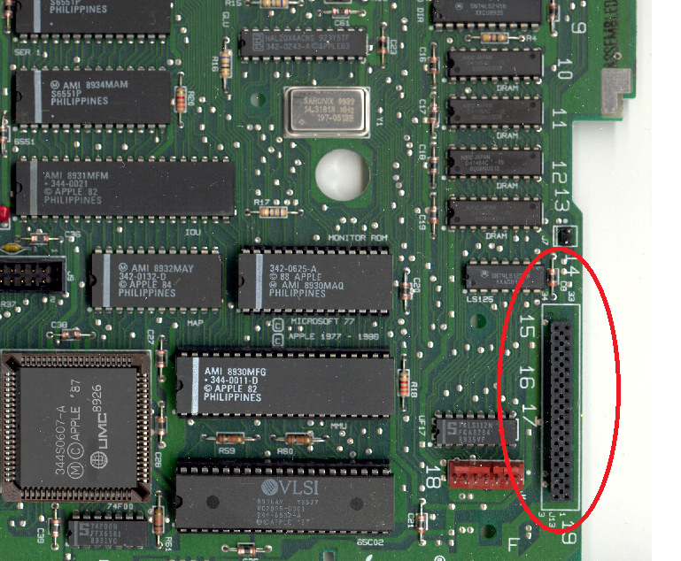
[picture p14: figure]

17-Aug-2025 | 1

## MegaFlash User Guide

## Installation

1. Replace the Monitor ROM with the supplied ROM chip.
Apple IIc | Apple IIc Plus

### 2. For Rev 1.1 PCB, it is recommended that an 18mm nylon standoff is installed to

support the card as shown below.

### 3. Install MegaFlash to the Memory Expansion Connector of Apple IIc/IIc plus

motherboard. Make sure the header pins are aligned to the connector correctly.

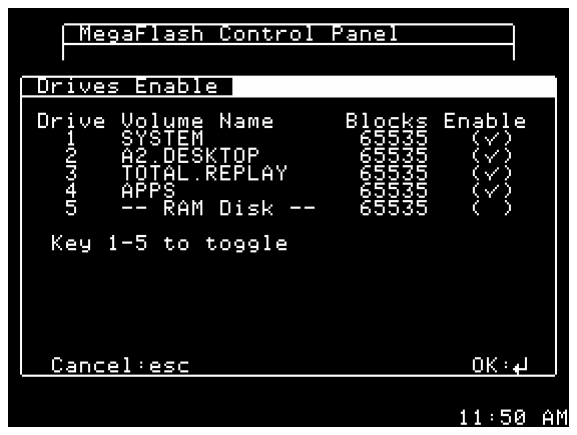
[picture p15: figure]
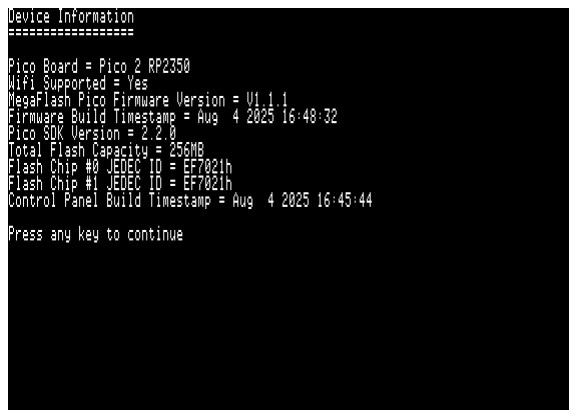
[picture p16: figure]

17-Aug-2025 | 2

## Boot Menu and Control Panel

- Ctrl-Option-Reset to enter the boot menu.
- In the boot menu, there are some shortcut keys: C key to enter control panel
Space bar to toggle CPU speed on IIc+
Esc key to reboot

## Booting from drive 2

IN#4 command to boot from drive 2 of MegaFlash

## Control Panel

Drives Enable

Each flash drive and the RAM Disk can be individually enable/disabled. Select Drives Enable from the main menu to open the window. Press the number keys to enable/disable the drives.

To save the changes, press Enter to return to main menu. Then, select Save and Reboot.

To discard any changes, press Esc key.

Warning: The slot/drive mappings will be changed after drives are enabled/disabled. Always identify the drives with ProDOS volume name instead of slot/drive number.

Format

It can format the flash drives and RAM drive on MegaFlash. It has two special features. 1) It can format drives to any arbitrary size. 2) It can erase the entire drive before formatting. It may take up to 2 minutes to erase a flash drive. Subsequent write access will be much faster if the drive is already erased.

## MegaFlash Hardware/Firmware Information

To show the hardware and firmware information,
go to the boot menu. Hold the Open-Apple key
while entering Control Panel. i.e. OA-7 or OA-C. Hold Open-Apple key until the device information screen appears.

17-Aug-2025 | 3

## Apple IIc+ Accelerator

The accelerator code has been modified:
- Pressing Esc key on Power up to switch to normal mode is removed.
- To change CPU speed, first go to Boot Menu. Press key 8 or Space bar to toggle the CPU speed. Then, reboot
- Ctrl-OA-Reset does not change the current CPU speed.
- The word Normal is shown when CPU is running at 1MHz during cold boot.
- The speed when the computer is powered up can be set in Control Panel

## ROM Disk

- A ROM Disk is provided for disaster recovery. The ROM disk contains Copy II+ and ADT Pro.
- When enabled from boot menu, it will become the first unit of MegaFlash (slot 4, drive 1). Please note that the slot/drive assignments of all MegaFlash units are changed.
- Ctrl-OA-Reset cold boot to disable the ROM Disk

## RAM Disk

- RAM Disk can be enabled from Control Panel. The size of RAM Disk is 400kB. RAM Disk is the last unit of SmartPort. Its volume name is /RAMDISK.
- RAM Disk can be used to transfer floppy disk image with ADT Pro. Users may transfer a floppy disk image and write it to the RAM Disk. Then, copy files from the disk image to Flash storage.

## Applesoft BASIC FPU

- High bit of address $5FC is the Enable flag of Applesoft FPU.

## Real Time Clock and Network Time Sync

The Raspberry Pi Pico has a real time clock (RTC). But it does not support battery backup. MegaFlash gets the time from NTP server via WIFI.

To enable network time sync,

1) Configure the WIFI Settings from Control Panel
2) Run Test Wifi/NTP from Control Panel
3) If all tests are passed, enable the Network Time Sync option and setup the time zone.

If MegaFlash can fetch the time from NTP server, the time is shown at the bottom right corner in Boot Menu and Control Panel.

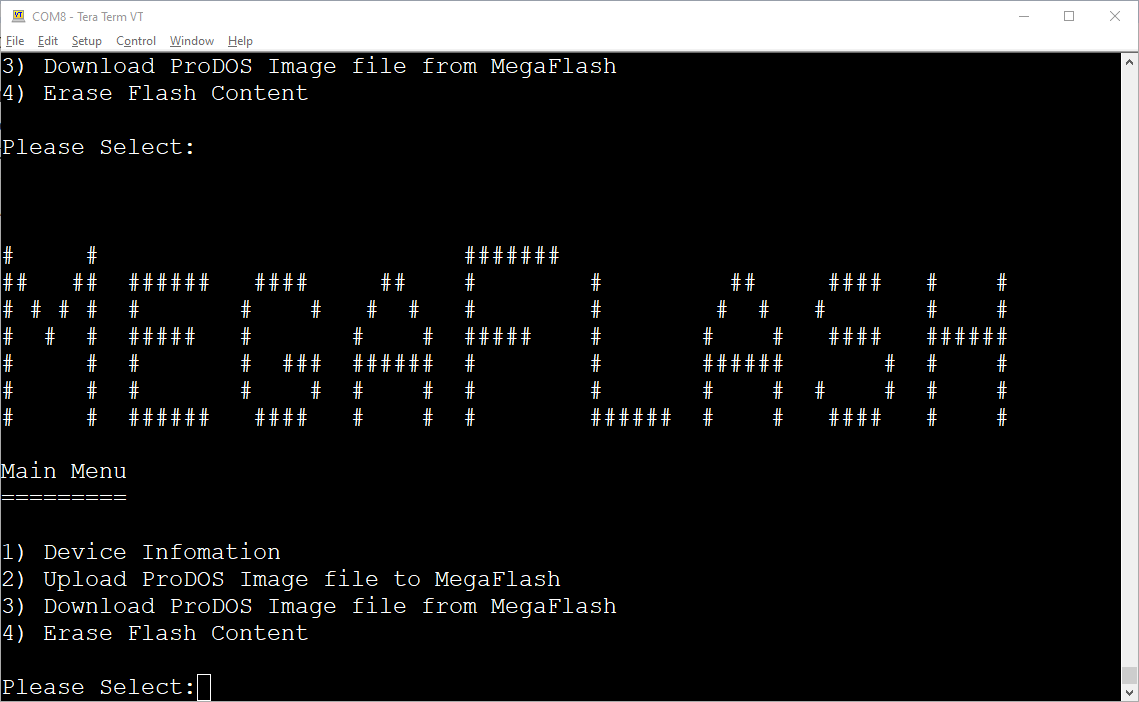
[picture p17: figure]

17-Aug-2025 | 4

If Network Time Sync option is enabled, a ProDOS clock driver will be installed automatically. The clock driver is in the patched system ROM. No software installation is required.

## Slinky Emulation

With the stock Apple IIc firmware, MegaFlash can emulate a 256kB Memory Expansion card (aka Slinky) if Pico 2 controller board is used.

## Disk Image Transfer

Disk Image File (.po or .hdv) can be transferred to MegaFlash in 3 ways.

1) ADT Pro and Serial Port
2) MegaFlash Terminal Mode
3) Via WIFI and TFTP Server

## Terminal Mode

- To enter terminal mode, TURN OFF Apple IIc. Then, connect a PC to USB port of Pi Pico. Connect to MegaFlash serial port with a Terminal Program like TeraTerm (Windows).
- In the terminal mode, ProDOS-ordered disk image (.po or .hdv) can be uploaded to or downloaded from MegaFlash using XMODE-CRC or XMODEM/1K protocol.

## Disk Image Transfer via WIFI

Disk Image can be transferred between MegaFlash and TFTP server via WIFI. Note that TFTP is not FTP. TFTP protocol is much simpler and without user authentication.

To transfer disk image, setup the WIFI network from Control Panel. Then, select Disk Image Transfer via WIFI from Control Panel and follow the instruction.

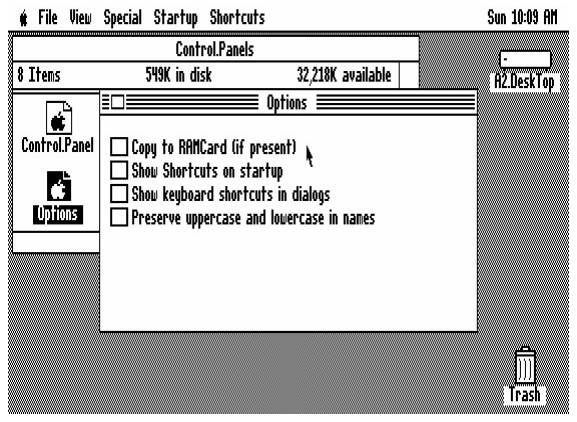
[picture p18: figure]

17-Aug-2025 | 5

Please note that the TFTP server and MegaFlash must be on the same subnet and TFTP traffic cannot pass through firewall or NAT. In other words, MegaFlash and the server must be connected to the same WIFI router.

The block size of original TFTP protocol is 512 bytes. Later TFTP option extension allows larger block size. A larger block size increase transfer speed dramatically. Make sure blocksize option negotiation is enabled when configuring the TFTP server.

On Windows, Tfpd64 (https://pjo2.github.io/tftpd64/) server program is
recommended. It has a GUI. You may need to run the app as administrator to save the setting. When sending a file to server, the file is overwritten without any warning if the file already exists on the server. Make sure Option negotiation is enabled.

I don’t have a Mac. So, I cannot test any Mac TFTP servers. But this software looks promising.

Pumpkin
https://github.com/mterron/pumpkin

## Apple II Desktop

By default, Apple II Desktop copies itself to RAM Disk during start-up. This is not necessary for MegaFlash. This behaviour can be disabled from Apple II Desktop Control Panel. Select Control Panel from Apple Menu. Open Options, then disable Copy to RAMCard.

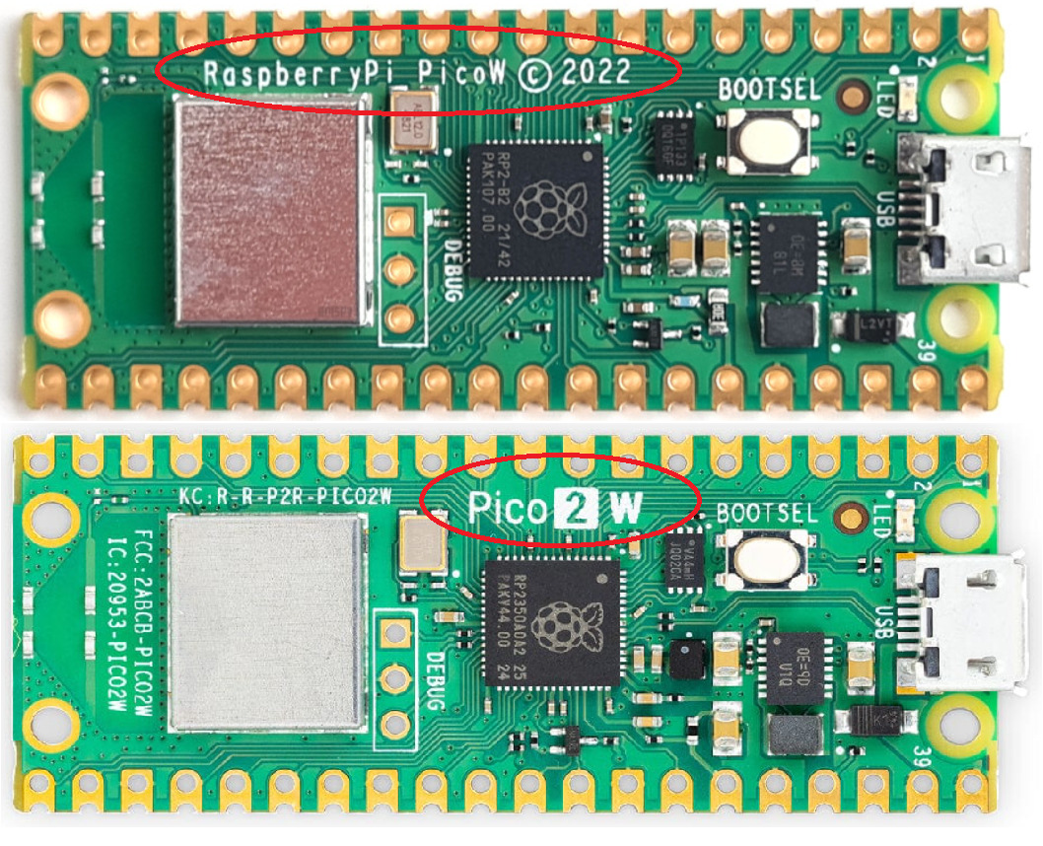
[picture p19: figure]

17-Aug-2025 | 6

## Updating Pi Pico Board Firmware

The first step is to identity the model of Pico Board on your MegaFlash. Currently, Pico W and Pico 2W boards are supported. The firmware of the two boards is different. Please prepare the correct firmware file (.uf2) for your Pico board.

To upgrade the firmware,
1) Remove MegaFlash from your Apple IIc computer.
2) Press and hold the white button labeled BOOTSEL
on the Pico board
3) Connect the Pico board to a USB port of a computer while holding the button. Wait a few seconds, then release the white button
4) A disk drive called RP2350 or RPI-RP2 should be mounted.
5) Drag-and-drop the firmware file to the drive. i.e. Copy the .uf2 file to the root directory of the drive. Wait until the file copy finishes.
6) Reinstall MegaFlash back to your Apple IIc computer carefully.

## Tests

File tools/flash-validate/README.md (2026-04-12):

# Flash validation (Apple II / Applesoft)

`FLASHVAL.BAS` exercises the **same MegaFlash register path** the Control Panel uses (`$C0C0`–`$C0C3`): command, parameter stream, and data buffer. It is intended to:

1. **Characterize** a known-good board + firmware + flash (and optionally a specific ProDOS volume layout).
2. **Save a baseline** text file of checksums and small metadata.
3. **Compare** a later run (new flash chip, new firmware, new build) against that baseline.

## Requirements

- **Applesoft** (IIe, IIc, IIgs in IIe mode, etc.).
- MegaFlash in a standard slot; **default slot 4** → base address **`$C0C0`**.
- **ProDOS BASIC** recommended for **baseline** and **compare** modes (sequential text file I/O). Mode **1** (screen only) works without ProDOS.

## Register layout (same as `common/defines.inc`)

| Offset from slot base | Address (slot 4) | Role |
|---|---|---|
| +0 | `$C0C0` | Write = command; read = status (bit 7 = busy, bit 6 = error, bits 0–4 = MegaFlash error code) |
| +1 | `$C0C1` | Parameter byte stream (auto-advancing pointer) |
| +2 | `$C0C2` | Data byte stream (512-byte buffer, auto-advancing) |

Slot base in decimal: **`49280 + 16 * SLOT`** (e.g. slot 4 → **49344**).

## What the script does (non-destructive)

Default suite **does not format, erase, or write blocks**. It:

1. **`CMD_MODELINEAR` (`$03`)** — linear data buffer mode.
2. **`CMD_GETDEVINFO` (`$10`)** — checksums parameter bytes **0–11** only (excludes firmware build timestamp at **12–15**).
3. Optional line **`FWVER`** — checksum of bytes **3–4** only (firmware version word); *expect this to change when you intentionally upgrade UF2*.
4. **`CMD_GETDEVSTATUS` (`$11`)** — unit count byte.
5. **`CMD_GETUNITSTATUS` (`$12`)** — unit **1**, three block-count bytes.
6. **`CMD_GETDIB` (`$13`)** — unit **1**, **25** DIB bytes.
7. **`CMD_GETVOLINFO` (`$14`)** — unit **1**; checksum **32** parameter bytes (volume name affects the value).
8. **`CMD_READBLOCK` (`$15`)** — unit **1**, blocks **0** and **1**: status nibble, `parameterBuffer[0]` (SmartPort-style result), **16-bit checksum** of 512 data bytes.

Destructive tests (**`CMD_FORMATDISK` / `CMD_ERASEDISK` / `CMD_WRITEBLOCK`**) are **not** run here; add a separate harness if you need them, with write-enable key **`$71`** per `common/defines.h`.

## Baseline file format (`FLASHVAL1`)

Sequential text file:

1. Header: **`FLASHVAL1`**
2. Slot: decimal **1–7**
3. One line per metric: **`KEY VALUE`** (value = decimal integer; checksums are **16-bit**, 0–65535)

Keys emitted:

| Key | Meaning |
|-----|---|
| `DEVINFO12` | Sum mod 65536 of device info bytes 0–11 |
| `FWVER` | Sum mod 65536 of bytes 3–4 (version only) |
| `DEVSTATUS` | First parameter byte after `CMD_GETDEVSTATUS` |
| `U1BC` | Sum mod 65536 of 3 unit-status bytes |
| `DIB25` | Sum mod 65536 of 25 DIB bytes |
| `VOL32` | Sum mod 65536 of 32 volume-info parameter bytes |
| `RB1_0_ST` | Status byte (`PEEK` command/status register) after `CMD_READBLOCK` |
| `RB1_0_PE` | First parameter byte after read (SmartPort-style result; 0 = success) |
| `RB1_0_DC` | Sum mod 65536 of 512 data bytes |
| `RB1_1_*` | Same for unit 1, block 1 |

**Note:** `VOL32` and block data checksums depend on **disk content** and **enabled units**. Capture baseline on a **stable** image (or document that those lines are “environment-specific”).

## Interpreting mismatches

- **`DEVINFO12` / `U1BC` / `DIB25`**: strong indicators of **flash size / geometry / ID** path (e.g. different chip or `InitFlash` behaviour).
- **`FWVER`**: changes on every firmware version bump — ignore or refresh baseline when updating UF2.
- **`RB1_0` / `RB1_1`**: if device info matches but these differ, suspect **media/image** differences, not necessarily SPI flash silicon.

## Source of truth for command values

`common/defines.h` / `common/defines.inc` (`CMD_*`), and `pico/cmdhandler.c` (`DoGetDeviceInfo`, `DoReadBlock`, …).

## Overnight soak tool (`FLASHSOAK`)

`FLASHSOAK.BAS` is a destructive, long-running validator intended to run overnight and emit parseable CSV rows. On screen, **line 21** shows the current phase (cycle, unit, format, file I/O, checksum block progress every 256 blocks, TFTP wait ticks every 50 polls, pass/fail), so you can follow progress without a serial console.

Per cycle, for each writable MegaFlash volume (including RAM disk when enabled), it:

- Formats the unit.
- Creates/appends/deletes files, plus a fill-to-error pass.
- Computes a whole-volume checksum (sum of all bytes from `CMD_READBLOCK`).
- Uploads image to TFTP server `192.168.0.10` as `validationX.po` (X = unit number).
- Reformats unit, downloads `validationX.po` back into place.
- Recomputes checksum and verifies it matches pre-upload value.
- Logs each step to a **ProDOS text** (SEQ) file — default **`SOAK.TXT`** — with **comma-separated** lines (`ts,cycle,unit,event,result,v1,v2`). Use a **`.TXT`** name so ProDOS/BASIC treat it as a normal ASCII text file; the content is still CSV-style for import into spreadsheets. **`ts`** is **8 characters** from ProDOS **`TIME$`** (host clock). The log file is created or opened at the **start of cycle 1** (after the **PROGRESS** banner), not during the initial prompts — so you can tell whether a hang is in **ProDOS `OPEN`** (line 21 shows **`OPENING …`**) or in the soak steps. Type **`NONE`** (uppercase or lowercase) at the log prompt to **disable the log file** entirely (destructive test still runs). **Note:** Applesoft only distinguishes the **first two characters** of variable names, so **`LGSKIP`** and **`LGINIT`** would alias each other; the program uses **`Q1`**/**`Q2`** for skip and log-init flags. **`OPEN`** / **`WRITE`** use the same string pattern as **`FLASHVAL.BAS`** (no extra space before the filename). If the **default volume** is wrong, use a full path (e.g. **`/FLASHVALID/SOAK.TXT`** or **`/RAM/SOAK.TXT`**). If **`OPEN`** appears to **hang** (status line stuck on **`OPENING …`**), the MLI is usually waiting on the wrong volume or a slow path — try **`/RAM/SOAK.TXT`**, set **`PREFIX`** to the volume you are writing to, or use **`NONE`** to run without a log. The log file is **never deleted**: each program run appends a **`RUN_START`** row first, then all events for that session. If the file does not exist yet, the first **`OPEN`** creates it and writes the header row.

If all units pass, it reformats all writable units again and starts the next cycle.

**Files:**

- `FLASHSOAK.BAS` - source for the overnight test.
- On disk image, `FLASHSOAK` (tokenized) and `FLASHSOAK.SRC` (text) are both included.

## Bootable disk (`FLASHVALID.po`)

Requires **Java** and [AppleCommander](https://applecommander.github.io/) (CLI jar). The build follows the same pattern as **`../a2speed/Makefile`** `disk` target: create a **ProDOS 140K** image with **`-pro140`**, then add files with **`-p`**, **`-bas`**, **`-ptx`**.

- Default jar: **`$HOME/Library/Application Support/AppleCommander/AppleCommander-ac.jar`** (same default name as a2speed). Override with **`AC_JAR`**.
- On Apple Silicon, the script prefers **`/opt/homebrew/opt/openjdk/bin/java`** when present (avoids Intel **`java`** “Bad CPU type” issues), same as a2speed.

From the repo root:

```bash
./tools/flash-validate/build-flashval-disk.sh
```

Or:

```bash
cd tools/flash-validate && make disk
```

Writes **`tools/flash-validate/FLASHVALID.po`** (**143360 bytes**, same **`.po`** convention as **`../a2speed`**’s **`a2speed.po`**; ProDOS raw block order). **`OUT=`** overrides the output path. **`SYS_SRC=`** overrides the source image for **PRODOS** / **BASIC.SYSTEM** (default **`cpanel/prodos19.dsk`**).

Contents:

- **PRODOS** / **BASIC.SYSTEM** — copied raw from **`cpanel/prodos19.dsk`** (valid 140K ProDOS 1.9 image shipped with the Control Panel build inputs).
- **TFTPUTIL** — tokenized Applesoft from **`TFTPUTIL.BAS`**: standalone TFTP **upload** / **download** of a disk image to/from a MegaFlash unit (same **`CMD_TFTPRUN`** / **`CMD_TFTPSTATUS`** path as the Control Panel’s TFTP feature; **Pico W** + WiFi required). **`TFTPUTIL.SRC`** is the text source.
- **TFTPUTIL.DOC** — on-disk text documentation from **`TFTPUTIL.TXT`** (startup behavior, host config, prompts, and error notes).
- **FLASHVAL** — tokenized Applesoft from **`FLASHVAL.DSK.BAS`** (screen-only test suite; run under BASIC.SYSTEM).
- **FLASHSOAK** — tokenized Applesoft overnight stress validator.
- **FLASHVAL.SRC** — text copy of **`FLASHVAL.BAS`** (full program including ProDOS baseline/compare); use for reference or manual entry; AppleCommander **`-bas`** on the full file is still unreliable.
- **FLASHSOAK.SRC** — text copy of `FLASHSOAK.BAS`.
- **WGET65V** (optional) — when **`tools/wget65-verbose/wget65v.bin`** is built and **`build-flashval-disk.sh`** can find `cl65` and **`apple2enh/util/loader.system`**, the image also includes the **`WGET65V`** binary, **`WGET65V.SYSTEM`** loader, **`WGET65V`** Applesoft launcher, **`WGET65V.SRC`**, and **`WGET65V.DOC`**. If the binary is missing, **`WGET65V.DOC`** alone is added with build instructions. See **`tools/wget65-verbose/README.md`**.

**Note:** **`PR`** is not a safe variable name in Applesoft (it abbreviates **PRINT**). This tree uses **`PX`** and **`D1`** for the parameter and data ports at **`CR+1`** and **`CR+2`**.

## WGET65V (verbose wget / ip65 fork)

**`tools/wget65-verbose/`** is a fork of upstream **`wget65`** with **screen** logging for each Uthernet II / W5100 handshake step and **register dumps** (MR, RTR XOR, RMSR, PTIMER). Build **`wget65v.bin`** with cc65 and a stock **`ip65`** checkout, then rebuild **`FLASHVALID.po`** so the disk includes the binary and launcher. Details: **`tools/wget65-verbose/README.md`**.

## TFTP utility (`TFTPUTIL`)

Run **`TFTPUTIL`** from BASIC.SYSTEM. It starts in **80-column mode**, auto-detects MegaFlash slot (prefers slot 4, otherwise scans 1-7), then prompts for **TFTP host FQDN or IP** (default loaded/saved via `TFTPUTIL.CFG`). Before unit selection, it lists available volumes as **unit number + volume name** and prompts for a valid unit in range. Then choose **upload vs download** and enter **remote filename** (e.g. **`image.po`**). **Upload** sends the contents of the selected volume to the server; **download** writes the server file into that volume. Behaviour matches the firmware’s TFTP transfer (same as **`FLASHSOAK`**’s TFTP steps). Large transfers can take several minutes; status ticks appear on **line 21**.

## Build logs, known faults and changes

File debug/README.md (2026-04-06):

# Debug captures (MegaFlash + ip65)

## Timestamped UART logs

Save Pico **Debug** firmware serial captures here (e.g. from CoolTerm / serial monitor). Use a filename that includes **date and time** so traces stay ordered, e.g. `2026-03-21 21-42-20 FT232R USB UART #1.log`.

- **`[u2]`** — gated W5100 diagnostics (`UTHERNET2_DEBUG`). Default **low noise**: **`[u2] ck=n`** only when **`U2_IP65_CHECKPOINT=n`** (CMake cache). **Bisect** ip65 init by reconfiguring:  
  `cmake -B pico/pico2_debug -DPICO_BOARD=pico2_w -DCMAKE_BUILD_TYPE=Debug -DU2_IP65_CHECKPOINT=3`  
  Checkpoints: **1** = MR `0x03`, **2** = RTR `$0017`, **3** = RTR `$0018`, **4** = RMSR `$001A`, **5** = MACRAW OPEN ok. Optional: **`-DU2_IP65_TRACE_DATA=1`** (48 DATA reads), **`-DU2_MON_LOG_BUS=1`** (verbose `[u2m]` per cycle — floods UART).  
  **Flush:** `U2_MonPollFlush` runs on **core 0** (next to `NetworkPump_PollOnce`), not on the Apple bus core — avoids **cyw43 `async_context` PANIC** with **`[u2] ck=5`** (see §1g in Implementation notes).
- **`[u2m]`** — activity monitor (socket + net); per–bus-cycle lines only if **`U2_MON_LOG_BUS=1`**.

These lines come from the **Pico only**. They show that the Apple accessed the emulated Uthernet II ports, not text printed by **telnet65** or other **Apple II** programs (those go to the II’s screen or their own I/O).

## ip65 for MegaFlash (slot 4)

This folder includes a **fresh build** of the Apple II disk and zip:

| File | Purpose |
|---|---|
| **`ip65.dsk`** | ProDOS disk with **TELNET65**, DATE65, HFS65, etc. |
| **`ip65-apple2.zip`** | Headers + libraries + same `.dsk` for developers |

**Ethernet default slot is 4** (matches MegaFlash Uthernet II at `$C0C4–$C0C7` when the card is in slot 4). Sources: `ip65/drivers/a2init.s` (`eth_init_default = 4`), `ip65/inc/ip65.h` (`ETH_INIT_DEFAULT` for `__APPLE2__`).

Rebuild from the **ip65** repo (sibling of MegaFlash):

```bash
cd /path/to/ip65
rm -f ip65.dsk ip65-apple2.zip ip65.h *.lib
make apple2
cp ip65.dsk ip65-apple2.zip /path/to/MegaFlash/debug/
```

If **telnet65** reports “Device not found” but the **tail** shows **correct RTR** (`$0017`/`$0018`), see `docs/Implementation-notes-and-reasoning.md` §1c (stock ip65 cannot return device failure from `ip65_init` after a passing RTR XOR). Otherwise see §1c–§1d (probe, RP2350 PIO IRQ wait). A single `[u2] mode=0x03` line then silence often means the Apple stopped before DATA reads.

## Manual W5100 checks after RTR (Apple monitor, slot 4)

All addresses are **`$C0C4`–`$C0C7`**: **MR**, **AddrHi**, **AddrLo**, **Data**. Start each group with **`C0C4:03`** (indirect + auto-increment). Set the pointer with **`C0C5`/`C0C6`**, then read **`C0C7`** (repeat for consecutive bytes with AI).

| Step | Pointer (hex) | What to read / expect (MegaFlash defaults) |
|---|---|---|
| 1 | `$001A` | **RMSR** → **`06`** (ip65 short path; otherwise it does a full chip reset in software) |
| 2 | `$001B` | **TMSR** → **`06`** |
| 3 | `$0009`–`000E` | **SHAR** (6 bytes) → **`00 08 DC A2 A2 A2`** (same as ip65 `w5100.s`) |
| 4 | `$0403` | Socket 0 **S0_SR** → **`00`** (closed) before driver **OPEN** |
| 5 | (optional) | After **telnet65** has run init, **`$0403`** → **`42`** (**`W5100_SN_SR_MACRAW`**) if **OPEN** succeeded |

Steps 1–3 mirror **`w5100.s`** after the RTR XOR. Step 4 confirms socket 0 is idle. Step 5 is only meaningful **after** a successful **`eth_init`** (e.g. run telnet65 once, drop back to monitor — SR may still show MACRAW if the stack left the socket open).

**Pico UART bisect:** Rebuild Debug with **`-DU2_IP65_CHECKPOINT=n`** (`n` = 1…5). If you see **`ck=4`** but not **`ck=5`**, the Apple reached **RMSR** but not a successful **MACRAW OPEN** (see `docs/ip65-Uthernet-II-integration.md` §3).

**If the monitor passes 1–3 but telnet65 still prints “Device not found”:** That string is **`eth_init` / `ip65_init` failure** only. Use UART checkpoints to see whether the 6502 actually reaches **`ck=5`**. If **`ck=5`** appears, the Ethernet driver init **succeeded** and the message is likely a **different build**, **stale screen**, or a **non-stock** binary — not the RTR probe.

**If telnet65 fails later** (blank screen, timeout, DHCP error): that is usually **not** “device not found” — check **WiFi**, **DHCP**, and **Pico ↔ Apple** with a **Debug** UART capture while reproducing.

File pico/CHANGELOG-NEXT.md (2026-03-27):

# @VERSION@

**1.2 series:** V1.1.24-eo was the final release in the 1.1.x line. Development from **V1.2.0-eo** onward uses the **1.2.x** series, focused on **Uthernet II emulation**, **com port**, and **imagewriter emulation**.

## Network stack and debug updates

- **NetworkPump groundwork:** Added `NetworkPump` and `INetworkSession` skeletons in `pico/network_pump.h` / `pico/network_pump.cpp` so the network layer has a single place to own WiFi init/connection helpers, pcb helpers, and future session/timer/abort routing. This is the first step toward moving NTP, TFTP, and Uthernet II onto a shared pump.
- **TFTP lifecycle routed through the manager:** `ExecuteTFTP()` now calls `NetworkPump::RunTFTP(...)`, which owns the active TFTP run bookkeeping and reset-abort routing while still reusing the legacy TFTP packet engine. Apple reset now calls `NetworkPump_RequestAbortAll()` so an active TFTP run is cancelled through the manager.
- **TFTP host/file safeguard:** The Control Panel TFTP upload page now checks for the swapped/stale host/file case seen in debug traces. If the filename looks like an IPv4 address while the hostname does not, it swaps the values and warns the user before sending the command buffer.
- **Verbose debug logging:** NTP and TestWifi now emit more detailed debug logs in Debug builds, including DNS lookup results, UDP packet validation, and the computed NTP epoch. The Pico debug firmware remains the same build type-wise, but its logs now make the new network flow easier to diagnose.
- **Release packaging:** The Pico build now packages the current `cpanel.bin` into both debug and release firmware images, so the Control Panel and Pico firmware stay in sync.

## WiFi kept online between sessions

- **No teardown on session end:** The CUDPTask destructor no longer disconnects or deinitializes WiFi when a TFTP/NTP/TestWifi session completes. Only the UDP PCB and RX buffer are freed; CYW43 and the connection stay up.
- **Fast restart:** Subsequent TFTP/NTP sessions skip InitCyw43 (static guard) and ConnectWifi returns immediately when already LINK_UP. TFTP starts much faster when run again soon after a previous session.
- **TFTP receive fix (reuse path):** When reusing WiFi, ConnectWifi now runs a ~100 ms warmup (100× `cyw43_arch_poll()` + 1 ms) before returning. This stabilizes lwIP/CYW43 so the new UDP PCB can receive (addresses pico-sdk #915 “sending but not receiving”). `udptask.cpp`.
- **Power:** WiFi stays on at all times; no power saving. `pico/udptask.cpp`.

## Control Panel changes

- **Drives Enable: ROM Disk row fixed:** The ROM Disk checkbox row was missing because it overwrote the last drive (RAM Disk). Fixed: ROM Disk at `YPOS+unitCount+2`; checkbox rows aligned with `PrintDriveList` using `YPOS+1+i`. `cpanel/drivesenable.c`.
- **Drives Enable: ROM disk shown once, checkboxes aligned:** ROM disk was listed twice (in the drive list and on the custom row). Added `GetDriveListCount()` to exclude ROM disk from the list when it is the last unit; ROM disk now appears only on its own row. Checkbox rows corrected to `YPOS+i` so they align with drive lines. `cpanel/ui-misc.c`, `drivesenable.c`.
- **ROM disk excluded from TFTP and Format:** ROM disk is read-only and not formatable; it no longer appears in the TFTP drive-selection list or Format drive-selection list. `cpanel/tftp.c`, `cpanel/format.c`.
- **Drives Enable checkbox alignment:** Checkmarks are now drawn inline when printing each drive row in `PrintDriveListWithCheckboxes`, guaranteeing alignment with drive entries. `cpanel/ui-misc.c`, `cpanel/drivesenable.c`.
- **Build ID left of clock:** CMD_GETFIRMWAREVER (0x29) polls firmware version separately (ProDOS-safe). DisplayTime shows build ID at cols 20–31, time at 32–39. `common/defines.h`, `pico/cmdhandler.c`, `cpanel/asm-megaflash.s`.

## TFTP reverted to original state

- **Reverted:** All TFTP-related changes (RX buffering, session cleanup, UDP timing) reverted for stability. Restored: `udptask.cpp`, `udptask.h`, `tftprxtask.cpp`, `tftprxtask.h`, `flash.c`, `flash.h`, `network.cpp`, `tftpstate.c`, `tftpstate.h` to pre-modification state.

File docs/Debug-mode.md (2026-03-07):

# MegaFlash Debug Mode

MegaFlash has **two separate debug mechanisms**: one in the **Apple II ROM firmware** (6502) and one in the **Pico firmware** (C/C++). They use different outputs and build flags.

---

## 1. Firmware (Apple ROM) debug – Serial Port 1

### What it is

The **firmware** (ROM patches in the `firmware/` folder) can print SmartPort and ProDOS call information to the Apple IIc’s **Serial Port 1** (ACIA at $C098–$C09B). This is intended for debugging driver and ProDOS interaction from the Apple side.

### How to enable

In **`firmware/buildflags.inc`** set:

```asm
DEBUG   EQU   TRUE
```

Default is **FALSE**. Then rebuild the ROM (`make a2c` / `make a2cp`) to get `iic.bin` or `iicplus.bin` with debug enabled.

### What it does

- **Cold start** (`megaflash.s`): Initializes ACIA 1 for debug output (e.g. 19200 baud, no interrupt). Clears IRQ status.
- **`print` routine** (IOROM): Sends one character in A to **acia1data** ($C098), waiting on **acia1status** ($C099) for the transmitter. If bits 5 and 6 of status are set (e.g. MAME without bit-banger), it skips printing so the code doesn’t hang.
- **SmartPort debug** (`smartport.s`):
  - **prnspparam**: Prints `S` + command letter + parameter bytes for SmartPort calls.
  - **prnpdparam**: Prints `P` + ProDOS command letter + unit, buffer address, block number for ProDOS block calls.
  - **prnerr**: Prints `:` + error code + CR/LF.
  - Uses a small command/parameter table for single-letter abbreviations (e.g. S/R/W/F for Status/Read/Write/Format).
- **Conditional code**: All of the above is wrapped in `.if DEBUG` / `.endif`, so with `DEBUG EQU FALSE` it is not assembled into the ROM.

### Output

Debug text goes out over **Serial Port 1** (slot 1). You need a serial terminal or cable on the IIc’s serial port (e.g. modem/printer port) at the baud rate set in the init (e.g. 19200) to see it.

---

## 2. Pico firmware debug – UART / USB

### What it is

The **Pico firmware** (`pico/`) can print diagnostic messages to the Pico’s **stdio** (UART or USB serial). This is controlled by the **build type** (Debug vs Release), not a separate “debug mode” flag at runtime.

### How to enable

Build the Pico firmware as **Debug**:

- Use a **Debug** build directory, e.g. `pico_debug` or `pico2_debug` (from `cmakeall.sh` with `-DCMAKE_BUILD_TYPE=Debug`).
- So: **Debug build** = debug output enabled; **Release build** = debug output disabled.

The C preprocessor symbol **`NDEBUG`** is defined in **Release** builds. In **Debug** builds `NDEBUG` is not defined, so the macros in **`pico/debug.h`** expand to real `printf` calls.

### Log levels (`pico/debug.h`)

`debug.h` defines levels and macros that compile to nothing when `NDEBUG` is set, or to `printf(...)` when it is not:

| Level | Macro | Typical use |
|---|---|---|
| ERROR | ERROR_PRINTF | Errors |
| WARN | WARN_PRINTF | Warnings |
| INFO | INFO_PRINTF | Important events |
| DEBUG | DEBUG_PRINTF | General debug |
| TRACE | TRACE_PRINTF | Fine-grained |

**LOG_LEVEL** is set to **LEVEL_DEBUG**, so ERROR, WARN, INFO, and DEBUG are active in Debug builds; TRACE can be enabled by lowering LOG_LEVEL.

### Where debug is used (examples)

- **main.c**: Startup banner (firmware version, CPU/peri clock, SPI speed, WiFi support, heap). NTP result. In Debug build, UART stdio is initialized (115200 baud) and the bus loop is always started (even when the Apple is not connected) so you can test with the machine off.
- **cmdhandler.c**: Test result, timeout, format (unit, block count, name), CMD_TFTPRUN parameters (dir, unit, hostname, filename).
- **udptask.cpp**: Connect status, BADAUTH, UDP pcb, event loop, SSID/WPA, WiFi connect attempts, link status, IP/gateway/netmask/DNS, DNS lookup result.
- **tftptask.cpp**, **tftprxtask.cpp**, **tftptxtask.cpp**: TFTP options, DNS lookup, server port, OACK, error packets, block capacity, tsize.
- **ntptask.cpp**: NTP request attempt, valid response.
- **network.cpp**: GetNetworkTime, TestWifi, exception.
- **fpu.c**: FPU ops (fac, arg, result) and errors (overflow, divide by zero, etc.) when the Pico does floating point for the Apple.
- **misc.c**: Hex dump of buffer; version string can append ` (DEBUG)` when NDEBUG is not set.
- **rtc.c**: RTC-related debug when NDEBUG is not set.

### Stdio in Debug vs Release

- **Debug** (`NDEBUG` not defined): `stdio_uart_init()` is called (default 115200 baud). `setbuf(stdout, NULL)` so output is unbuffered. Debug prints go to **UART** (e.g. GPIO UART on the Pico).
- **Release** (`NDEBUG` defined): `stdio_set_driver_enabled(&stdio_uart, false)` so UART stdio is disabled. All `DEBUG_PRINTF` etc. compile to no-ops.

So in practice, “Pico debug mode” = **Debug build** → UART on, `DEBUG_PRINTF` (and other level macros) active; **Release build** → UART off, no debug print.

### lwIP (Pico W / Pico 2 W)

In **`pico/lwipopts.h`**, when **NDEBUG** is not defined, **LWIP_DEBUG** is set to 1. Other lwIP debug options (e.g. TCP_DEBUG, UDP_DEBUG) remain off by default, but you can turn them on there for network-level debugging.

---

## Summary

| Layer | Flag / build | Output | Purpose |
|---|---|---|---|
| **Firmware** (6502) | `DEBUG EQU TRUE` in `buildflags.inc` | Serial Port 1 (ACIA $C098–$C09B) | SmartPort/ProDOS call tracing on the Apple |
| **Pico** (C/C++) | Debug build (no `NDEBUG`) | UART (e.g. 115200)  | Commands, TFTP, WiFi, NTP, FPU, heap, etc. |

- **Firmware debug**: Rebuild ROM with `DEBUG EQU TRUE`; connect a terminal to the IIc’s Serial Port 1.
- **Pico debug**: Build from `pico_debug` or `pico2_debug` and connect a serial terminal to the Pico’s UART (or USB if used for stdio) to see `DEBUG_PRINTF` and related output.

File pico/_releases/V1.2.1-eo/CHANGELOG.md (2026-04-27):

# V1.2.1-eo

**1.2 series:** V1.1.24-eo was the final release in the 1.1.x line. Development from **V1.2.0-eo** onward uses the **1.2.x** series, focused on **Uthernet II emulation**, **com port**, and **imagewriter emulation**.

## Uthernet II / ip65 fixes

- **Fixed W5100 TX pointer register reads:** `SN_TX_RD0/1` and `SN_TX_WR0/1` now return the real emulated register bytes instead of incorrectly falling through `RX_RSR` handling. This fixes host-side pointer corruption that produced malformed MACRAW TX frames.
- **Fixed MACRAW RX length prefix compatibility:** MACRAW RX enqueue now writes wire length as `len+2` in the 2-byte prefix (W5100 convention), avoiding frame truncation in clients that subtract 2 from the prefix.
- **DHCP payload mutation rollback for compatibility:** Outbound DHCP handling now avoids rewriting BOOTP payload fields (`chaddr` / client-id option path) and keeps only Ethernet source MAC normalization, reducing client-side validation mismatch risk.

## Uthernet networking stability and diagnostics

- **Core-affinity stabilization:** Uthernet network polling/transmit path remains constrained to core 0 service flow to avoid CYW43/lwIP `async_context` wrong-core panics.
- **Low-noise Ethernet tracing support:** Header-level Uthernet tracing (`[u2eth]`) and optional checkpoint/bus diagnostics were used to validate frame flow while keeping logs manageable.
- **Additional MACRAW instrumentation:** Monitor/tap events were extended for SEND pointer progression and queue-stage payload inspection to isolate pre-core0 vs post-core0 corruption.

## Notes

- This release includes substantial Uthernet emulation correctness work and debugability improvements used to validate ip65/Telnet/Contiki/ADTPro paths.

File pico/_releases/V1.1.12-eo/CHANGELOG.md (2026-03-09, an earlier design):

# V1.1.12-eo

## TFTP session cleanup after cancel/error

- **Session cleanup:** When a TFTP upload or download is cancelled or ends in error, the job is now cleaned up so the next TFTP run starts fresh and does not "reconnect" to the previous session.
- **TFTPResetSessionState():** New function in `tftpstate.c` resets session state (taskid, blockTransferred, tsize, retries, error, status to IDLE). It does not clear unitNum, dir, hostname, filename (those are set by the Control Panel before each run).
- **When it runs:** At the start of every `ExecuteTFTP()` (on Core 0), before creating the TFTP task. So when you start a new TFTP transfer after a failed or cancelled one, any stale state from the previous run is cleared and the new session uses only the new parameters.
- **Resource cleanup:** The previous behaviour (delete task on exit so destructor runs, tearing down UDP PCB and CYW43) is unchanged; the new reset ensures `tftp_state` is also in a clean state for the next run.

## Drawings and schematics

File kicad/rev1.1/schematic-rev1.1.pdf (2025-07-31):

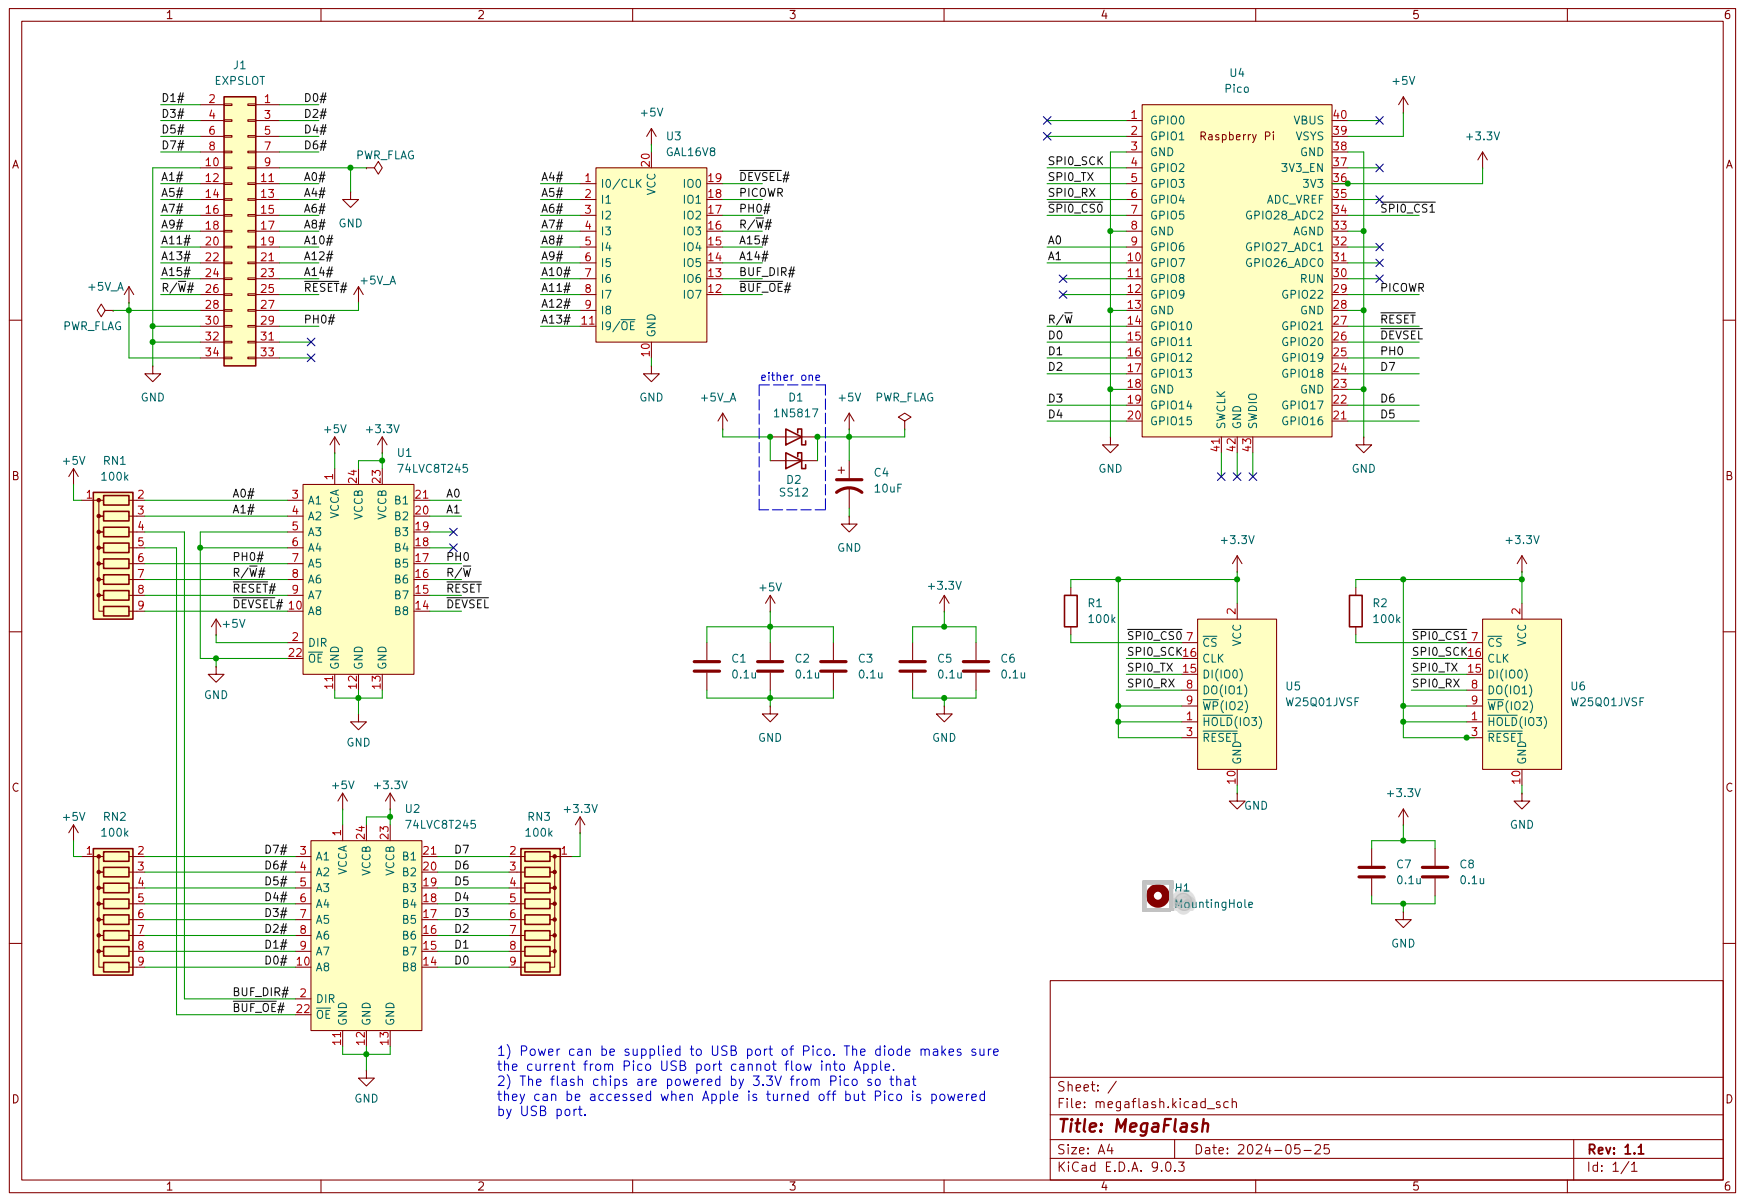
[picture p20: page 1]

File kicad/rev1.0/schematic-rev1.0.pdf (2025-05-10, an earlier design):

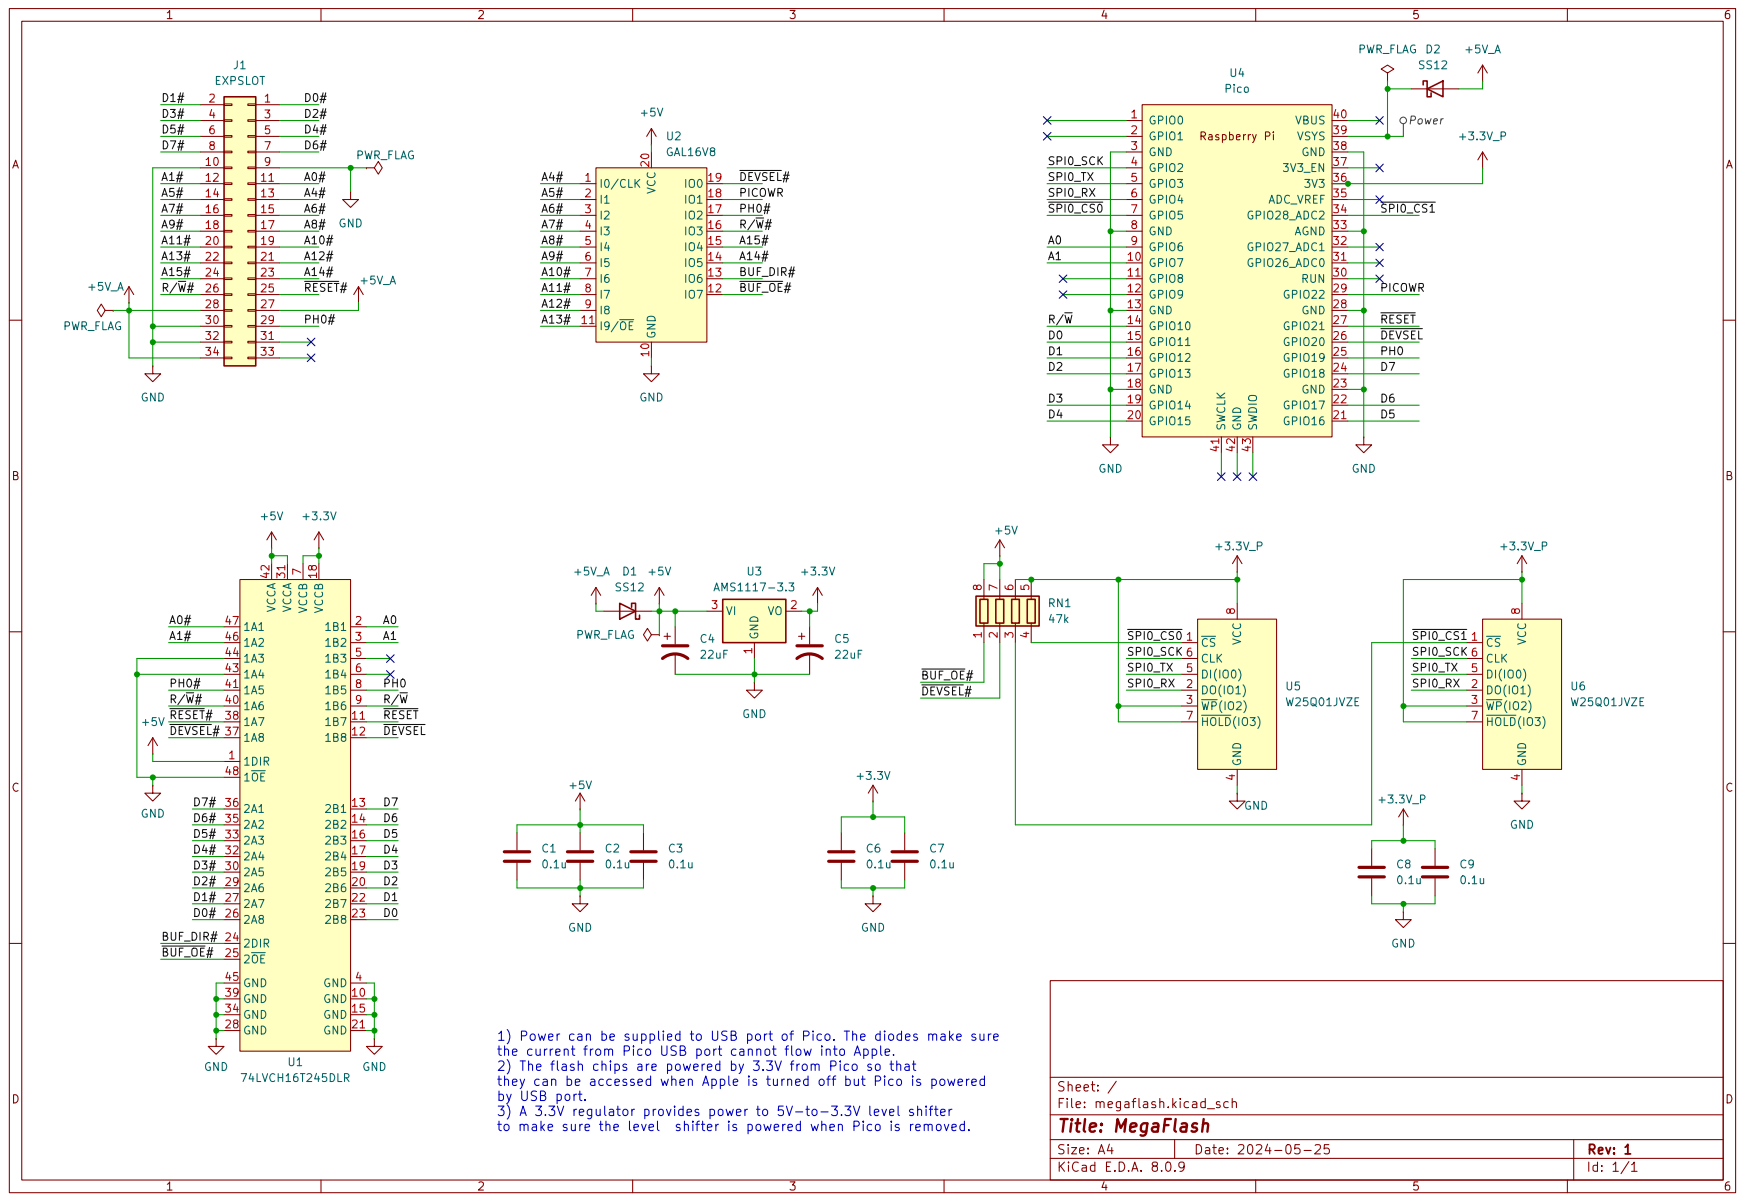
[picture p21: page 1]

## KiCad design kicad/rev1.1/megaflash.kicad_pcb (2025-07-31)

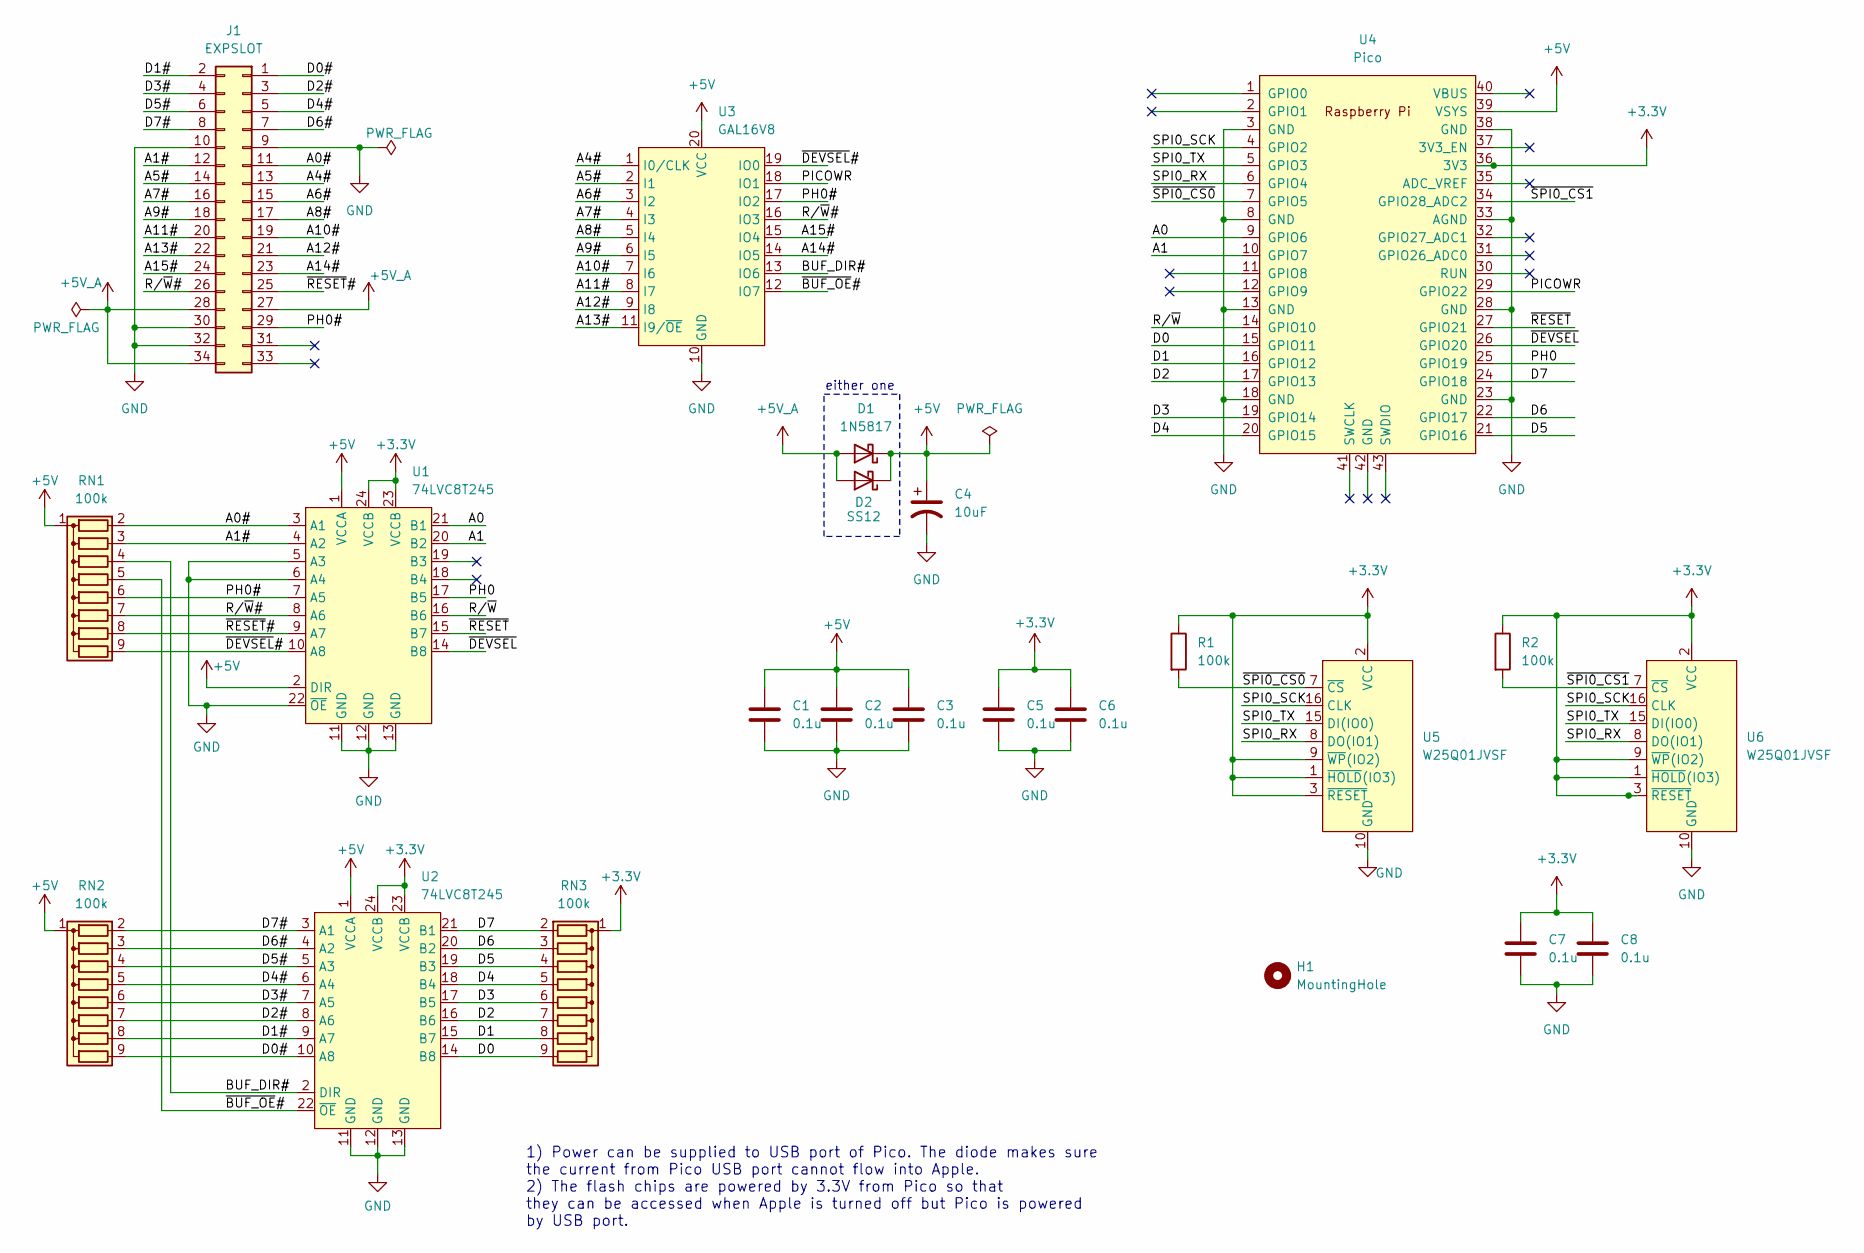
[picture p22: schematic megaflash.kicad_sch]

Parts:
C1, C2, C3, C5, C6, C7, C8: 0.1u; C_Disc_D5.1mm_W3.2mm_P5.00mm; Mouser Part No 594-K104K15X7RF5WH5
C4: 10uF; CP_Radial_D5.0mm_P2.00mm; Mouser Part No 710-860010372001
D1: 1N5817; D_DO-41_SOD81_P10.16mm_Horizontal; Mouser Part No 625-1N5817-E3/53
D2: SS12; D_SMA; Mouser Part No 625-SS12-E3
H1: MountingHole; MountingHole_2.7mm_M2.5
J1: EXPSLOT; PinHeader_2x17_P2.54mm_Vertical_Mirror; Mouser Part No 200-TSW11715GD
R1, R2: 100k; R_Axial_DIN0207_L6.3mm_D2.5mm_P10.16mm_Horizontal
RN1, RN2, RN3: 100k; R_Array_SIP9; Mouser Part No 652-4609X-1LF-100K
U1, U2: 74LVC8T245; SOIC-24W_7.5x15.4mm_P1.27mm; Mfr Part No SN74LVC8T245DWR; Mouser Part No 595-SN74LVC8T245DWR
U3: GAL16V8; DIP-20_W7.62mm_LongPads
U4: Pico; RPi_Pico_SMD_NO_LABEL_NO_DEBUG
U5, U6: W25Q01JVSF; SOIC-16W_7.5x10.3mm_P1.27mm; Mouser Part No 454-W25Q01JVSFIM

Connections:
+3.3V: C5.1, C6.1, C7.1, C8.1, R1.1, R2.1, RN3.1 (common), U1.23 (VCCB), U1.24 (VCCB), U2.23 (VCCB), U2.24 (VCCB), U4.36 (3V3), U5.1 (~HOLD(IO3)), U5.2 (VCC), U5.3 (~RESET), U5.9 (~WP(IO2)), U6.1 (~HOLD(IO3)), U6.2 (VCC), U6.3 (~RESET), U6.9 (~WP(IO2))
+5V: C1.1, C2.1, C3.1, C4.1, D1.1 (K), D2.1 (K), RN1.1 (common), RN2.1 (common), U1.1 (VCCA), U1.2 (DIR), U2.1 (VCCA), U3.20 (VCC), U4.39 (VSYS)
+5V_A: D1.2 (A), D2.2 (A), J1.27, J1.28, J1.34
/A0: U1.21 (B1), U4.9 (GPIO6)
/A0#: J1.11, RN1.2 (R1), U1.3 (A1)
/A1: U1.20 (B2), U4.10 (GPIO7)
/A1#: J1.12, RN1.3 (R2), U1.4 (A2)
/A4#: J1.13, U3.1 (I0/CLK)
/A5#: J1.14, U3.2 (I1)
/A6#: J1.15, U3.3 (I2)
/A7#: J1.16, U3.4 (I3)
/A8#: J1.17, U3.5 (I4)
/A9#: J1.18, U3.6 (I5)
/A10#: J1.19, U3.7 (I6)
/A11#: J1.20, U3.8 (I7)
/A12#: J1.21, U3.9 (I8)
/A13#: J1.22, U3.11 (I9/~OE)
/A14#: J1.23, U3.14 (IO5)
/A15#: J1.24, U3.15 (IO4)
/BUF_DIR#: RN1.4 (R3), U2.2 (DIR), U3.13 (IO6)
/D0: RN3.9 (R8), U2.14 (B8), U4.15 (GPIO11)
/D0#: J1.1, RN2.9 (R8), U2.10 (A8)
/D1: RN3.8 (R7), U2.15 (B7), U4.16 (GPIO12)
/D1#: J1.2, RN2.8 (R7), U2.9 (A7)
/D2: RN3.7 (R6), U2.16 (B6), U4.17 (GPIO13)
/D2#: J1.3, RN2.7 (R6), U2.8 (A6)
/D3: RN3.6 (R5), U2.17 (B5), U4.19 (GPIO14)
/D3#: J1.4, RN2.6 (R5), U2.7 (A5)
/D4: RN3.5 (R4), U2.18 (B4), U4.20 (GPIO15)
/D4#: J1.5, RN2.5 (R4), U2.6 (A4)
/D5: RN3.4 (R3), U2.19 (B3), U4.21 (GPIO16)
/D5#: J1.6, RN2.4 (R3), U2.5 (A3)
/D6: RN3.3 (R2), U2.20 (B2), U4.22 (GPIO17)
/D6#: J1.7, RN2.3 (R2), U2.4 (A2)
/D7: RN3.2 (R1), U2.21 (B1), U4.24 (GPIO18)
/D7#: J1.8, RN2.2 (R1), U2.3 (A1)
/PH0: U1.17 (B5), U4.25 (GPIO19)
/PH0#: J1.29, RN1.6 (R5), U1.7 (A5), U3.17 (IO2)
/PICOWR: U3.18 (IO1), U4.29 (GPIO22)
/R/~W: U1.16 (B6), U4.14 (GPIO10)
/R/~W#: J1.26, RN1.7 (R6), U1.8 (A6), U3.16 (IO3)
/SPI0_RX: U4.6 (GPIO4), U5.8 (DO(IO1)), U6.8 (DO(IO1))
/SPI0_SCK: U4.4 (GPIO2), U5.16 (CLK), U6.16 (CLK)
/SPI0_TX: U4.5 (GPIO3), U5.15 (DI(IO0)), U6.15 (DI(IO0))
/~BUF_OE#: RN1.5 (R4), U2.22 (~OE), U3.12 (IO7)
/~DEVSEL: U1.14 (B8), U4.26 (GPIO20)
/~DEVSEL#: RN1.9 (R8), U1.10 (A8), U3.19 (IO0)
/~RESET: U1.15 (B7), U4.27 (GPIO21)
/~RESET#: J1.25, RN1.8 (R7), U1.9 (A7)
/~SPI0_CS0: R1.2, U4.7 (GPIO5), U5.7 (~CS)
/~SPI0_CS1: R2.2, U4.34 (GPIO28_ADC2), U6.7 (~CS)
GND: C1.2, C2.2, C3.2, C4.2, C5.2, C6.2, C7.2, C8.2, J1.9, J1.10, J1.30, J1.32, U1.5 (A3), U1.6 (A4), U1.11 (GND), U1.12 (GND), U1.13 (GND), U1.22 (~OE), U2.11 (GND), U2.12 (GND), U2.13 (GND), U3.10 (GND), U4.3 (GND), U4.8 (GND), U4.13 (GND), U4.18 (GND), U4.23 (GND), U4.28 (GND), U4.33 (AGND), U4.38 (GND), U5.10 (GND), U6.10 (GND)

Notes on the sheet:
1) Power can be supplied to USB port of Pico. The diode makes sure the current from Pico USB port cannot flow into Apple. 2) The flash chips are powered by 3.3V from Pico so that they can be accessed when Apple is turned off but Pico is powered by USB port.
either one

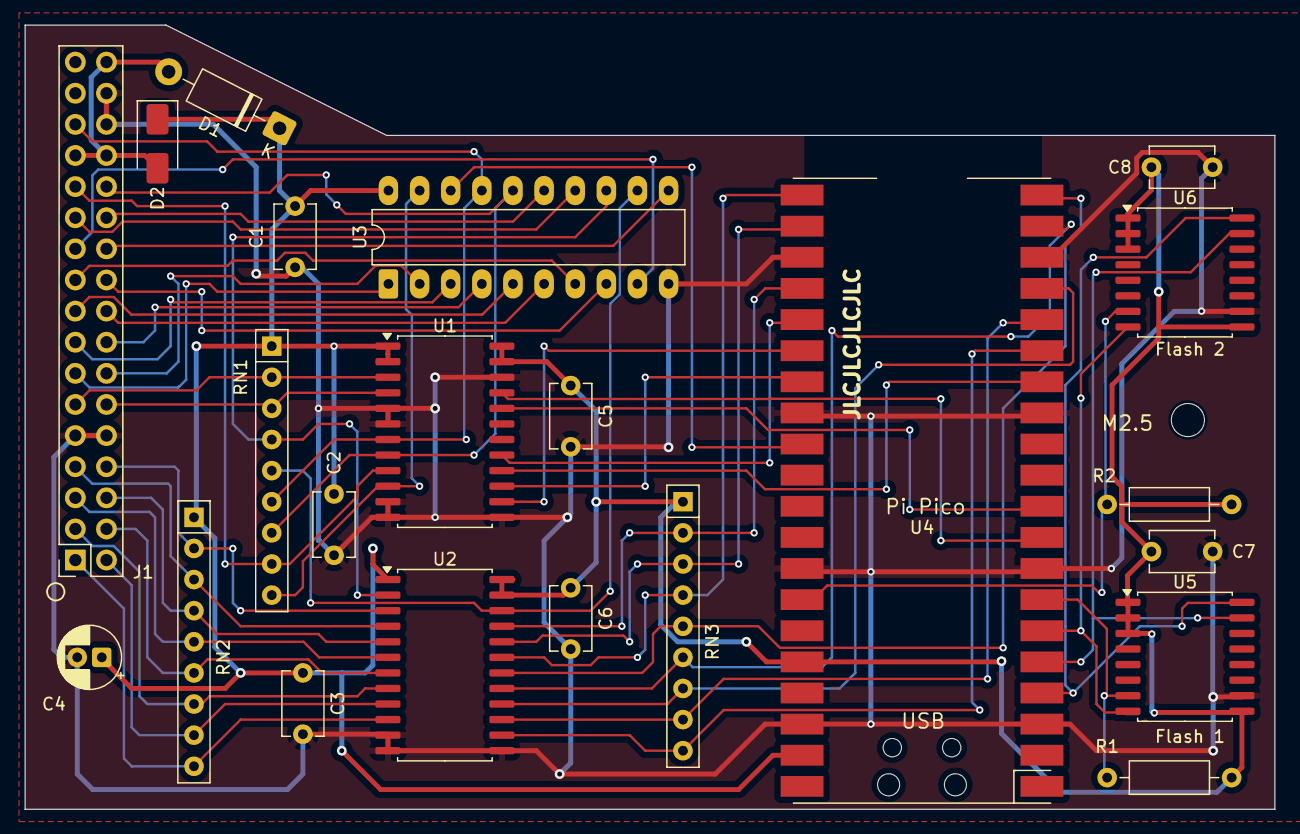
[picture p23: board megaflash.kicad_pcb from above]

Board: 2 copper layers, 102.0 x 64.0 mm, 23 parts (0 on the bottom side), 52 nets.

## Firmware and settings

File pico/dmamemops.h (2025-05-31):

#ifndef _DMAMEMOPS_H
#define _DMAMEMOPS_H

#ifdef __cplusplus
extern "C" {
#endif

#include "hardware/dma.h"

//
// Default CRC Seeds
//
#define DEFAULT_CRC16_SEED 0						/* As defined in XMODEM-CRC */
#define DEFAULT_CRC32_SEED 0xffffffff

//
// Memory Operation Routines
//
void InitDMAChannel();
int GetMemoryDMAChannel();
void CopyMemory(uint8_t* dest,const uint8_t *src,const uint32_t len);
void CopyMemoryAligned(uint8_t* dest,const uint8_t *src,const uint32_t len);
void CopyMemoryAlignedBG(uint8_t* dest,const uint8_t *src,const uint32_t len);
void ZeroMemory(uint8_t *dest,const uint32_t len);
void ZeroMemoryAligned(uint8_t *dest,const uint32_t len);
void ZeroMemoryAlignedBG(uint8_t *dest,const uint32_t len);

////////////////////////////////////////////////////////////////
//wait until DMA transfer is complete
static inline void DMAWaitFinish() {
	dma_channel_wait_for_finish_blocking(GetMemoryDMAChannel());	
}

static inline void SetCRC16Seed(const uint channel, const uint32_t seed){
	dma_sniffer_set_output_invert_enabled (false);
	dma_sniffer_set_output_reverse_enabled(false);														
	dma_sniffer_enable(channel, DMA_SNIFF_CTRL_CALC_VALUE_CRC16 , true);		
	dma_sniffer_set_data_accumulator(seed);
}

static inline void SetCRC32Seed(const uint channel, const uint32_t seed) {
	dma_sniffer_set_output_invert_enabled (true);
	dma_sniffer_set_output_reverse_enabled(true);														
	dma_sniffer_enable(channel, DMA_SNIFF_CTRL_CALC_VALUE_CRC32R , true);	
	dma_sniffer_set_data_accumulator(seed);		
}

static inline void SetChecksumSeed(const uint channel, const uint32_t seed) {
  dma_sniffer_set_output_invert_enabled (false);
	dma_sniffer_set_output_reverse_enabled(false);														
	dma_sniffer_enable(channel, DMA_SNIFF_CTRL_CALC_VALUE_SUM , true);		
	dma_sniffer_set_data_accumulator(seed);
}


static inline uint32_t GetCRC() {
	return dma_sniffer_get_data_accumulator();
}

static inline uint32_t GetChecksum() {
	return dma_sniffer_get_data_accumulator();
}

uint32_t CRC16(const uint8_t *src,const uint32_t len);
uint32_t CRC16Aligned(const uint8_t *src,const uint32_t len);
uint32_t CRC32(const uint8_t *src,const uint32_t len);
uint32_t CRC32Aligned(const uint8_t *src,const uint32_t len);

#ifdef __cplusplus
}
#endif

#endif

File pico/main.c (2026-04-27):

#include "pico/stdio.h"
#include "pico/stdlib.h"
#include "hardware/gpio.h"
#include "hardware/clocks.h"
#include "hardware/spi.h"
#include "pico/multicore.h"
#include "defines.h"
#include "build_id.h"
#include "debug.h"
#include "a2bus.h"
#include "busloop.h"
#include "busloop_wa.h"
#include "flash.h"
#include "flashunitmapper.h"
#include "dmamemops.h"
#include "misc.h"
#include "userconfig.h"
#include "cmdhandler.h"
#include "terminal.h"
#include "slinky.h"
#include "ramdisk.h"
#include "ipc.h"
#include "network.h"
#include "tftpstate.h"
#include "uthernet2.h"
#include "uthernet2_net.h"
#include "u2_monitor.h"

static inline void InitActLed() {
  gpio_init(ACT_LED_PIN);
  gpio_set_dir(ACT_LED_PIN, GPIO_OUT);
  gpio_put(ACT_LED_PIN, 1); //turn it off
}

//
//GPIO Interrupt call back. 

void gpio_intr_callback(uint gpio, uint32_t events){
  if (gpio==nRESET_PIN) {
    //Abort TFTP network task if Apple is reset
    //during TFTP transfer
    NetworkPump_RequestAbortAll();
    
    //Abort Erase Flash Disk
    //Read the note at AbortEraseFlashDisk() for more info
    AbortEraseFlashDisk();
  }
}

//
// Interrupt if Apple Reset signal is active and calloc
// gpio_intr_callback()
static void EnableAppleResetInterrupt() {
  gpio_init(nRESET_PIN);
  gpio_set_irq_enabled_with_callback(nRESET_PIN, GPIO_IRQ_EDGE_FALL, true /*enabled*/, &gpio_intr_callback);
}

//
//Use Core 1 to run Bus Loop
//
void __no_inline_not_in_flash_func(core1Main)() {
  //No interrupt on this core
  //Bus Loop is time critical
  save_and_disable_interrupts();  

  //Initalize data
  CommandHandlerInit();
   
#ifdef PICO_RP2040
  //RP2040 does not have enough memory to emulate a slinky (min: 256kB)
  BusLoopWaitActiviation();
#else
  SlinkyInit();
  BusLoopSlinky();
#endif
  
  //Start actual bus loop
  BusLoopDataInit();    //It takes 8us to complete the initialization
  BusLoop();
}

volatile bool updateNTPNow = false;

//
// Core 0: lwIP/CYW43 poll + IPC from core 1 (Test WiFi, TFTP).
// Must run whenever Pico W is used: both inside core0Loop and on the
// USB-terminal path when appleConnected was false at boot (otherwise
// IPC is never popped and Test WiFi hangs; WiFi LED/stack stay idle).
//
static void PicoW_ServiceCore0IpcAndNetwork(uint64_t fifo_timeout_us) {
  uint32_t param;
  bool msgReceived = multicore_fifo_pop_timeout_us(fifo_timeout_us, &param);
  U2_Net_Poll();
  U2_MonPollFlush();
  if (msgReceived) {
    struct IpcMsg *msg = (struct IpcMsg *)param;
    if (msg->command == IPCCMD_WIFITEST) {
      TestWifi((TestResult_t *)msg->data);
    } else if (msg->command == IPCCMD_TFTP) {
      ExecuteTFTP(msg->data /* taskid */);
    }
  }
}

//
//Use Core 0 to run background task such as TFTP or NTP Time sync
//
void __no_inline_not_in_flash_func(core0Loop)() {
  const uint32_t NEXTUPDATE_SUCCESS = (24*60*60*1000);  //If last NTP update is successful, re-sync in 24hr
  const uint32_t NEXTUPDATE_FAILED  = (5*60*1000);      //If last NTP update failed, try again in 5 min
  absolute_time_t nextUpdateTime;
  
  if (CheckPicoW()) {
    do {
      updateNTPNow = false;
      U2_MonPollFlush();
      int err = GetNetworkTime();
      DEBUG_PRINTF("GetNTP err=%d (%d=NETERR_NONE)\n",err,NETERR_NONE);
      if (err==NETERR_NONE) nextUpdateTime = make_timeout_time_ms(NEXTUPDATE_SUCCESS);
      else nextUpdateTime = make_timeout_time_ms(NEXTUPDATE_FAILED);

        //wait until nextUpdateTime or msg from other core
        do {
#if defined(NDEBUG)
          ReleaseUpdateBusUsbGate();
#endif
          PicoW_ServiceCore0IpcAndNetwork(50 * 1000);
        } while (!time_reached(nextUpdateTime) && !updateNTPNow);
      
    } while(1);
  } else {
    //Not running on PicoW
    //Keep popping fifo queue to avoid blocking
    while(1) multicore_fifo_pop_blocking();
  }
}

int main() {
  InitPIO();  
  InitSpi();
  InitFlash();
  InitActLed();
  InitDMAChannel();
  InitRamdisk();
  InitTFTPState();
  
  //Enable Pull-down resistors of unused GPIOs
  gpio_pull_down(0);
  gpio_pull_down(1);
  gpio_pull_down(26);

#ifndef NDEBUG
  //For sending Debug Message to UART
  stdio_uart_init();    //Default baud: 115200

  //Disable stdout buffering
  //otherwise, text is not printed to uart or usb correctly.
  setbuf(stdout, NULL);
#else
  //Disable stdio_uart for Release Build
  stdio_set_driver_enabled(&stdio_uart, false);
#endif

  /* After UART: U2_Init / U2_MonInit use printf — if this ran earlier, [u2]/[u2m] boot text was lost. */
  U2_Init();

  //Load userConfig and Wifi Settings from security registers
  LoadAllConfigs();  
  
  //Setup Flash Units Mapping Data
  SetupFlashUnitMapping();  
  EnableFlashUnitMapping();

  //Check if we are connecting to Apple IIc
  bool appleConnected = IsAppleConnected();
  
  //Enable Apple Reset Interrupt only if we are connected to Apple IIc
  //The /Reset signal at the expansion slot connector is floating if
  //MegaFlash is not connected to Apple. There is no pull-up resistor
  //at the transceiver input on Rev 1.0PCB. So, enable interrupt only 
  // when appleConnected is true
  if (appleConnected) {
    EnableAppleResetInterrupt();
  }

#if defined(NDEBUG)
  ReleaseInitBusUsbGate(appleConnected);
#endif
  
  //
  // Core1: Apple Bus Loop
  // Always launch Core1 so the bus loop runs. In Release we previously
  // only launched when appleConnected; that made the network stack appear
  // broken when IsAppleConnected() was false at boot (e.g. timing/PHI0).
  // Matching Debug (always run bus loop) fixes Release network behaviour.
  //
  multicore_launch_core1(core1Main);

  //
  //Save initialized setting from memory to flash if needed
  //See LoadAllConfigs() in userconfig.c
  //
  SaveConfigs();

  //
  //Print Debug Infomation to serial port
  //
  DEBUG_PRINTF("\nMegaflash DEBUG Firmware Version %d (%s)\n",
               FIRMWAREVER, FIRMWAREVERSTR);
  /* Always print: build scripts set Unix time + UTC string; plain CMake leaves 0 / "unknown". */
  DEBUG_PRINTF("Firmware build: %s  (%lu Unix s)\n",
               FIRMWARE_BUILD_TIMESTAMP_STR,
               (unsigned long)(uint32_t)FIRMWARE_BUILD_TIMESTAMP);
  DEBUG_PRINTF("CPU Clock Speed =%dMHz\n",clock_get_hz(clk_sys)/1000000);
  DEBUG_PRINTF("clk_peri =%dMHz\n",clock_get_hz(clk_peri)/1000000);
  DEBUG_PRINTF("SPI Speed = %dMHz\n",spi_get_baudrate(spi0)/1000000);
  DEBUG_PRINTF("WIFI Supported = %s\n",CheckPicoW()?"Yes":"No");
  DEBUG_PRINTF("Total heap = %d\n",GetTotalHeap());
  DEBUG_PRINTF("Free heap  = %d\n",GetFreeHeap());
  
  //
  // Core0: On Pico W run the network loop (NTP/TFTP/WiFi test); otherwise
  // run User Terminal. Use CheckPicoW() so the network stack runs on Pico W
  // regardless of appleConnected (avoids Release breakage when IsAppleConnected()
  // is false at boot due to timing).
  //
  if (CheckPicoW()) {
    /* USB before core0Loop so Release stdio_usb_connected() / gate are valid in core0Loop. */
    stdio_usb_init();
    InitPicoLed();
#if defined(NDEBUG)
    ReleaseUpdateBusUsbGate();
#endif

    // If no Apple II is detected, keep USB stdio responsive by running the
    // interactive terminal instead of the network loop. This restores the
    // previous "USB console works when powered from USB" behaviour.
    //
    // When Apple is detected, switch into the network loop (NTP/TFTP/WiFi).
    if (appleConnected) {
      core0Loop();  // NTP, TFTP, WiFi test
    }

    absolute_time_t nextAppleCheck = make_timeout_time_ms(2000);
    while (true) {
#if defined(NDEBUG)
      ReleaseUpdateBusUsbGate();
#endif
      /* lwIP + IPC (Test WiFi / TFTP) when not in core0Loop; non-blocking FIFO. */
      PicoW_ServiceCore0IpcAndNetwork(0);
      // If Apple becomes connected later, enable reset interrupt and start
      // the network loop. Note: this only triggers between terminal sessions.
      if (time_reached(nextAppleCheck)) {
        nextAppleCheck = make_timeout_time_ms(2000);
        if (IsAppleConnected()) {
          EnableAppleResetInterrupt();
          core0Loop();  // NTP, TFTP, WiFi test
        }
      }

#if defined(NDEBUG)
      if (stdio_usb_connected() && !IsAppleConnected()) {
        UserTerminal();
      } else
#else
      if (stdio_usb_connected()) {
        UserTerminal();
      } else
#endif
      {
        /* Poll network stack while idle; a plain sleep_ms(1000) starved cyw43. */
        absolute_time_t sleep_until = make_timeout_time_ms(1000);
        while (!time_reached(sleep_until)) {
          PicoW_ServiceCore0IpcAndNetwork(0);
          sleep_ms(1);
        }
      }
    }
  } else {
    stdio_usb_init();
    InitPicoLed();
#if defined(NDEBUG)
    ReleaseUpdateBusUsbGate();
#endif

    while(1) {
#if defined(NDEBUG)
      ReleaseUpdateBusUsbGate();
#endif
#if defined(NDEBUG)
      if (stdio_usb_connected() && !IsAppleConnected()) {
        UserTerminal();
      } else if (!stdio_usb_connected()) {
        sleep_ms(1000);
      } else {
        /* USB cable connected but Apple II bus mode: do not run USB terminal. */
        sleep_ms(10);
      }
#else
      if (stdio_usb_connected()) {
        UserTerminal();
      } else {
        sleep_ms(1000);
      }
#endif
    }
  }

  while(true);
  return 0;
}

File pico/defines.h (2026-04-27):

#ifndef _megaflash_defines_h
#define _megaflash_defines_h

#include "hardware/gpio.h"
#include "../common/defines.h"

/****************************************************

     Constants

****************************************************/

#define FIRMWAREVER     0x0021
#define FIRMWAREVERSTR  "V1.2.1-eo"
// Per-build id is NOT here: CMake generates build_id.h (Unix + human-readable UTC string; see build_id.h.in, build-both.sh).
// 0x0000 = V0.1
// 0x0001 = V0.2   18-Apr-2025
// 0x0002 = V0.3   05-May-2025
// 0x0003 = V1.0   14-Jul-2025
// 0x0004 = V1.1   30-Jul-2025
// 0x0005 = V1.1.1 04-Aug-2025
// 0x0006 = V1.1.2 11-Aug-2025
// 0x0007 = V1.1.3 15-Aug-2025
// 0x0008 = V1.1.4 18-Aug-2025
// 0x0009 = V1.1.5 25-Aug-2025
// 0x000a = V1.1.6-eo 02-Mar-2026
// 0x000b = V1.1.7-eo 02-Mar-2026
// 0x000c = V1.1.8-eo 05-Mar-2026
// 0x000d = V1.1.9-eo 08-Mar-2026
// 0x000e = V1.1.10-eo 08-Mar-2026
// 0x000f = V1.1.11-eo 08-Mar-2026
// 0x0010 = V1.1.12-eo 08-Mar-2026
// 0x0011 = V1.1.13-eo 08-Mar-2026
// 0x0012 = V1.1.14-eo 08-Mar-2026
// 0x0013 = V1.1.15-eo 09-Mar-2026
// 0x0014 = V1.1.16-eo 09-Mar-2026
// 0x0015 = V1.1.17-eo 09-Mar-2026
// 0x0016 = V1.1.18-eo 09-Mar-2026
// 0x0017 = V1.1.19-eo 17-Mar-2026
// 0x0018 = V1.1.20-eo 17-Mar-2026
// 0x0019 = V1.1.21-eo 18-Mar-2026
// 0x001a = V1.1.22-eo 18-Mar-2026
// 0x001b = V1.1.23-eo 18-Mar-2026
// 0x001c = V1.1.24-eo 21-Mar-2026  (last 1.1.x maintenance release)
// 0x0020 = V1.2.0-eo 21-Mar-2026  (1.2.x series: Uthernet II, com port, imagewriter)
// 0x0021 = V1.2.1-eo 26-Apr-2026

//Deivce Signature Bytes
#define SIGNATURE1 0x88
#define SIGNATURE2 0x74

//IDREG Initial Value
#define IDREG_VAL 0x96

//
//Formatter
//
#define FMT_MINBLOCKCOUNT 32
#define FMT_MAXBLOCKCOUNT 0xffff
#define FMT_VOLNAMEMAXLEN 15
#define FMT_DEFAULTVOLNAME "MEGAFLASH"


//RAM Disk Size in Bytes
#ifdef PICO_RP2040
#define RAMDISK_SIZE (140*1024)
#else
#define RAMDISK_SIZE (256*1024)   /* RP2350: was 400 KiB; smaller leaves more heap for WiFi/TFTP */
#endif

//Slinky Size in Bytes
#ifdef PICO_RP2040
#define SLINKY_SIZE (128*1024)
#else
#define SLINKY_SIZE (256*1024)
#endif

//Buffer Size
#define PARAMBUFFERSIZE  32 //Note: Smartport DIB requires 25 bytes
#define PARAMBUFFERINDEXMASK 0b11111
#define DATABUFFERSIZE   512
#define DATABUFFERINDEXMASK  0b111111111
#define BLOCKSIZE        512
#define PAGESIZE         256

//////////////////////////////////////////////////////////////////


//I/O Pins
#define PHI0_PIN 19
#define nRESET_PIN   21  /* Apple /Reset PIN, active low */
#define ACT_LED_PIN  26
#define PICO_LED_PIN 25  /* Pico Onboard LED */

/* Address decode only (no GPIO slot select): C0x0–C0x3 = MegaFlash; C0x4–C0x7 only = Uthernet II W5100 ($C0C4–$C0C7). $C0C8–$C0CF are not U2.
 * The bus is presented when the card’s slot is addressed; no pin 27 or other slot-select input. */
#define U2_C0X_OFFSET     4   /* first Uthernet II address */
#define U2_C0X_LAST       7   /* last Uthernet II address ($C0C4–$C0C7 only) */

static inline void TurnOnActLed() {
  gpio_clr_mask(1ul<<ACT_LED_PIN); //Turn on
}

static inline void TurnOffActLed() {
  gpio_set_mask(1ul<<ACT_LED_PIN); //Turn off
}



//Data Buffer Transfer Mode
typedef enum {
  MODE_LINEAR,
  MODE_INTERLEAVED
}transfermode_t;
#define DEFAULTTRANSFERMODE MODE_LINEAR

//MegaFlash Registers Address
#define CMDREG    0 /*$C0C0*/
#define STATUSREG 0 /*$C0C0*/
#define PARAMREG  1 /*$C0C1*/
#define DATAREG   2 /*$C0C2*/
#define IDREG     3 /*$C0C3*/



//ProDOS/SmartPort ReadBlock/WriteBlock Error Code
typedef enum {
  SP_NOERR      = 0,      //No Error
  SP_IOERR      = 0x27,   //I/O Error
  SP_NODRVERR   = 0x28,   //No Device Connected
  SP_NOWRITEERR = 0x2B,   //Write Protected Error
}rwerror_t;



#endif

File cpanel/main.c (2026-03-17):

#include <stdlib.h>
#include <string.h>
#include <conio.h>
#include <stdint.h>
#include <stdbool.h>
#include "defines.h"
#include "textstrings.h"
#include "ui-wnd.h"
#include "ui-misc.h"
#include "asm.h"
#include "config.h"
#include "mainmenu.h"

/******************************************************************
Build Types

Release: 
Output file is cpanel.bin. This file is included into Pico firmware.

Test Build:
Output file is cpanel.as (AppleSingle format). Then, this file is 
added to prodos19.dsk disk image for testing on emulator. Since 
Megaflash hardware does not exist on emulator, dummy test data are
used when the program tries to fetch information from Megaflash. 

MAME is used to test the program since it can emulate Apple IIc and
IIc+. It also support Slinky and serial port emulation.
******************************************************************/


//
//Global Variables
//
UserSettings_t config;
bool isAppleIIcplus;
bool isWifiSupported;
uint8_t boardType;


/////////////////////////////////////////////////////////////////////
// Fatal Error handler
//
void FatalError(uint8_t errorcode) {
  ResetScreen();
  cprintf("Unexpected Error:%d",errorcode);
  newline2();
  cputs(strPressanykeyto_);
  cputs(strreboot);
  beep();
  cgetc();
  Reboot();
}

//////////////////////////////////////////////////////////////////
// Show Device Info String in 80 column mode
//
void ShowDeviceInfoString() {
  set80(); 
  clrscr();
  //Request System Information
  if (!GetInfoString(INFOSTR_DEVICE)) FatalError(ERR_GETDEVINFOSTR_FAIL);  
  PrintStringFromDataBuffer();
  cprintf("Control Panel Build Timestamp = %s %s",__DATE__,__TIME__);
  newline2();
  cputs(strPressanykeyto_);
  cputs(strcontinue);
  cgetc();
  clrscr(); //Clearing the screen before switching to 40 reduces flickering
  set40();
}

void main() { 
  //Destory Reset Vector so that Ctrl-Reset reboot the machine.
  //It ensures the flash drive mapping are enabled after quitting from Control Panel.
  //When the machine reboots, CMD_COLDSTART command is sent. This command re-enables
  //the drive mapping.
  *(char*)0x3F3 = 0x00;
  *(char*)0x3F4 = 0x00;

#ifndef TESTBUILD
  //If the user reset the computer during data transfer, the transfer mode may be left at interleaved.
  //So, reset the mode to linear to avoid potential problem.
  SendCommand(CMD_MODELINEAR);

  //ROM disk at last SmartPort unit so flash/ram are first (unless user chooses "Boot to ROM Disk")
  EnableRomdiskAtLast();

  //Disable Drive Mapping so that we can acces to all drives including RAMDisk
  DriveMapping(false);    //false = disable
  
  //Read Pico Device Info
  SendCommand(CMD_GETDEVINFO);
  boardType = GetParam8Offset(5);                     //Read board type
  isWifiSupported = boardType & 0x80;                 //MSB set if Wifi is supported
  if (ReadOpenAppleButton()) ShowDeviceInfoString();  
#else
  boardType = BRD_PICO2W;
  isWifiSupported = true;
#endif  
  
  isAppleIIcplus = IsAppleIIcplus();
  LoadConfig();
  DoMainMenu();
	
  //Re-enable Drive mapping before quitting
  DriveMapping(true);   //true = enable
  
  ResetScreen();
	return;
}

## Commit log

2025-03-30 Fixed text formatting
    [iic.cfg, merge_iic.cfg, merge_iicp.cfg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]
2025-03-31 Added kicad project
    [megaflash.kicad_pcb, megaflash.kicad_sch]
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2025-04-02 Improvement when FPU_SUPPORT is set to FALSE
    [iic.cfg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]
2025-04-12 Exclude Pico WIFI module area in ground plane
    [megaflash.kicad_pcb]
2025-04-12 Correct the position of Pico antenna
    [megaflash.kicad_pcb]
2025-04-13 Removed all copper in WIFI antenna area
    [megaflash.kicad_pcb, megaflash.kicad_sch]
2025-05-04 Device signature bytes and code cleanup
    [iic.cfg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]
2025-05-09 Enlarged copper pour cutout and corrected pull-up resistors
    [megaflash.kicad_pcb, megaflash.kicad_sch]
2025-05-10 Removed floating input
    [megaflash-B_Cu.gbl, megaflash-B_Mask.gbs, megaflash-B_Paste.gbp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]
2025-05-10 Bill of Materials
    [megaflash.kicad_sch]
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2025-07-21 PCB rev 1.0
    [megaflash-B_Cu.gbl, megaflash-B_Mask.gbs, megaflash-B_Paste.gbp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]
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2025-07-31 Uploaded Rev1.1 PCB design files
    [megaflash-B_Cu.gbl, megaflash-B_Mask.gbs, megaflash-B_Paste.gbp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]
2025-07-31 Corrected Typo
    [megaflash.kicad_sch]
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2025-08-12 Fix: freeze during TFTP download
    [main.c]
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2025-08-17 Abort Erase Flash Disk if Apple is reset
    [main.c]
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2026-03-09 V1.1.13-eo
    # V1.1.13-eo
    ## UDP/TFTP heartbeat reverted to 50 ms
    - **HEARTBEAT_PERIOD:** Reverted from 10 ms back to 50 ms in `udptask.h`. The shorter period caused TFTP upload timeouts and crashes (lwIP re-entrancy risk).
    - **TFTP RX buffering** (V1.1.11) remains: incoming DATA packets are queued during flash erase, so the 50 ms loop is sufficient for most transfers.
    ## Control Panel: ROM Disk row in Drives Enable
    - **ROM Disk visibility:** The ROM Disk checkbox row was not shown because it overwrote the last drive row. Fixed: ROM Disk row is now at `YPOS+unitCount+1`; drive checkboxes use `YPOS+i`. ROM Disk appears on the line after the last drive.
    - **cpanel:** Custom `Beep()` in `asm-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
    [defines.h]
2026-03-09 V1.1.14-eo
    # V1.1.14-eo
    ## WiFi kept online between sessions
    - **No teardown on session end:** The CUDPTask destructor no longer disconnects or deinitializes WiFi when a TFTP/NTP/TestWifi session completes. Only the UDP PCB and RX buffer are freed; CYW43 and the connection stay up.
    - **Fast restart:** Subsequent TFTP/NTP sessions skip InitCyw43 (static guard) and ConnectWifi returns immediately when already LINK_UP. TFTP starts much faster when run again soon after a previous session.
    - **Power:** WiFi stays on at all times; no power saving. `pico/udptask.cpp`.
    ## Control Panel changes
    - **Drives Enable: ROM Disk row fixed:** The ROM Disk checkbox row was missing because it overwrote the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
    [defines.h]
2026-03-09 V1.1.15-eo
    @ -0,0 +1,19 @@
    # V1.1.15-eo
    - **TFTP receive fix (reuse path):** When reusing WiFi, ConnectWifi now runs a ~100 ms warmup (100× `cyw43_arch_poll()` + 1 ms) before returning. This stabilizes lwIP/CYW43 so the new UDP PCB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
    [defines.h]
2026-03-11 V1.1.18-eo
    @ -0,0 +1,20 @@
    # V1.1.18-eo
    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
    [defines.h]
2026-03-18 V1.1.23-eo
    network stack fixes are complete. control panel issues resolved. Wifi is now always on for maximum performance, NTP updates are quick. TFTP upload and download performance has increased by about 300%. Used to take >300 secs on my network, now typical is less than 100 secs, with one observed instance of a 60sec data transfer.
    [defines.h, main.c]
2026-03-21 V1.1.24-eo
    branching 1.1.x here. this will be the last 1.1.x feature release.
    This release has control panel UI fixes and re-enabled USB console when independent of the Apple II.
    [defines.h, main.c]
2026-03-27 V1.1.x: DNS race fix, RAM disk size, TFTP heap diagnostics, U2/pump updates
    Register DNS pending owner before dns_gethostbyname so fast lwIP callbacks
    are not dropped (intermittent DNS timeouts). Reduce RP2350 RAMDISK_SIZE to
    256 KiB to free SRAM for heap and network stacks. Add DebugPrintHeapState
    before TFTP allocation; document TFTP OOM and DNS ordering in implementation
    notes.
    Includes NetworkPump session work, uthernet2_net.cpp (replaces .c), U2 monitor,
    build scripts and build_id template, cpanel RAM disk label comment, and
    session log updates. Excludes local build/ and object-file noise.
    Made-with: Cursor
    [defines.h, main.c]
2026-04-03 Port Thomas storage: RAM disk DMA, ROM memcpy, flash read DMA timeout
    - ramdisk: dedicated DMA channel + InitRamdisk() after InitDMAChannel
    - romdisk: CPU memcpy for reads; keep romdiskFirst / fork defaults
    - flash: ReadFromFlashByDMA timeout/abort + CRC32Aligned fallback in
    tsReadOneBlock/tsReadSector (overclock/TFTP hang mitigation)
    - Docs: SESSION_LOG, Implementation-notes §4e
    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
2026-04-03 Thomas dmamemops + flash SPI timing and security register fix
    - dmamemops: upstream multi-config DMA (copy/zero/CRC 8+32) per channel
    - CMake: OC_RP2350=1 for pico2_w (SPI /CS nops in flash.c)
    - flash: enable_spi0/disable_spi0 extra nops when OC_RP2350
    - flash: tsWriteSecurityRegister partial merge programs full 256 B
    - Docs: SESSION_LOG, Implementation-notes §4e/§4f
    Thomas flash.c/h API rename (ReadBlockFlash, etc.) not merged.
    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
2026-04-06 fswrts + swjmp_ay for ZIP/IIc+ ROM bank return (Thomas)
    - patches: FB19 jmp slxeq; B1_FFC8 sta rombank (fswrts); export fswrts
    - megaflash: cold exit via ($0000)-1 + swjmp_ay; boot menu via BMRUN-1
    - macros: ld16iay
    - iic/iicplus + merge configs: B1_FFC8 fragment
    - Docs: SESSION_LOG, impl notes §4h, upstream comparison table
    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
    [iic.cfg, merge_iic.cfg, merge_iicp.cfg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]
2026-04-06 Add flash-validate ProDOS disk build (romdisk PRODOS/BASIC)
    - tools/flash-validate: FLASHVAL.BAS/DSK.BAS, build-flashval-disk.sh, README
    - Prebuilt FLASHVALID.dsk (800K): PRODOS + BASIC.SYSTEM from romdisk.po, FLASHVAL, FLASHVAL.SRC
    - Use PX/D1 for C0C1/C0C2 ports (PR abbreviates PRINT; fixes AppleCommander -bas)
    - SESSION_LOG + Implementation notes §17
    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
2026-04-07 flash: Alliance JEDEC 0x204020 — mask RDID, explicit 512 Mbit match
    - tsReadJEDECID: 24-bit mask + uint32_t shifts for clean JEDEC assembly
    - ChipIDToCapacity: jedec24 + explicit 0x204020 (Thomas); type_cap unchanged
    - Docs §16 + SESSION_LOG
    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
2026-04-08 Add sponsorship information for MegaFlash project
    Add sponsorship section highlighting PCBway's support for MegaFlash development.
2026-04-12 1.2 beta
    [merge_iic.cfg, merge_iicp.cfg]
2026-06-25 debug build: pico/build-debug.sh
    HEAD=d74bd51 branch=main tree=dirty
    host=Darwin 25.5.0 arm64
    target=pico2_debug board=pico2_w (configure CMake cache for U2_* / FIRMWARE_BUILD_TIMESTAMP)
2026-06-25 debug build: pico/build-debug.sh
    HEAD=25eb1c5 branch=main tree=dirty
    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
2026-06-25 debug build: pico/build-debug.sh
    HEAD=067bdc1 branch=main tree=dirty
    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
2026-06-27 debug build: pico/build-debug.sh
    HEAD=b5e4190 branch=main tree=dirty
    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
2026-06-27 Fix ip65 telnet ingress split and core-0 poll cadence (§10k/§10w/§10x).
    Split MACRAW vs lwIP STA ingress so ip65 software TCP avoids spurious lwIP RSTs,
    drain deferred MACRAW TX from PollOnce during native ops, and service lwIP before
    blocking on the core-0 FIFO with NET_WAKE on U2 SEND/RECV.
    [main.c]
2026-06-27 Add MACRAW TX ring and honest Sn_TX_RD for burst egress (P0-2 §10z).
    Replace the single-slot deferred MACRAW buffer with a bounded queue, advance TX_RD
    only when frames are accepted or sent, and retry stalled SEND commands after
    CYW43 linkoutput failures.
2026-06-28 Fix P0-2 duplicate MACRAW TX race that broke telnet and wget (§10za).
    U2_TryCompletePendingSocket0Send ran on core 0 while Sn_CR was still SEND because
    net wake fired before send_data on core 1, duplicating frames. Remove TryComplete
    and wake core 0 only after send_data completes.
2026-06-30 V1.2.2-eo Pico release
    # V1.2.2-eo
    **1.2 series:** Uthernet II emulation on Pico 2 W (RP2350). Use **`megaflash-pico2.uf2`** from this folder.
    ## Uthernet II / ip65 (§10l + §10k–§10za)
    - **RX ring pointer geometry (§10l):** Monotonic `sn_rx_wr`, coherent `Sn_RX_RD` reads, and correct occupancy math — fixes periodic Contiki wget corruption at ~1390-byte boundaries.
    - **Ingress split + poll cadence (§10k/§10w/§10x):** While ip65 MACRAW is active, inbound frames go to the emulated W5100 ring only (no duplicate lwIP feed / spurious RST). Core 0 polls network before IPC FIFO wait; `IPCCMD_NET_WAKE` on SEND/RECV.
    - **MACRAW TX ring (§10z):** Depth-16 deferred TX queue on RP2350; hon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
    [defines.h]
2026-07-12 debug build: pico/build-debug.sh
    HEAD=a179ac1 branch=main tree=dirty
    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
2026-07-12 debug build: pico/build-debug.sh
    HEAD=92cb5b9 branch=main tree=dirty
    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
2026-07-12 debug build: pico/build-debug.sh
    HEAD=126d65d branch=main tree=dirty
    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
2026-07-12 debug build: pico/build-debug.sh
    HEAD=a362bde branch=main tree=dirty
    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
2026-07-12 debug build: pico/build-debug.sh
    HEAD=c5156a1 branch=main tree=dirty
    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
2026-07-16 Uthernet2: RECV/TX, MACRAW & ARP fixes
    Multiple fixes to the Pico Uthernet2 stack and related tooling: detect and self-heal creeping Sn_RX_RD by validating packet headers and resyncing after repeated impossible headers; use live Sn_RX_RD for accurate Sn_RX_RSR reporting and publish sn_rx_rd at RECV to avoid byte-order races; reset socket rings on OPEN to prevent unbounded RECV storms. Fix MACRAW issues: drop desynced/oversized TX frames instead of sending garbage, restore accurate Sn_TX_FSR reporting, add MAC filter for MF mode, and normalize ARP payload SHA so gateway replies reach the station. Improve send path: U2_Net_SendTcp now reports accepted bytes and clamps to tcp_sndbuf; UDP send c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
2026-07-16 Release V1.2.3-eo: add UF2s, bump firmware
    Add release artifacts for V1.2.3-eo: new pico/_releases/V1.2.3-eo/CHANGELOG.md and two megaflash UF2 binaries for Pico and Pico 2 W. Bump firmware version in pico/defines.h to 0x0023 and update FIRMW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
2026-09-03 Uthernet2: remove core-1 poll from the bus hot path (option B / §1cx)
    Core 1 was running U2_Poll() every 32 non-DATA bus cycles from BusLoop().
    The a2bus PIO serves a $C0C7 read from rxf_putget ~90 ns after nDEVSEL
    falls, so that work could make the 6502 latch the previous byte or let the
    4-deep listener FIFO drop the cycle, shifting the rest of the frame.
    - Delete the poll block and U2_Poll(); SEND/RECV already wake core 0 and
    PicoW_ServiceCore0IpcAndNetwork polls unconditionally.
    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
2026-09-03 docs: record §1cy-§1dc diagnostics, findings, and rollback
    - §1cz: the Debug build cannot measure bus timing or connectivity; its
    [u2m] flush blocks core 0 in 115200-baud printf and starves lwIP.
    - §1da/§1db-2: Release disables stdio_uart and gates the bus loop off
    whenever USB is connected, so diagnostics must go to UART.
    - §1db: first MF_BUS_DIAG capture closes H2 (prefetch turnaround):
    behind=0 over 38,807 $C0C7 reads. The PIO TX-FIFO rewrite is cancelled.
    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
2026-09-03 docs: correct U2_MON_FLUSH_MAX to 128 and log the option-B debug builds
    The constant in u2_monitor.c is 128, not the 48 recorded in §1cz, so the
    blocking-UART flush costs core 0 ~10 KB (~890 ms at 115200) per iteration
    rather than ~330 ms — about 2.7x worse than documented, and enough on its
    own to make Debug builds fail TCP connects.
    Also records the two option-B Debug images (stock and throttled), the new
    U2_MON_FLUSH_MAX / MF_UART_BAUD build knobs, and two build mistakes:
    PICO_DEFAULT_UART_BAUD_RATE is not visible in u2_monitor.c, and setting
    CMAKE_C_FLAGS replaces the SDK's architecture flags.
2026-09-03 Uthernet2: gated socket-0 8 KiB RX ring to test the wrap-boundary theory (§1dg)
    The periodic bad-checksum symptom is geometry, not a race. ip65 writes RMSR=0x0A,
    giving socket 0 a 4 KiB RX ring at 0x6000-0x6FFF. u2_push_rx_macraw wraps at the
    socket mask (0x7000 -> 0x6000), but auto_increment() only wraps at 0x6000/0x8000
    (AppleWin behaviour) -- there is no wrap at 0x7000. A host draining past 0x6FFF
    therefore reads on into socket 1's region instead of the wrapped frame tail, so one
    frame per 4 KiB received is delivered corrupt.
    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
2026-09-03 Uthernet2: drop the refuted 8 KiB experiment, add the RX delivery audit (§1dg refuted, §1dh)
    §1dg refuted by test. The -DU2_RX_SOCK0_8K=1 image was dramatically worse, not better:
    connections failed to establish or were reset by peer, and nothing completed. Under the
    hypothesis that ip65 relies on the chip's 0x8000 auto-wrap, forcing 8 KiB would have made
    both sides agree and cured it. It did the opposite, which proves the other branch: ip65
    splits its reads at the socket boundary itself, and our 4 KiB producer geometry already
    agreed with it. H3 is dead and the code is removed -- the knob was a footgun that bricks
    networking. The default was 0, so the shipped baseline was never affected.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
2026-09-03 optionB: add the pico2_w test images referenced by §1cx-§1dh
    SESSION_LOG.md and the implementation notes name these files directly, so track them
    alongside the other UF2s in the repo to keep the write-ups reproducible:
    megaflash-optionB-pico2w.uf2 clean §1cx baseline (known good)
    megaflash-optionB-DEBUG-stock-pico2w.uf2 Debug, stock monitor (§1de)
    megaflash-optionB-DEBUG-throttled-460800-pico2w.uf2 Debug, flush=8 @ 460800 (§1de)
    megaflash-optionB-RXAUDIT-pico2w.uf2 Release + U2_RX_AUDIT=1 (§1dh)
    The refuted §1dg 8 KiB image is deliberately absent; it produces a badly broken card.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
2026-09-03 Remove hwdiag; instrument the checksum bug and the browsing stall (§1di)
    hwdiag removed at the operator's request now that board bring-up is no longer critical:
    pico/hwdiag.{c,h} deleted and the hooks backed out of busloop.c, busloop_wa.c, slinky.c,
    main.c, CMakeLists.txt and docs/Debug-mode.md. Notes §25 collapsed to a removal record so
    the §1dd collision write-up still resolves.
    Instrumentation for two open symptoms, all under U2_RX_AUDIT and emitted as NDJSON over
    UART so a saved serial capture is directly usable as a debug log.
    H1/H2 (bad checksum every 3rd-6th packet): the existing served-vs-consumed audit, now with
    per-mismatch detail recorded by core 1 into a lock-free ring and p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
2026-09-04 Fix the instrumentation that broke detection; split H7 from H9 (§1dj)
    My §1di follow-up image caused "uthernet ii network device is not found" -- self-inflicted, and
    precisely the failure busloop.c already warns about for extra work on the $C0C7 read path,
    which must finish inside ~90 ns (roughly a dozen cycles at 150 MHz).
    The out-of-window branch I added, with a store and an atomic, was inlined into read_value on
    every DATA read. Measured on the ELF: baseline 9 instructions, the capture build 28 (+19),
    this rework 12 (+3). Working rule for this path: stay within a few instructions of baseline,
    and anything with a store, an atomic, or a second branch belongs somewhere else.
    H8 (accounti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
2026-09-04 Root cause: host reads 2 bytes past the RX ring end and consumes them (§1dk)
    Second audit capture (123 records, 424 socket-0 RECVs, ~380 s) came back with a perfect
    correlation at every sample across the whole run:
    hit_end == repoint == wrap_total == short
    ending at 8 == 8 == 8 == 8, with def2=8 and over=0. Every frame whose data crosses the ring end
    fails, and nothing else ever fails.
    The arithmetic closes: in-window reads (seen) + 2 out-of-window reads == advance ==
    frame_len + 2. The host issues exactly the right number of reads for the record, but two of
    them are served from 0x7000-0x7001 -- socket 1's region, which the producer never writes --
    while the two real bytes at the wrapp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
2026-09-04 Trace the pointer: repoint target rules out the wrap fix, read counter was blind (§1dl)
    The §1dk decider returned the unfavourable answer. The re-point target is ring_base + 0 on 3 of
    3 captures, which by §1dk's own criterion is the branch where wrapping auto_increment at the ring
    boundary is NOT the fix: the host would take the first two wrapped bytes at the boundary and then
    re-read those same two bytes after re-pointing to base, duplicating two bytes instead of losing
    two. The frame stays corrupt, just differently, so no fix is applied here.
    hit_end == repoint == wrap_total == short did reproduce exactly a third time (3/3/3/3, def2=3,
    over=0), so the structural finding stands. But §1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
2026-09-04 Trace caught a wrap: host reads 2 bytes past the ring end; trace both address regs (§1dm)
    The §1dl pointer trace froze around a real wrap and gave the first direct address evidence.
    Decoding the pointer targets (0x0426 Sn_RX_RSR, 0x0428 Sn_RX_RD, 0x0401 Sn_CR), the driver's
    per-frame loop is: point at Sn_RX_RSR and read 4 bytes (RSR plus RX_RD via auto-increment), point
    at the record in the ring, read the whole record in one burst, point at Sn_RX_RD and write it
    back, point at Sn_CR and issue RECV. Two non-wrapping frames in the same trace confirm it, each
    read as a single 786-byte burst, and the records tile exactly (2597 + 786 = 3383).
    On the wrapping frame the pointer goes to offset 3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
2026-09-04 Second wrap, same signature: host splits 2 bytes before its own pointer; trace Sn_RX_RD (§1dn)
    Tracing both address registers made the driver's loop legible. Pointer sets are always hi then lo,
    so the lo entry is the settled target, and per frame the driver points at Sn_RX_RSR, points at the
    record, reads the entire record including its 2-byte MACRAW header in one burst, writes Sn_RX_RD
    and issues RECV. Record starts tile exactly with the read counts (3413 +62, 3475 +65, 3540 +65,
    3605 +786, 295), confirming the pointer is the record start and the burst is the whole record.
    Tracing the high write paid off directly. On the wrap the burst ended with the address at 0x7002,
    so the hi write of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
2026-09-04 skew=0 clears our Sn_RX_RD; datasheet closes the wrap question; trace Sn_RX_RSR (§1do)
    The §1dn decider came back clean. At all three record starts the pointer the host writes equals
    our Sn_RX_RD masked to the ring: 2678/2678, 3464/3464, and 154 from a free-running rd of 4250. The
    third case also confirms Sn_RX_RD runs past the ring size with the host masking it, exactly as the
    datasheet specifies. The branch where our RD trails the record start by two is therefore rejected,
    and with it the idea that the fix lives in our RD accounting.
    With a third wrap captured the split formula is exact three times over: burst1 = 2 + (size -
    rd_off), giving 715/71, 493/293 and 634/152 against correct sp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
2026-09-04 Root cause: driver reads the MACRAW header outside its bytes-before-wrap budget (§1dp)
    Fourth wrap, and the smallest numbers yet make it plain. A 94-byte record at offset 4022 with
    rsr=603 and limit = 4096-4022 = 74 gives MIN(rsr,limit) = 74, so the correct split is 74/20. The
    host did 76/18, and burst1 = 2 + MIN(rsr,limit) is exact on all four captured wraps (715/71,
    493/293, 634/152, 76/18). The +2 is the MACRAW header every time.
    ip65's w5100_data_request returns MIN(Sn_RX_RSR, addr_limit - addr), the number of bytes readable
    before the caller must re-point. The caller reads the two-byte MACRAW header and then the full
    returned count, so it consumes 2 + limit bytes from a window only li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
2026-09-04 Fix: lay wrapping MACRAW records where the ip65/Contiki driver actually reads them (§1dq)
    Applying option 2 from §1dp. The corruption is the driver's, but no auto-increment behaviour can
    repair a displaced re-point target, so the only lever we hold is where the producer puts the bytes.
    On a straddling record the driver reads first+2 bytes contiguously from off0, running two past the
    ring end, and then re-points to ring offset 0 and reads the rest. Record bytes [0..first-1] stay
    where they were; bytes [first] and [first+1] now go to base+size and base+size+1, just past the
    ring, instead of ring offsets 0 and 1; and the remainder starts at ring offset 0 with byte
    [first+2]. Both of the driv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
2026-09-04 Log: first post-fix capture verifies §1dq at runtime
    Wrap at trace i=43-48 shows the record start at off=3918 with rsr=1696 and limit=178. The driver
    still did burst1 = 2 + limit = 180, then re-pointed to offset 0 and read 606, for a total of 786
    with rd advancing 3918 to 4704. That is unchanged driver behaviour, as expected since we changed
    where the bytes live rather than what it reads, but with the new layout the split now reconstructs
    the record exactly, and the next record landed at offset 608, which is (3918 + 786) & 4095 and
    precisely where the host's own pointer went at i=55.
    Counters are clean: wrap_total 2, short 0, def2 0, frames 96, ok 96, lost 0, over 0. Previously
    every wrap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
2026-09-04 Publish clean wrap-fix image without audit instrumentation
    Release, pico2_w, U2_RX_AUDIT=0, default UART baud, published as
    optionB/megaflash-optionB-WRAPFIX-pico2w.uf2. It carries the §1dq wrap fix and nothing else: nm
    reports zero u2_audit, u2_trc and RxAudit symbols against 24 in the audit build, and text drops
    from 727520 to 723852.
    Built because the audit instrumentation's periodic NDJSON printing starves core 0 enough that wget
    will not run, so the fix cannot be judged on its own terms while it is present. Removing it lets
    wget self-report whether checksum errors remain, which is the measurement that actually matters
    here. The instrumentation itself is untouched in the tree and still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
2026-09-04 Instrument the first-connection failure with a one-shot event trace (§1dr)
    New symptom, reported after the §1dq wrap fix but explicitly pre-existing, so it is a separate
    defect rather than a regression from the shim: the first connection after a socket OPEN always
    fails and an immediate retry always succeeds. Contiki recovers when the request is resubmitted;
    wget has no retry so it simply fails. Because wget does a full ip65 init on every run this is not
    first-OPEN-since-boot versus second, it is the first exchange after any OPEN, which points at
    something OPEN leaves cold that a single round trip warms up.
    Five hypotheses are instrumented. H11: ip65 writes SHAR after U2_Net_OpenMacraw ha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
2026-09-04 Fix MACRAW wrap checksums and first TCP connect for Uthernet II
    Allow the wrap-compat spill when neighbouring sockets are CLOSED (RMSR 0x06),
    remap Contiki sport 1026 with an incremental TCP checksum, and pad MACRAW TX
    to 60 bytes. Operator confirmed first-try connect and checksum errors resolved.
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2026-09-05 Fix first-connect after reboot with per-SYN ephemeral NAT
    A fixed 1026→41226 mapping reused the same 4-tuple across reboots, so the first SYN got no SYN-ACK while 1027/1028 worked. Map each 1026 SYN to a new ephemeral, drop FIRSTCONN UART, rebuild V1.2.4-eo, and remove optionB measurement UF2s.
2026-10-06 Implement W5100 socket-mode and build tracking
    Adds deferred W5100 TCP/UDP/IPRAW socket handling with Sn_IR/IMR support, stricter RX/TX flow control, and debug instrumentation for the a2stream crash path. It also updates the build scripts to stamp firmware versions with a monotonically increasing build number and documents the socket-mode behavior and Uthernet II notes.
2026-11-13 Uthernet II: SRAM-only bus path, bus audit tooling, LISTEN panic fix, link-hold; Pico 2 W only
